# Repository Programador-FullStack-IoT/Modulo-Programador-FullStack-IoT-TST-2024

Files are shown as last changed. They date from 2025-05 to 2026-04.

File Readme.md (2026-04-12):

## PROGRAMADOR FULLSTACK - GRUPO PLATA

(https://postimg.cc/dhYZY6cm)

# OmniSens – Sistema de Monitoreo y Control Ambiental Industrial

**OmniSens** es un sistema orientado al monitoreo y control ambiental en entornos industriales. Utiliza sensores para medir variables críticas como temperatura, humedad, presión y luminosidad, y transmite estos datos mediante tecnología **LoRa** hacia un servidor en la nube, permitiendo monitoreo y gestión en tiempo real.

---

## 🧑‍💻 Integrantes

| Nombre | GitHub |
|---|---|
| Fernando Gimenez Coria | [@FerCbr](https://github.com/FerCbr) |
| Paola Pantoja | [@PaolaaPantoja](https://github.com/PaolaaPantoja) |
| Diego Ares | [@diegote7](https://github.com/diegote7) |
| Emma Vilma Gutierrez | [@emygut](https://github.com/emygut) |
| Macarena Aylèn Carballo | [@MacarenaAC](https://github.com/MacarenaAC) |
| Romina Vanesa Huk | [@RoHu17](https://github.com/RoHu17) |
| Juan Diego Gonzalez Antoniazzi | [@JDGA1997](https://github.com/JDGA1997) |
| Leandro Roldan | [@pleroldan](https://github.com/pleroldan) |
| Raul Jara | [@r-j28](https://github.com/r-j28) |
---

## 👨‍🏫 Profesores

| Nombre                       |
|------------------------------|
| Mario Gonzalez               | 
| Jorge Morales                | 
| Ana Farias                   |
| Dante Violi                  |

## Descripción General

El objetivo principal de OmniSens es implementar un sistema integral capaz de mantener condiciones óptimas de ambiente, garantizando la seguridad y calidad del aire. Para ello, el sistema incluye una serie de **controladores edge** que reciben los datos de los sensores y accionan dispositivos como extractores de aire, luces, alarmas sonoras y balizas luminosas.  
Las acciones de los controladores edge buscan regular parámetros ambientales: por ejemplo, ajustar la velocidad de extractores/ventiladores, la intensidad de luces, o activar alarmas cuando los valores de gases o variables ambientales sobrepasen los límites establecidos.

Los controladores edge se comunican mediante un enlace LoRa hacia otro controlador encargado de funcionar como **nodo concentrador**, formando una red de tipo estrella.  
Este **nodo concentrador** envia a su vez todos datos recolectados a un **broker MQTT** remoto para su posterior analisis y almacenamiento. Esta arquitectura otorga la posibilidad de implementar analisis de datos a nivel de edge, permitiendo reaccionar a variables criticas con baja latencia, sin dejar de lado el procesamiento en la nube, que se encarga de almacenar todos los sucesos y tambien enviar ordenes a los controladores Edge.   

Toda la información recolectada se analiza en un servidor remoto y es almacenada en una base de datos configurada para este fin, luego se procede a mostrar la informacion en un dashboard. Este diseño permite visualizar la informacion procesada a vez que puese enviar ordenes automaticas o comandos indicados por el usuario.

## Objetivo del Proyecto

Desarrollar un sistema capaz de:
- Monitorear variables ambientales (temperatura, humedad, presión, luminosidad, gases) en tiempo real.
- Controlar dispositivos para mantener condiciones ambientales dentro de los parámetros de seguridad y calidad.
- Automatizar acciones correctivas (ventilación, iluminación, alarmas) ante condiciones anómalas.
- Registrar, almacenar y visualizar los datos históricos y en tiempo real para facilitar la toma de decisiones.

---

## Arquitectura del Sistema  

(https://postimg.cc/Bjz5Hy85)

El sistema está compuesto por:
- **Sensores ambientales**: Medición de variables críticas.  
- **Actuadores**: Dispositivos tales como Extractores/ventiladores, relay o contactores para comando on/off, balizas y alarmas sonoras
- **Microcontroladores Edge con LoRa**: Son los encargados de tomar la informacion de los sensores y procesar variables criticas que requieran baja latencia, ademas envian la informacion adquirida por enlace LoRa hacia el concentrador.
- **Concentrador Lora**: Controlador encargado de recibir los datos provenientes de los controladores Edge. Recibe la información y la envia por MQTT al **broker remoto**, ademas se encarga de ditribuir los comandos provenientes del servidor remoto hacia los **Controladores Edge** para accionar los actuadores.  
- **Servidor remoto**: Este servidor cumple las funciones de plataforma en la nube, cuenta con varios contenedores docker conectados en una red virtual. La lista de contenedores es la siguiente:  
    - **Broker MQTT**: recepcion de los datos provenientes del Edge y envio de comandos hacia los controladores edge  
    - **API**: Recibe los datos del broker MQTT y los procesa para autenticar y autorizar a los dispositivos y usuarios.  
    - **Node-red**: recibe los datos de la API y los procesa para analizar y tomar decisiones. Ademas, envía las reacciones a los actuadores a través de MQTT y almacena los datos y resultados de analisis en una base de datos.  
    - **Base de datos**: Aqui se almacena la informacion de los sensores, asi como los analisis realizados por Node-RED para su posterior visualizacion.  
    - **Grafana**: Grafana se utiliza para crear el dashboard encargado de mostrar los datos historicos y en tiempo real del sistema.
- **Interfaz web o dashboard**: Monitoreo y control centralizado.  

### Flujo de Datos

1. Los sensores captan variables ambientales.
2. Los datos viajan por LoRa a un microcontrolador concentrador, que se encarga a la vez de enviarlos por MQTT a un servidor remoto
3. El servidor analiza y devuelve ordenes para que los **Controladores Edge** accionen los actuadores.
4. El servidor almacena y muestra los datos en tiempo real, permitiendo monitoreo remoto y acciones automáticas.

---

## Estructura del Repositorio

```
OmniSens/
├── README.md
├── LICENSE
├── docs/
│   ├── architecture.md
│   ├── device-specs.md
│   ├── integration.md
│   └── roadmap.md
├── hub/
│   ├── backend/
│   └── frontend/
├── devices/
│   ├── sensores/
│   └── actuadores/
├── edge/
│   ├── microcontrolador-sensado/
│   ├── microcontrolador-receptor/
│   └── microcontrolador-actuador/
├── configs/
├── deployments/
└── tests/
```

---

## Integración y Escalabilidad

El proyecto está pensado para aprovechar y escalar a partir de prototipos y códigos de años anteriores, integrando nuevas funcionalidades y adaptándose a distintas necesidades industriales. Se fomenta la colaboración y la mejora continua.

---

## Hoja de Ruta (Roadmap)

El desarrollo de OmniSens se organiza en las siguientes fases:

### Fase 1: Prototipo Funcional de Sensado y Control
- [ ] Diseño y armado de red básica de sensores (temperatura, humedad, presión, luminosidad, gases).
- [ ] Configuración de comunicación LoRa entre microcontroladores (sensado, receptor y actuador).
- [ ] Implementación de control básico de actuadores (extractores, luces, alarmas).
- [ ] Documentación de arquitectura y conexiones en `docs/architecture.md`.

### Fase 2: Backend y Base de Datos
- [ ] Desarrollo del backend (`hub/backend/`) para recibir y almacenar datos.
- [ ] Configuración y pruebas de la base de datos.
- [ ] Documentación de la API y endpoints en `docs/integration.md`.

### Fase 3: Dashboard e Interfaz Web
- [ ] Desarrollo del frontend (`hub/frontend/`) para visualización y control.
- [ ] Implementación de monitoreo en tiempo real y registro histórico.
- [ ] Integración de acciones de control remoto desde el dashboard.

### Fase 4: Integración y Pruebas
- [ ] Integración de módulos (`edge`, `devices`, `hub`).
- [ ] Pruebas de funcionamiento en entorno simulado o real.
- [ ] Ajustes y mejoras tras feedback de pruebas.

### Fase 5: Documentación y Escalado
- [ ] Completar la documentación técnica en `docs/`.
- [ ] Publicar guías de instalación y uso para todos los módulos.
- [ ] Planificar siguientes iteraciones (nuevos sensores, protocolos, expansiones).

---
# Omnisens
---
## 🧭 1. Introducción y Problemática

**OmniSens** es un sistema de monitoreo y control ambiental industrial desarrollado por estudiantes del módulo **Programador FullStack IoT** del ISPC. Este proyecto integra tecnologías de hardware, software y comunicaciones para adquirir, almacenar, visualizar y actuar sobre datos ambientales críticos en tiempo real.

En entornos industriales, controlar variables como la **temperatura**, **humedad**, **presión atmosférica** y **luminosidad** es fundamental para garantizar la seguridad operativa, la eficiencia energética y el cumplimiento de normativas. Sin embargo, muchas industrias carecen de sistemas inteligentes que permitan:

- 📉 Monitoreo en tiempo real de las condiciones ambientales.
- ⚠️ Detección temprana de riesgos operativos.
- 📄 Registro y trazabilidad de datos históricos.
- 📊 Análisis automatizado y toma de decisiones basada en datos.
- 🚫 Evitar decisiones basadas en intuición o registros incompletos.

Ante este contexto, **OmniSens** surge como una solución tecnológica que permite:

- Capturar datos desde sensores distribuidos mediante nodos IoT (ESP32).
- Transmitir los datos a través de redes como **LoRa** y **WiFi** usando protocolos como **MQTT**.
- Almacenarlos de forma estructurada en una base de datos relacional.
- Visualizarlos y analizarlos en dashboards en tiempo real mediante herramientas como **Grafana** y **NodeRed**
- Generar alertas automáticas y activar actuadores ante condiciones críticas.

El proyecto busca resolver necesidades concretas del sector industrial, promoviendo el desarrollo de competencias profesionales como la integración de sistemas embebidos, la conectividad IoT, la gestión de datos y la visualización inteligente.

> "OmniSens nace para transformar datos ambientales en decisiones inteligentes, aportando valor real a la industria a través de la tecnología."

---
## 🧱 2. Diseño de Arquitectura IoT

El sistema OmniSens está basado en una arquitectura IoT distribuida y escalable, compuesta por sensores físicos, nodos de adquisición (ESP32), un gateway central, servicios backend y plataformas de visualización. Su diseño busca asegurar confiabilidad, modularidad y bajo consumo energético.

### 🔧 Componentes principales de la arquitectura:

- **Sensores ambientales**: capturan variables como temperatura, humedad, presión y luminosidad.
- **Microcontroladores ESP32**: actúan como nodos sensores, adquiriendo y transmitiendo los datos.
- **Red de comunicación**: se utilizan tecnologías inalámbricas como **LoRa** (para distancias largas y bajo consumo) y **WiFi** (para conectividad local con el servidor).
- **Broker MQTT**: intermedia la comunicación entre nodos y backend.
- **Servidor Backend**: recibe, valida y almacena los datos en una base relacional (MySQL/MariaDB).
- **Base de datos**: registra las mediciones por timestamp, dispositivo y variable.
- **Dashboard de visualización**: mediante **Grafana** o/y **Node-Red**, permite observar en tiempo real el estado ambiental.

---
### 🧩 Diagrama lógico de la arquitectura:

plaintext
[Sensores] 
    -> 
[ESP32 (Nodo Sensor)] 
    -> LoRa / WiFi 
[Gateway MQTT / Servidor] 
    -> 
[Base de Datos MySQL] 
    -> 
[Dashboard (Grafana / Power BI)]

---
## 🔧 3. Adquisición de Datos (ESP32 + Sensores)

La etapa de adquisición de datos en el sistema OmniSens se basa en la utilización de microcontroladores **ESP32**, que permiten la conexión directa con sensores ambientales y la recolección de datos físicos en tiempo real.

### 🔍 Variables monitoreadas:
- 🌡️ **Temperatura**
- 💧 **Humedad relativa**
- 🌀 **Presión atmosférica**
- 💡 **Luminosidad**
- 🕯️ **Concentracion de gases/ calidad de aire**

### 🛠️ Componentes utilizados:
- **Sensores digitales y analógicos**:
  - AHT25 → temperatura y humedad
  - BMP280 → presión y temperatura
  - LDR → luminosidad
  - MQ135 → Calidad de aire
    
- **Microcontrolador**:
  - ESP32 (con conectividad WiFi y/o LoRa)

### ⚙️ Flujo de funcionamiento:
1. Los sensores capturan datos del entorno físico.
2. El ESP32 lee las señales de los sensores a través de sus entradas GPIO.
3. El firmware del ESP32 convierte los datos a formato digital y los estructura en mensajes JSON.
4. Los datos se transmiten vía WiFi o LoRa hacia el backend o gateway.

### 🧪 Validación y pruebas realizadas:
- Lectura y calibración de cada sensor.
- Verificación del formato y frecuencia de los datos.
- Simulación de condiciones ambientales para validar variabilidad.
- Comprobación del consumo energético por nodo.

### 📌 Ventajas de usar ESP32:
- Bajo consumo energético.
- Capacidad de procesamiento local.
- Conectividad múltiple: WiFi, Bluetooth, LoRa (mediante módulos).
- Compatibilidad con entornos industriales y educativos.

> Esta etapa permite digitalizar el entorno físico y convertir condiciones ambientales en datos útiles, siendo el punto de partida del sistema de monitoreo y control de OmniSens.

---
## 📡 4. Comunicación Inalámbrica

La transmisión de datos en OmniSens se realiza mediante redes inalámbricas optimizadas para entornos industriales. Se utilizan dos tecnologías principales: **LoRa** y **WiFi**, complementadas por el protocolo **MQTT** para la mensajería entre dispositivos y el servidor.

### 🛰️ Tecnologías de comunicación utilizadas:

- **LoRa (Long Range)**:
  - Permite comunicación de largo alcance con bajo consumo energético.
  - Ideal para entornos con múltiples nodos distribuidos o con baja infraestructura de red.
  - Se utiliza principalmente entre nodos sensores y el nodo receptor (gateway).

- **WiFi**:
  - Usado en el nodo central para conectarse a internet y enviar los datos al backend.
  - Permite alta velocidad de transmisión y bajo retardo.

- **MQTT (Message Queuing Telemetry Transport)**:
  - Protocolo ligero ideal para IoT.
  - Permite que los dispositivos **publiquen** datos en un “topic” y que el servidor **se suscriba** para recibirlos.
  - Asegura eficiencia en redes de bajo ancho de banda y con múltiples dispositivos.

### 🔄 Flujo de comunicación:

[ESP32 Nodo Sensor]
  -> LoRa
[ESP32 Nodo Receptor / Gateway]
  -> MQTT sobre WiFi
[Broker MQTT]
  ->
[Servidor Backend]

---
## 🖥️ 5. Backend y Base de Datos

El backend del sistema OmniSens cumple un rol central en la recepción, validación, almacenamiento y organización de los datos ambientales enviados por los nodos sensores.

### 🔙 Funciones principales del backend:

- Recibir datos desde los nodos mediante MQTT.
- Validar formato, integridad y valores de los datos.
- Registrar eventos o comandos generados por el sistema.
- Almacenar toda la información en una base de datos relacional.
- Exponer APIs para futuras integraciones con dashboards u otros servicios.

### 🗄️ Modelo de Base de Datos Relacional

Se diseñó una base de datos optimizada para registrar información ambiental por dispositivo y variable. Las tablas principales son:

| Tabla | Propósito |
|---|---|
| `devices` | Registra cada ESP32 con su ID, tipo y ubicación. |
| `sensor_data` | Almacena las mediciones de variables con timestamp. |
| `commands_log` | Guarda las acciones o respuestas generadas por el sistema (automatizaciones). |
| `alerts` *(opcional)* | Registra alertas generadas por condiciones críticas. |

#### 🔗 Relaciones entre tablas:
- `devices.device_id` → se relaciona con `sensor_data.device_id` y `commands_log.device_id`
- `sensor_data.id` → puede relacionarse con `alerts.sensor_data_id`

### 📈 Ventajas del diseño:

- Escalable a nuevos sensores y tipos de variables.
- Compatible con visualizadores como Grafana y Node-Red.
- Preparado para trazabilidad, alertas y análisis histórico.

> Este backend permite que los datos ambientales capturados por los sensores se conviertan en información estructurada, confiable y accesible para su posterior visualización y análisis.

---
## 📊 6. Visualización Web / Dashboard

La visualización de datos es el paso final del sistema OmniSens, donde la información almacenada en la base de datos es transformada en gráficos, paneles e indicadores comprensibles para facilitar la toma de decisiones.

### 📊 Integración con Node-RED y Grafana

### Node-RED
* Permite crear flujos lógicos para procesar, transformar y reenviar datos provenientes de sensores conectados vía MQTT.

🔧 Funcionalidades implementadas

* Recepción de datos desde ESP32 por MQTT.
* Filtrado y reenvío de datos a MariaDB.
* Reglas de control automático
* Flujo: MQTT → procesamiento → UI → actuador.
* Ruta: `/nodered_plata/ui/`: [Dashboard UI](http://telecomunicaciones.ddns.net:8080/nodered_plata/ui/#!/0)
* Incluye botones para control manual, recepción de datos, lógica de automatización.

### Grafana

* Plataforma de visualización en tiempo real, conectada directamente a la base de datos MariaDB.
* Dashboards visuales conectados a base de datos.
* Panel con temperatura, gas, humedad y estado de actuadores.
* Ruta directa:
  [Dashboard público](http://telecomunicaciones.ddns.net:8080/grafana/public-dashboards/edbcf99f6c3e44a68703f5246ecef087)

---

### 🧭 Objetivos de la visualización:

- Representar variables ambientales críticas de forma clara y dinámica.
- Permitir monitoreo en tiempo real de sensores distribuidos.
- Detectar tendencias, anomalías o condiciones fuera de rango.
- Mejorar el mantenimiento, la eficiencia energética y la seguridad operativa.
- Facilitar el análisis por parte de diferentes perfiles de usuarios (técnicos, operativos, directivos).

### 🧱 Estructura del panel:

El dashboard se organiza en múltiples secciones:

1. **Vista general de variables**:
   - Temperatura, humedad, presión y luminosidad por dispositivo.
   - Estado actual, valores máximos y mínimos recientes.
2. **Medicion por eventos de valores en crudo**:
3. **Conteo de cantidad de dispositivos**:
4. **Históricos y tendencias**:
5. **Estado de sensores y actuadores**:
6. **Promedios** 
7. **Actividad de los reles**
8. **Identificador de dispositivos**

> La visualización convierte datos técnicos en información útil y clara, permitiendo interpretar el comportamiento ambiental y tomar decisiones informadas en entornos industriales.

---
## 🤖 7. Automatización y Control (Actuadores)

Además de monitorear el ambiente, el sistema OmniSens es capaz de **actuar automáticamente** ante condiciones críticas, gracias a la integración de actuadores controlados desde el backend o en forma autónoma por los nodos.

### ⚙️ Objetivos del control automatizado:

- Generar respuestas inmediatas ante variables fuera de rango.
- Activar dispositivos que mejoren las condiciones ambientales.
- Reducir la necesidad de intervención humana.
- Aumentar la seguridad y eficiencia operativa.

### 🔌 Tipos de actuadores posibles:

- 🌀 Ventiladores / extractores de aire.
- 💡 Luces de advertencia o balizas.
- 🔔 Alarmas sonoras.
- 💧 Válvulas o bombas de agua.
- 🌡️ Aire acondicionado o calefactores.

### 🔁 Lógica de automatización:

El sistema puede actuar de dos formas:

#### 1. **Automatización local en ESP32** (Opcional. no se implemento): 
- El ESP32 analiza el dato leído y, si supera un umbral, activa directamente el actuador conectado.
- Ejemplo: si `temperatura > 30°C`, activar ventilador.

#### 2. **Automatización centralizada desde el backend**:
- El servidor recibe los datos y decide activar o no un actuador según reglas definidas.
- Se envía un comando vía MQTT al nodo actuador correspondiente.

### 🗂️ Registro de acciones:

- Cada acción ejecutada se guarda en la tabla `commands_log`, con información como:
  - `device_id`
  - `command` (ej. "ON", "OFF")
  - `timestamp`
  - `status`

### 🧪 Validación y pruebas:

- Ensayos de latencia entre detección y acción.
- Pruebas con sensores simulados y actuadores reales.
- Comprobación de fallos: qué ocurre si el actuador no responde.

> La automatización convierte al sistema en una herramienta activa, no solo de monitoreo, sino también de respuesta inteligente ante condiciones que afectan el ambiente de trabajo.

---
## 📅 8. Cronograma y Proceso de Desarrollo

El desarrollo del proyecto OmniSens se organizó en etapas, siguiendo una planificación basada en objetivos específicos y acciones técnicas. Esto permitió avanzar de forma progresiva, validando cada componente del sistema antes de integrarlo.

### 📌 Organización por semanas

| Etapa | Objetivo principal | Acciones realizadas |
|---|---|---|
| **Etapa 1** | Diseñar la arquitectura | - Análisis de necesidades del sistema<br>- Selección de topología IoT<br>- Definición de roles: sensores, nodos, gateway, servidor<br>- Primeros diagramas de arquitectura |
| **Etapa  2** | Adquisición de datos | - Conexión de sensores al ESP32<br>- Programación de firmware básico<br>- Pruebas de lectura y calibración<br>- Validación de datos físicos |
| **Etapa  3** | Comunicación inalámbrica | - Configuración de red LoRa y WiFi<br>- Implementación de MQTT/<br>- Pruebas de transmisión nodo → servidor<br>- Ajustes de cobertura y latencia |
| **Etapa  4** | Backend y base de datos | - Diseño de la base de datos relacional<br>- Creación de APIs de recepción<br>- Almacenamiento de datos desde nodos<br>- Gestión de errores y alertas |
| **Etapa  5** | Visualización y pruebas finales | - Diseño del dashboard (Grafana / Node-Red)<br>- Conexión al backend y base de datos<br>- Visualización de datos en tiempo real<br>- Revisión, ajustes y documentación final |

### 🛠️ Metodología aplicada:

- Trabajo colaborativo entre 9 integrantes, con roles distribuidos.
- Validación continua en cada etapa (sensado, transmisión, backend, visualización).
- Uso de control de versiones (GitHub) para gestionar avances y código.
- Documentación técnica elaborada de forma simultánea al desarrollo.

### 📈 Resultados destacados:

- Se logró un sistema funcional y escalable.
- Todas las etapas del ciclo de vida de los datos fueron cubiertas: captura, transmisión, almacenamiento, análisis y visualización.
- Se presentaron avances periódicos en cada instancia del módulo FullStack IoT.

> El trabajo organizado y en equipo fue clave para alcanzar un producto sólido, demostrando competencias técnicas y metodológicas aplicadas al desarrollo de sistemas IoT reales.

---
## ✅ 9. Conclusión, Aplicaciones y Cierre

OmniSens es el resultado de un trabajo colaborativo y multidisciplinario que integra tecnologías de IoT, comunicaciones, desarrollo de software y análisis de datos para resolver una problemática concreta del ámbito industrial: la necesidad de monitorear y controlar variables ambientales de forma precisa y en tiempo real, optimizando el sistema, brindando soluciones reales ejecutando acciones o actividades   lo mas desatendidas y seguras posibles. 

### 🎯 Logros alcanzados:

- Desarrollo de un sistema completo y funcional.
- Integración de sensores físicos y nodos ESP32 con conectividad LoRa/WiFi.
- Implementación de un backend capaz de recibir, validar y almacenar datos.
- Construcción de dashboards interactivos para visualización en tiempo real.
- Automatización de respuestas ante condiciones críticas.
- Trabajo en equipo con documentación técnica, planificación y uso de herramientas profesionales.

### 🏭 Posibles aplicaciones reales:

- **Industria manufacturera**: monitoreo ambiental en líneas de producción.
- **Centros educativos o de investigación**: como plataforma de aprendizaje IoT.
- **Agricultura inteligente**: control ambiental en invernaderos o hidroponía.
- **Municipios**: estaciones ambientales urbanas para políticas públicas.
- **Cooperativas o pymes**: bajo costo, alta utilidad para la toma de decisiones.

### 🌱 Impacto del proyecto:

- Promueve la **conciencia ambiental industrial**.
- Desarrolla habilidades reales del perfil técnico FullStack IoT.
- Facilita la **transferencia tecnológica** a contextos locales.
- Aporta una solución escalable, replicable y con impacto social.

### 🧠 Reflexión final:

> “OmniSens no solo mide condiciones ambientales. Permite que la industria tome decisiones más inteligentes, eficientes y sostenibles. Nos permitió aplicar conocimientos concretos de arquitectura IoT, plataformas web, sistemas de control y gestión de datos, demostrando cómo la tecnología puede mejorar entornos reales.”

---
## Licencia

Este proyecto se encuentra bajo la Licencia MIT. Consulta el archivo LICENSE para más detalles.

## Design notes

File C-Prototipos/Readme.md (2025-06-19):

## PROGRAMADOR FULLSTACK - GRUPO PLATA

(https://postimg.cc/dhYZY6cm)

# OmniSens – Sistema de Monitoreo y Control Ambiental Industrial

**OmniSens** es un sistema orientado al monitoreo y control ambiental en entornos industriales. Utiliza sensores para medir variables críticas como temperatura, humedad, presión y luminosidad, y transmite estos datos mediante tecnología **LoRa** hacia un servidor en la nube, permitiendo monitoreo y gestión en tiempo real.

---

## 🧑‍💻 Integrantes

| Nombre | GitHub |
|---|---|
| Fernando Gimenez Coria | [@FerCbr](https://github.com/FerCbr) |
| Paola Pantoja | [@PaolaaPantoja](https://github.com/PaolaaPantoja) |
| Diego Ares | [@diegote7](https://github.com/diegote7) |
| Emma Vilma Gutierrez | [@emygut](https://github.com/emygut) |
| Macarena Aylèn Carballo | [@MacarenaAC](https://github.com/MacarenaAC) |
| Romina Vanesa Huk | [@RoHu17](https://github.com/RoHu17) |
| Juan Diego Gonzalez Antoniazzi | [@JDGA1997](https://github.com/JDGA1997) |
| Leandro Roldan | [@pleroldan](https://github.com/pleroldan) |
| Raul Jara | [@r-j28](https://github.com/r-j28) |
---

## 👨‍🏫 Profesores

| Nombre | GitHub |
|---|---|
| Mario Gonzalez | [@mariogonzalezispc](https://github.com/mariogonzalezispc) |
| Jorge Morales | [@JorEl057](https://github.com/JorEl057) |
| Alejandro Mainero | []() |

## Descripción General

El objetivo principal de OmniSens es implementar un sistema integral capaz de mantener condiciones óptimas de ambiente, garantizando la seguridad y calidad del aire. Para ello, el sistema incluye una serie de **controladores edge** que reciben los datos de los sensores y accionan dispositivos como extractores de aire, luces, alarmas sonoras y balizas luminosas.  
Las acciones de los controladores edge buscan regular parámetros ambientales: por ejemplo, ajustar la velocidad de extractores/ventiladores, la intensidad de luces, o activar alarmas cuando los valores de gases o variables ambientales sobrepasen los límites establecidos.

Los controladores edge se comunican mediante un enlace LoRa hacia otro controlador encargado de funcionar como **nodo concentrador**, formando una red de tipo estrella.  
Este **nodo concentrador** envia a su vez todos datos recolectados a un **broker MQTT** remoto para su posterior analisis y almacenamiento. Esta arquitectura otorga la posibilidad de implementar analisis de datos a nivel de edge, permitiendo reaccionar a variables criticas con baja latencia, sin dejar de lado el procesamiento en la nube, que se encarga de almacenar todos los sucesos y tambien enviar ordenes a los controladores Edge.   

Toda la información recolectada se analiza en un servidor remoto y es almacenada en una base de datos configurada para este fin, luego se procede a mostrar la informacion en un dashboard. Este diseño permite visualizar la informacion procesada a su vez que puede enviar ordenes automaticas o comandos indicados por el usuario.

El proyecto busca aprovechar prototipos y desarrollos previos, adaptando y escalando el enfoque hacia la gestión ambiental industrial. Además, se promueve el trabajo colaborativo y la comunicación de avances con los profesores para su evaluación.

---
## 🧭 1. Introducción y Problemática

**OmniSens** es un sistema de monitoreo y control ambiental industrial desarrollado por estudiantes del módulo **Programador FullStack IoT** del ISPC. Este proyecto integra tecnologías de hardware, software y comunicaciones para adquirir, almacenar, visualizar y actuar sobre datos ambientales críticos en tiempo real.

En entornos industriales, controlar variables como la **temperatura**, **humedad**, **presión atmosférica** y **luminosidad** es fundamental para garantizar la seguridad operativa, la eficiencia energética y el cumplimiento de normativas. Sin embargo, muchas industrias carecen de sistemas inteligentes que permitan:

- 📉 Monitoreo en tiempo real de las condiciones ambientales.
- ⚠️ Detección temprana de riesgos operativos.
- 📄 Registro y trazabilidad de datos históricos.
- 📊 Análisis automatizado y toma de decisiones basada en datos.
- 🚫 Evitar decisiones basadas en intuición o registros incompletos.

Ante este contexto, **OmniSens** surge como una solución tecnológica que permite:

- Capturar datos desde sensores distribuidos mediante nodos IoT (ESP32).
- Transmitir los datos a través de redes como **LoRa** y **WiFi** usando protocolos como **MQTT**.
- Almacenarlos de forma estructurada en una base de datos relacional.
- Visualizarlos y analizarlos en dashboards en tiempo real mediante herramientas como **Grafana** y **NodeRed**
- Generar alertas automáticas y activar actuadores ante condiciones críticas.

El proyecto busca resolver necesidades concretas del sector industrial, promoviendo el desarrollo de competencias profesionales como la integración de sistemas embebidos, la conectividad IoT, la gestión de datos y la visualización inteligente.

> "OmniSens nace para transformar datos ambientales en decisiones inteligentes, aportando valor real a la industria a través de la tecnología."

---
## 🧱 2. Diseño de Arquitectura IoT

El sistema OmniSens está basado en una arquitectura IoT distribuida y escalable, compuesta por sensores físicos, nodos de adquisición (ESP32), un gateway central, servicios backend y plataformas de visualización. Su diseño busca asegurar confiabilidad, modularidad y bajo consumo energético.

### 🔧 Componentes principales de la arquitectura:

- **Sensores ambientales**: capturan variables como temperatura, humedad, presión y luminosidad.
- **Microcontroladores ESP32**: actúan como nodos sensores, adquiriendo y transmitiendo los datos.
- **Red de comunicación**: se utilizan tecnologías inalámbricas como **LoRa** (para distancias largas y bajo consumo) y **WiFi** (para conectividad local con el servidor).
- **Broker MQTT**: intermedia la comunicación entre nodos y backend.
- **Servidor Backend**: recibe, valida y almacena los datos en una base relacional (MySQL/MariaDB).
- **Base de datos**: registra las mediciones por timestamp, dispositivo y variable.
- **Dashboard de visualización**: mediante **Grafana** o/y **Node-Red**, permite observar en tiempo real el estado ambiental.

---
### 🧩 Diagrama lógico de la arquitectura:

plaintext
[Sensores] 
    ↓ 
[ESP32 (Nodo Sensor)] 
    ↓ LoRa / WiFi 
[Gateway MQTT / Servidor] 
    ↓ 
[Base de Datos MySQL] 
    ↓ 
[Dashboard (Grafana / Power BI)]

---
## 🔧 3. Adquisición de Datos (ESP32 + Sensores)

La etapa de adquisición de datos en el sistema OmniSens se basa en la utilización de microcontroladores **ESP32**, que permiten la conexión directa con sensores ambientales y la recolección de datos físicos en tiempo real.

### 🔍 Variables monitoreadas:
- 🌡️ **Temperatura**
- 💧 **Humedad relativa**
- 🌀 **Presión atmosférica**
- 💡 **Luminosidad**

### 🛠️ Componentes utilizados:
- **Sensores digitales y analógicos**:
  - DHT11 → temperatura y humedad
  - BMP280 → presión
  - BH1750 → luminosidad
- **Microcontrolador**:
  - ESP32 (con conectividad WiFi y/o LoRa)

### ⚙️ Flujo de funcionamiento:
1. Los sensores capturan datos del entorno físico.
2. El ESP32 lee las señales de los sensores a través de sus entradas GPIO.
3. El firmware del ESP32 convierte los datos a formato digital y los estructura en mensajes JSON.
4. Los datos se transmiten vía WiFi o LoRa hacia el backend o gateway.

### 🧪 Validación y pruebas realizadas:
- Lectura y calibración de cada sensor.
- Verificación del formato y frecuencia de los datos.
- Simulación de condiciones ambientales para validar variabilidad.
- Comprobación del consumo energético por nodo.

### 📌 Ventajas de usar ESP32:
- Bajo consumo energético.
- Capacidad de procesamiento local.
- Conectividad múltiple: WiFi, Bluetooth, LoRa (mediante módulos).
- Compatibilidad con entornos industriales y educativos.

> Esta etapa permite digitalizar el entorno físico y convertir condiciones ambientales en datos útiles, siendo el punto de partida del sistema de monitoreo y control de OmniSens.

---
## 📡 4. Comunicación Inalámbrica

La transmisión de datos en OmniSens se realiza mediante redes inalámbricas optimizadas para entornos industriales. Se utilizan dos tecnologías principales: **LoRa** y **WiFi**, complementadas por el protocolo **MQTT** para la mensajería entre dispositivos y el servidor.

### 🛰️ Tecnologías de comunicación utilizadas:

- **LoRa (Long Range)**:
  - Permite comunicación de largo alcance con bajo consumo energético.
  - Ideal para entornos con múltiples nodos distribuidos o con baja infraestructura de red.
  - Se utiliza principalmente entre nodos sensores y el nodo receptor (gateway).

- **WiFi**:
  - Usado en el nodo central para conectarse a internet y enviar los datos al backend.
  - Permite alta velocidad de transmisión y bajo retardo.

- **MQTT (Message Queuing Telemetry Transport)**:
  - Protocolo ligero ideal para IoT.
  - Permite que los dispositivos **publiquen** datos en un “topic” y que el servidor **se suscriba** para recibirlos.
  - Asegura eficiencia en redes de bajo ancho de banda y con múltiples dispositivos.

### 🔄 Flujo de comunicación:

plaintext
[ESP32 Nodo Sensor]
  ↓ LoRa
[ESP32 Nodo Receptor / Gateway]
  ↓ MQTT sobre WiFi
[Broker MQTT]
  ↓
[Servidor Backend]

---
## 🖥️ 5. Backend y Base de Datos

El backend del sistema OmniSens cumple un rol central en la recepción, validación, almacenamiento y organización de los datos ambientales enviados por los nodos sensores.

### 🔙 Funciones principales del backend:

- Recibir datos desde los nodos mediante HTTP o MQTT.
- Validar formato, integridad y valores de los datos.
- Registrar eventos o comandos generados por el sistema.
- Almacenar toda la información en una base de datos relacional.
- Exponer APIs para futuras integraciones con dashboards u otros servicios.

### 🧩 Arquitectura del backend:

- **Lenguaje/entorno**: Node.js
- **Servidor web/API**: Express
- **Base de datos**: MariaDB / MySQL
- **Gestión de datos**: Sequelize u ORM nativo
- **Contenedores**: Docker (opcional, según implementación)

### 🗄️ Modelo de Base de Datos Relacional

Se diseñó una base de datos optimizada para registrar información ambiental por dispositivo y variable. Las tablas principales son:

| Tabla | Propósito |
|---|---|
| `devices` | Registra cada ESP32 con su ID, tipo y ubicación. |
| `sensor_data` | Almacena las mediciones de variables con timestamp. |
| `commands_log` | Guarda las acciones o respuestas generadas por el sistema (automatizaciones). |
| `alerts` *(opcional)* | Registra alertas generadas por condiciones críticas. |

#### 🔗 Relaciones entre tablas:
- `devices.device_id` → se relaciona con `sensor_data.device_id` y `commands_log.device_id`
- `sensor_data.id` → puede relacionarse con `alerts.sensor_data_id`

### 🧪 Validaciones implementadas:

- Comprobación de rangos válidos (ej.: temperatura entre -40 °C y 85 °C).
- Eliminación de registros duplicados.
- Control de campos nulos o mal formateados.
- Registro de errores y eventos especiales.

### 📈 Ventajas del diseño:

- Escalable a nuevos sensores y tipos de variables.
- Compatible con visualizadores como Grafana y Power BI.
- Preparado para trazabilidad, alertas y análisis histórico.

> Este backend permite que los datos ambientales capturados por los sensores se conviertan en información estructurada, confiable y accesible para su posterior visualización y análisis.

---
## 📊 6. Visualización Web / Dashboard

La visualización de datos es el paso final del sistema OmniSens, donde la información almacenada en la base de datos es transformada en gráficos, paneles e indicadores comprensibles para facilitar la toma de decisiones.

## 📊 Integración con Node-RED y Grafana

### Node-RED

* Flujo: MQTT → procesamiento → UI → actuador.
* Ruta: `/nodered_plata/ui/`: [Dashboard UI](http://telecomunicaciones.ddns.net:8080/nodered_plata/ui/#!/0)
* Incluye botones para control manual, recepción de datos, lógica de automatización.

### Grafana

* Plataforma de visualización en tiempo real, conectada directamente a la base de datos MySQL.
* Dashboards visuales conectados a base de datos.
* Panel con temperatura, gas, humedad y estado de actuadores.
* Ruta directa:
  [Dashboard público](http://telecomunicaciones.ddns.net:8080/grafana/public-dashboards/edbcf99f6c3e44a68703f5246ecef087)

---

### 🧭 Objetivos de la visualización:

- Representar variables ambientales críticas de forma clara y dinámica.
- Permitir monitoreo en tiempo real de sensores distribuidos.
- Detectar tendencias, anomalías o condiciones fuera de rango.
- Mejorar el mantenimiento, la eficiencia energética y la seguridad operativa.
- Facilitar el análisis por parte de diferentes perfiles de usuarios (técnicos, operativos, directivos).

### 🧱 Estructura del panel:

El dashboard se organiza en múltiples secciones:

1. **Vista general de variables**:
   - Temperatura, humedad, presión y luminosidad por dispositivo.
   - Estado actual, valores máximos y mínimos recientes.

2. **Panel comparativo por sectores o nodos**:
   - Comparación de valores entre ubicaciones o dispositivos.

3. **Alertas y condiciones críticas**:
   - Visualización de alertas activas por umbrales excedidos.

4. **Históricos y tendencias**:
   - Gráficos de evolución temporal de cada variable.
   - Filtros por fecha, nodo o variable.

5. **Indicadores clave (KPIs)**:
   - Promedios, máximos/mínimos diarios.
   - Cantidad de alertas, condiciones óptimas mantenidas, etc.

### 🔗 Conexión de datos:

- **Grafana**: se conecta directamente a la base MySQL mediante consultas SQL configuradas por variable y tabla.
- **Power BI**: importa los datos desde MySQL o desde archivos exportados, permitiendo modelado, limpieza y relaciones personalizadas.

> La visualización convierte datos técnicos en información útil y clara, permitiendo interpretar el comportamiento ambiental y tomar decisiones informadas en entornos industriales.

---
## 🤖 7. Automatización y Control (Actuadores)

Además de monitorear el ambiente, el sistema OmniSens es capaz de **actuar automáticamente** ante condiciones críticas, gracias a la integración de actuadores controlados desde el backend o en forma autónoma por los nodos.

### ⚙️ Objetivos del control automatizado:

- Generar respuestas inmediatas ante variables fuera de rango.
- Activar dispositivos que mejoren las condiciones ambientales.
- Reducir la necesidad de intervención humana.
- Aumentar la seguridad y eficiencia operativa.

### 🔌 Tipos de actuadores posibles:

- 🌀 Ventiladores / extractores de aire.
- 💡 Luces de advertencia o balizas.
- 🔔 Alarmas sonoras.
- 💧 Válvulas o bombas de agua.
- 🌡️ Aire acondicionado o calefactores.

### 🔁 Lógica de automatización:

El sistema puede actuar de dos formas:

#### 1. **Automatización local en ESP32**:
- El ESP32 analiza el dato leído y, si supera un umbral, activa directamente el actuador conectado.
- Ejemplo: si `temperatura > 30°C`, activar ventilador.

#### 2. **Automatización centralizada desde el backend**:
- El servidor recibe los datos y decide activar o no un actuador según reglas definidas.
- Se envía un comando vía MQTT/HTTP al nodo actuador correspondiente.

### 🗂️ Registro de acciones:

- Cada acción ejecutada se guarda en la tabla `commands_log`, con información como:
  - `device_id`
  - `command` (ej. "ON", "OFF")
  - `timestamp`
  - `status`

### 🧪 Validación y pruebas:

- Ensayos de latencia entre detección y acción.
- Pruebas con sensores simulados y actuadores reales.
- Comprobación de fallos: qué ocurre si el actuador no responde.

### 🔒 Seguridad:

- Se pueden establecer reglas para evitar activaciones innecesarias.
- Control de prioridad y bloqueo si hay condiciones simultáneas.

> La automatización convierte al sistema en una herramienta activa, no solo de monitoreo, sino también de respuesta inteligente ante condiciones que afectan el ambiente de trabajo.

---
## 📅 8. Cronograma y Proceso de Desarrollo

El desarrollo del proyecto OmniSens se organizó en etapas semanales, siguiendo una planificación basada en objetivos específicos y acciones técnicas. Esto permitió avanzar de forma progresiva, validando cada componente del sistema antes de integrarlo.

### 📌 Organización por semanas

| Semana | Objetivo principal | Acciones realizadas |
|---|---|---|
| **Semana 1** | Diseñar la arquitectura | - Análisis de necesidades del sistema<br>- Selección de topología IoT<br>- Definición de roles: sensores, nodos, gateway, servidor<br>- Primeros diagramas de arquitectura |
| **Semana 2** | Adquisición de datos | - Conexión de sensores al ESP32<br>- Programación de firmware básico<br>- Pruebas de lectura y calibración<br>- Validación de datos físicos |
| **Semana 3** | Comunicación inalámbrica | - Configuración de red LoRa y WiFi<br>- Implementación de MQTT/HTTP<br>- Pruebas de transmisión nodo → servidor<br>- Ajustes de cobertura y latencia |
| **Semana 4** | Backend y base de datos | - Diseño de la base de datos relacional<br>- Creación de APIs de recepción<br>- Almacenamiento de datos desde nodos<br>- Gestión de errores y alertas |
| **Semana 5** | Visualización y pruebas finales | - Diseño del dashboard (Grafana / Power BI)<br>- Conexión al backend y base de datos<br>- Visualización de datos en tiempo real<br>- Revisión, ajustes y documentación final |

### 🛠️ Metodología aplicada:

- Trabajo colaborativo entre 9 integrantes, con roles distribuidos.
- Validación continua en cada etapa (sensado, transmisión, backend, visualización).
- Uso de control de versiones (GitHub) para gestionar avances y código.
- Documentación técnica elaborada de forma simultánea al desarrollo.

### 📈 Resultados destacados:

- Se logró un sistema funcional y escalable.
- Todas las etapas del ciclo de vida de los datos fueron cubiertas: captura, transmisión, almacenamiento, análisis y visualización.
- Se presentaron avances periódicos en cada instancia del módulo FullStack IoT.

> El trabajo organizado y en equipo fue clave para alcanzar un producto sólido, demostrando competencias técnicas y metodológicas aplicadas al desarrollo de sistemas IoT reales.

---
## ✅ 9. Conclusión, Aplicaciones y Cierre

OmniSens es el resultado de un trabajo colaborativo y multidisciplinario que integra tecnologías de IoT, comunicaciones, desarrollo de software y análisis de datos para resolver una problemática concreta del ámbito industrial: la necesidad de monitorear y controlar variables ambientales de forma precisa y en tiempo real.

### 🎯 Logros alcanzados:

- Desarrollo de un sistema completo y funcional.
- Integración de sensores físicos y nodos ESP32 con conectividad LoRa/WiFi.
- Implementación de un backend capaz de recibir, validar y almacenar datos.
- Construcción de dashboards interactivos para visualización en tiempo real.
- Automatización de respuestas ante condiciones críticas.
- Trabajo en equipo con documentación técnica, planificación y uso de herramientas profesionales.

### 🏭 Posibles aplicaciones reales:

- **Industria manufacturera**: monitoreo ambiental en líneas de producción.
- **Centros educativos o de investigación**: como plataforma de aprendizaje IoT.
- **Agricultura inteligente**: control ambiental en invernaderos o hidroponía.
- **Municipios**: estaciones ambientales urbanas para políticas públicas.
- **Cooperativas o pymes**: bajo costo, alta utilidad para la toma de decisiones.

### 🌱 Impacto del proyecto:

- Promueve la **conciencia ambiental industrial**.
- Desarrolla habilidades reales del perfil técnico FullStack IoT.
- Facilita la **transferencia tecnológica** a contextos locales.
- Aporta una solución escalable, replicable y con impacto social.

### 🧠 Reflexión final:

> “OmniSens no solo mide condiciones ambientales. Permite que la industria tome decisiones más inteligentes, eficientes y sostenibles. Nos permitió aplicar conocimientos concretos de arquitectura IoT, plataformas web, sistemas de control y gestión de datos, demostrando cómo la tecnología puede mejorar entornos reales.”

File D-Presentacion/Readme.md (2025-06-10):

# OmniSens: Plataforma de Monitoreo Ambiental IoT



OmniSens es una plataforma integral de monitoreo ambiental basada en IoT, diseñada para recolectar, almacenar y visualizar datos de diversos sensores. La plataforma está compuesta por dispositivos de borde (nodos sensores), un concentrador LoRa, una API de backend, una base de datos y un panel de visualización en Grafana.

Este proyecto ha sido desarrollado como parte del Módulo Full Stack IoT de la Tecnicatura Superior en Telecomunicaciones del ISPC.

---

## 📜 Tabla de Contenidos

1.  [📝 Resumen del Proyecto](#-resumen-del-proyecto)
2.  [🚀 Estado del Proyecto](#-estado-del-proyecto)
3.  [🛠️ Tecnologias Utilizadas](#-tecnologias-utilizadas)
4.  [📋 Requisitos Previos](#-requisitos-previos)
5.  [⚙️ Instalación](#-instalación)
6.  [🔧 Configuración](#-configuración)
7.  [▶️ Uso](#-uso)
8.  [🔌 Referencia de la API](#-referencia-de-la-api)
9. [🤝 Cómo Contribuir](#-cómo-contribuir)

---

## 📝 Resumen del Proyecto

El proyecto OmniSens tiene como objetivo principal monitorear la calidad del aire y otras variables ambientales utilizando una red de sensores IoT. Los datos son transmitidos a través de LoRa a un concentrador que los envía a un backend mediante MQTT. Finalmente, la información se almacena en una base de datos MySQL y se visualiza en tiempo real en un dashboard de Grafana.

### Características Principales

* **Comunicación Inalámbrica de Largo Alcance:** Utiliza LoRa para la comunicación entre los nodos sensores y el concentrador.
* **Protocolo Ligero:** Emplea MQTT para una comunicación eficiente entre el hardware y el backend.
* **API Robusta:** Un backend desarrollado en Node.js con Express para gestionar los datos y la lógica de negocio.
* **Almacenamiento Persistente:** Base de datos MySQL para el almacenamiento de los datos de los sensores.
* **Visualización en Tiempo Real:** Dashboard en Grafana para el monitoreo interactivo de las variables.
* **Arquitectura Escalable:** Diseño modular que permite añadir nuevos sensores y funcionalidades fácilmente.

---

## 🚀 Estado del Proyecto

**Activo**. El proyecto está en desarrollo activo y se están añadiendo nuevas funcionalidades. No hay una hoja de ruta pública definida, pero se planea continuar mejorando la plataforma.

---

## 🛠️ Tecnologías Utilizadas

### Backend

* **Node.js:** Entorno de ejecución para JavaScript del lado del servidor.
* **Express.js:** Framework web para construir la API REST.
* **mysql2:** Cliente de MySQL para Node.js, utilizado para la interacción con la base de datos.
* **mqtt.js:** Cliente MQTT para la comunicación con el concentrador.
* **dotenv:** Para la gestión de variables de entorno.
* **Helmet:** Para asegurar la aplicación Express estableciendo varias cabeceras HTTP.

### Frontend y Visualización

* **Grafana:** Plataforma de código abierto para la visualización y análisis de datos.

### Dispositivos Embebidos (Edge)

* **C++:** Lenguaje principal para la programación de los microcontroladores.
* **PlatformIO:** Ecosistema de desarrollo para software embebido.
* **ESP32 y ESP8266:** Microcontroladores utilizados para los nodos sensores y el concentrador.
* **LoRa (RadioLib):** Librería para la comunicación LoRa.
* **Sensores:**
    * **AHT25/AHT10:** Temperatura y humedad.
    * **BMP280:** Presión atmosférica.
    * **MQ135:** Calidad del aire (CO2, etc.).
    * **BH1750/GY-302:** Intensidad lumínica.

### Base de Datos

* **MySQL:** Sistema de gestión de bases de datos relacional.

---

## 📋 Requisitos Previos

Asegúrate de tener instalado el siguiente software antes de empezar:

* **Node.js:** v18 o superior.
* **NPM:** Gestor de paquetes de Node.js (normalmente se instala con Node.js).
* **PlatformIO Core:** Para compilar y subir el firmware a los dispositivos.
* **Docker (Recomendado):** Para levantar fácilmente el stack de backend (MySQL, Grafana, etc.).
* **Un cliente de MySQL:** Como MySQL Workbench o DBeaver (opcional).

---

## ⚙️ Instalación

1.  **Clonar el repositorio:**
    ```bash
    git clone [https://github.com/Programador-FullStack-IoT/Modulo-Programador-FullStack-IoT-TST-2024.git](https://github.com/Programador-FullStack-IoT/Modulo-Programador-FullStack-IoT-TST-2024.git)
    cd Modulo-Programador-FullStack-IoT-TST-2024
    ```

2.  **Instalar dependencias del Backend:**
    ```bash
    cd C-Prototipos/OmniSens/API\ (nueva)/
    npm install
    ```

3.  **Instalar librerías de PlatformIO:**
    PlatformIO instalará automáticamente las dependencias de las librerías al compilar los proyectos embebidos.

---

## 🔧 Configuración

### Backend

1.  Navega al directorio de la API: `C-Prototipos/OmniSens/API (nueva)/`.
2.  Crea un archivo `.env` a partir del archivo `.env.example` (si existiera). Basado en el código fuente (`src/config/index.js`), las variables de entorno necesarias son:
    ```env
    # Credenciales de la Base de Datos
    DB_HOST=localhost
    DB_USER=root
    DB_PASSWORD=tu_contraseña_secreta
    DB_DATABASE=OmniSens
    DB_PORT=3306

    # Configuración del Broker MQTT
    MQTT_BROKER=mqtt://localhost:1883
    MQTT_USERNAME=usuario_mqtt
    MQTT_PASSWORD=contraseña_mqtt

    # Puerto de la API
    PORT=3000
    ```

3.  **Base de Datos:**
    * Asegúrate de tener un servidor MySQL en ejecución.
    * Crea una base de datos llamada `OmniSens`.
    * Importa el esquema de la base de datos desde el archivo `C-Prototipos/OmniSens/Base de datos/OmniSens.sql`.

### Dispositivos Embebidos

Cada prototipo en `C-Prototipos/` tiene su propio archivo `platformio.ini` que define la configuración específica del hardware (pines, librerías, etc.). Asegúrate de revisar estos archivos antes de compilar y subir el firmware.

---

## ▶️ Uso

### Backend

Para iniciar el servidor de la API, ejecuta el siguiente comando desde el directorio `C-Prototipos/OmniSens/API (nueva)/`:

npm start

### Dispositivos Embebidos

1.  Abre el proyecto deseado (por ejemplo, `C-Prototipos/OmniSens/docs/Edge/controlador_edge/Omnisens_AQC/`) en VSCode con la extensión de PlatformIO.
2.  Conecta el dispositivo (ESP32) a tu computadora.
3.  Utiliza los comandos de PlatformIO para compilar y subir el firmware.

---

## 🔌 Referencia de la API

La API REST gestiona los dispositivos y los datos de los sensores.

### Endpoints de Dispositivos (`/api/devices`)

* **`GET /`**: Obtiene una lista de todos los dispositivos.
* **`POST /`**: Crea un nuevo dispositivo.
    * **Body:** `{ "location": "string" }`
* **`GET /:id`**: Obtiene un dispositivo por su ID.
* **`PUT /:id`**: Actualiza un dispositivo por su ID.
    * **Body:** `{ "location": "string" }`
* **`DELETE /:id`**: Elimina un dispositivo por su ID.

### Endpoints de Datos de Sensores (`/api/sensor-data`)

* **`POST /`**: Guarda nuevos datos de sensores. Este endpoint es utilizado por el broker MQTT para registrar la telemetría.
    * **Body:** `{ "device_id": "int", "sensor_type": "string", "value": "float" }`

---

## 🤝 Cómo Contribuir

Las contribuciones son bienvenidas. Si deseas contribuir, por favor sigue estos pasos:

1.  Haz un "fork" del repositorio.
2.  Crea una nueva rama para tu funcionalidad (`git checkout -b feature/nueva-funcionalidad`).
3.  Realiza tus cambios y haz "commit" de ellos (`git commit -am 'Añade nueva funcionalidad'`).
4.  Empuja tus cambios a tu rama (`git push origin feature/nueva-funcionalidad`).
5.  Crea un nuevo "Pull Request".

Asegúrate de que tu código siga las guías de estilo del proyecto y de que todas las pruebas pasen.

---

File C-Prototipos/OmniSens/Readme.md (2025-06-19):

# 📂 Prototipo Principal: **OmniSens**

La carpeta `OmniSens` contiene el código fuente y la documentación del prototipo funcional principal del proyecto. Integra todos los componentes clave:

- **Dispositivos de borde** (sensores y concentrador)
- **Backend** (API)
- **Base de datos**
- **Capa de visualización**

---

## 🏗️ Arquitectura del Prototipo

El flujo de trabajo de este prototipo es el siguiente:

1. **Nodo Sensor (Edge Controller)**
    - Microcontrolador **ESP32** con múltiples sensores.
    - Captura datos ambientales.

2. **Comunicación LoRa**
    - El Nodo Sensor envía los datos al Concentrador usando LoRa.

3. **Concentrador LoRa (Hub)**
    - Otro **ESP32** que recibe la información de los nodos.
    - Procesa y publica los datos en un tópico específico de un **broker MQTT**.

4. **Backend (API)**
    - Servicio **Node.js** suscrito al tópico MQTT.
    - Procesa y almacena los datos en **MySQL**.

5. **Base de Datos**
    - Almacena información de dispositivos y lecturas de sensores.

6. **Visualización**
    - Un dashboard (Grafana) conectado a la base de datos muestra los datos en tiempo real.

---

## 📦 Componentes

A continuación, se detalla el contenido de cada subcarpeta principal dentro de `C-Prototipos/OmniSens`:

---

### **API (nueva)/**
Contiene el código fuente del servidor backend.

- **Tecnología:** Node.js
- **Framework:** Express.js
- **Funcionalidad Principal:**
  - API REST para gestión de dispositivos (`/api/devices`)
  - Conexión a broker MQTT para recibir telemetría
  - Uso de `mysql2` para interactuar con MySQL
- **Punto de Entrada:** `server.js`
- **Estructura del Código:**
  - `src/controllers`: Lógica de solicitudes HTTP
  - `src/routes`: Definición de rutas de la API
  - `src/service`: Lógica de negocio (servicios de base de datos y MQTT)

---

### **Base de datos/**
Define la estructura de la base de datos del proyecto.

- **Archivo Principal:** `OmniSens.sql`
- **Descripción:** Script SQL que crea la base de datos y define las tablas principales:

  | Tabla        | Descripción                                 | Campos Principales                                      |
  |--------------|---------------------------------------------|---------------------------------------------------------|
  | `devices`    | Registro de dispositivos IoT                | `id`, `location`, `createdAt`, `updatedAt`              |
  | `sensordata` | Lecturas de sensores                        | `id`, `device_id`, `sensor_type`, `value`, `timestamp`  |

---

### **docs/Edge/**
Contiene el firmware para los dispositivos embebidos (PlatformIO).

- **concentrador_LoRa/**
  - **Hardware:** Heltec WiFi LoRa 32
  - **Responsabilidades:**
     - Inicializa LoRa para recibir datos
     - Conexión WiFi y MQTT (PubSubClient)
     - Deserializa paquetes LoRa (JSON) y publica en MQTT

- **controlador_edge/**
  - **Hardware:** ESP32 (NodeMCU-32S)
  - **Sensores Integrados:**
     - **AHT25:** Humedad y Temperatura
     - **BMP280:** Presión atmosférica
     - **MQ135:** Calidad del Aire (CO₂)
  - **Responsabilidades:**
     - Lectura de sensores
     - Empaquetado de datos en JSON
     - Envío de datos por LoRa al concentrador

- **controlador_edge_2/**
  - **Hardware:** ESP8266 (NodeMCU-12E)
  - **Sensores Integrados:**
     - **BH1750:** Luminosidad
     - **DHT11:** Humedad y Temperatura
  - **Responsabilidades:**
     - Lectura de sensores
     - Empaquetado de datos en JSON
     - Envío de datos por LoRa al concentrador

- **concentrador_LoRa_2/**
  - **Hardware:** Heltec WiFi LoRa 32
  - **Responsabilidades:**
     - Inicializa LoRa para recibir datos
     - Conexión WiFi y MQTT (PubSubClient)
     - Deserializa paquetes LoRa (JSON) y publica en MQTT

## 📂 Estructura del directorio

```
Omnisens/docs/Edge/
├── sensor-edge/         # Código para nodo sensor (ESP32)
├── gateway-edge/        # Código para gateway LoRa-MQTT
├── actuator-edge/       # Código para actuadores (salidas GPIO)
└── README.md            # Documentación actual
```

### 🧰 Software

* [PlatformIO](https://platformio.org/)
* Repositorio clonado:

  ```bash
  git clone https://github.com/Programador-FullStack-IoT/Modulo-Programador-FullStack-IoT-TST-2024.git
  ```
* Docker con servicios activos (ver Portainer):
  🕻 [http://telecomunicaciones.ddns.net:8080/portainer/#!/3/docker/containers](http://telecomunicaciones.ddns.net:8080/portainer/#!/3/docker/containers)

---

### 🔧 Hardware

* Módulos ESP32, LoRa SX1278
* Sensores (temperatura, gas, humedad)
* Actuadores (relés, LED, motores)
* Cableado y protoboard

  ### 🌐 Servicios desplegados

* **Portainer**: [Contenedores activos](http://telecomunicaciones.ddns.net:8080/portainer/#!/3/docker/containers)
* **Node-RED (grupo Plata)**: [Dashboard UI](http://telecomunicaciones.ddns.net:8080/nodered_plata/ui/#!/0)
* **Grafana (Grupo Plata)**: [Panel Público](http://telecomunicaciones.ddns.net:8080/grafana/public-dashboards/51aba874b6f44eff8c361c8ffdba9956)

  ### 🔀 Flujo de datos

1. El sensor transmite vía LoRa al gateway.
2. El gateway reenvía datos al broker MQTT.
3. Node-RED suscribe datos y los visualiza.
4. Grafana extrae métricas de la base de datos.
5. Node-RED también emite comandos a los actuadores.

---

## 📊 Integración con Node-RED y Grafana

### Node-RED

* Flujo: MQTT → procesamiento → UI → actuador.
* Ruta: `/nodered_plata/ui/`: [Dashboard UI](http://telecomunicaciones.ddns.net:8080/nodered_plata/ui/#!/0)
* Incluye botones para control manual, recepción de datos, lógica de automatización.

### Grafana

* Dashboards visuales conectados a base de datos.
* Panel con temperatura, gas, humedad y estado de actuadores.
* Ruta directa:
  [Dashboard público](http://telecomunicaciones.ddns.net:8080/grafana/public-dashboards/edbcf99f6c3e44a68703f5246ecef087)

---

## ✅ Checklist de puesta en marcha

1. Clonar repositorio.
2. Instalar PlatformIO y dependencias.
3. Flashear nodos sensor y actuador.
4. Levantar contenedores Docker (ya disponibles en Portainer).
5. Confirmar flujo MQTT → Node‑RED → Grafana.
6. Validar comandos de actuación vía UI.

   ## 📢 Contacto

**Grupo Plata - Tecnicatura en Telecomunicaciones**
Repositorio: [OmniSens - FullStack IoT](https://github.com/Programador-FullStack-IoT/Modulo-Programador-FullStack-IoT-TST-2024)
Soporte: vía canal de clase o issues del repositorio.

> ℹ️ **Explora cada carpeta para más detalles sobre la implementación y configuración de cada componente.**

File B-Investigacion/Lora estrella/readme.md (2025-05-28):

# Comunicación LoRa con ESP32: Nodo Central y Dos Nodos Emisores

Este documento describe cómo configurar una red básica LoRa entre tres módulos ESP32 con chips LoRa SX1278, donde dos dispositivos actúan como emisores (nodos A y B) y uno como receptor central. El sistema permite ingresar mensajes desde el terminal y recibir un acuse de recibido ("ACK") desde el nodo central.

---

## Esquema de Conexión del SX1278 al ESP32

| SX1278 | ESP32 GPIO |
|---|---|
| MISO | 19 |
| MOSI | 23 |
| SCK | 18 |
| NSS/CS | 5 |
| RST | 14 |
| DIO0 | 2 |

---

## Flujo de Comunicación

1. El usuario escribe un mensaje en el monitor serial de un nodo emisor.
2. El mensaje se envía por LoRa al nodo central, incluyendo un identificador.
3. El nodo central recibe, imprime el mensaje y responde con un acuse ("ACK").
4. El nodo emisor muestra el acuse en el monitor serial.

---

## Código del Nodo Emisor A

```cpp
// Nodo A
// Identificador: "A"

#include <SPI.h>
#include <LoRa.h>

// Pines de conexión
#define SS 5
#define RST 14
#define DIO0 2
#define NODE_ID "A"

// Mensaje ingresado por terminal
String inputMessage = "";

void setup() {
  Serial.begin(9600);
  while (!Serial);

  // Configura pines y frecuencia
  LoRa.setPins(SS, RST, DIO0);
  if (!LoRa.begin(433E6)) {
    Serial.println("Fallo al iniciar LoRa");
    while (1);
  }
  Serial.println("Nodo A listo. Escribe un mensaje y presiona ENTER:");
}

void loop() {
  // Leer entrada del usuario desde el terminal
  if (Serial.available()) {
    inputMessage = Serial.readStringUntil('\n');
    String message = String(NODE_ID) + ":" + inputMessage;

    // Enviar el mensaje
    LoRa.beginPacket();
    LoRa.print(message);
    LoRa.endPacket();
    Serial.println("Mensaje enviado: " + message);
  }

  // Esperar un acuse de recibido del nodo central
  int packetSize = LoRa.parsePacket();
  if (packetSize) {
    String ack = "";
    while (LoRa.available()) {
      ack += (char)LoRa.read();
    }
    Serial.println("Acuse recibido: " + ack);
  }
}
```

---

## Código del Nodo Emisor B

```cpp
// Nodo B
// Identificador: "B"

#include <SPI.h>
#include <LoRa.h>

// Pines de conexión
#define SS 5
#define RST 14
#define DIO0 2
#define NODE_ID "B"

// Mensaje ingresado por terminal
String inputMessage = "";

void setup() {
  Serial.begin(9600);
  while (!Serial);

  // Configura pines y frecuencia
  LoRa.setPins(SS, RST, DIO0);
  if (!LoRa.begin(433E6)) {
    Serial.println("Fallo al iniciar LoRa");
    while (1);
  }
  Serial.println("Nodo B listo. Escribe un mensaje y presiona ENTER:");
}

void loop() {
  // Leer entrada del usuario desde el terminal
  if (Serial.available()) {
    inputMessage = Serial.readStringUntil('\n');
    String message = String(NODE_ID) + ":" + inputMessage;

    // Enviar el mensaje
    LoRa.beginPacket();
    LoRa.print(message);
    LoRa.endPacket();
    Serial.println("Mensaje enviado: " + message);
  }

  // Esperar un acuse de recibido del nodo central
  int packetSize = LoRa.parsePacket();
  if (packetSize) {
    String ack = "";
    while (LoRa.available()) {
      ack += (char)LoRa.read();
    }
    Serial.println("Acuse recibido: " + ack);
  }
}
```

---

## Código del Nodo Central (Receptor)

```cpp
// Nodo central receptor (Gateway)

#include <SPI.h>
#include <LoRa.h>

// Pines de conexión
#define SS 5
#define RST 14
#define DIO0 2

void setup() {
  Serial.begin(9600);
  while (!Serial);

  // Inicializa LoRa
  LoRa.setPins(SS, RST, DIO0);
  if (!LoRa.begin(433E6)) {
    Serial.println("Fallo al iniciar LoRa");
    while (1);
  }
  Serial.println("Receptor central iniciado");
}

void loop() {
  // Esperar mensaje
  int packetSize = LoRa.parsePacket();
  if (packetSize) {
    String incoming = "";
    while (LoRa.available()) {
      incoming += (char)LoRa.read();
    }

    Serial.println("Mensaje recibido: " + incoming);

    // Extraer ID del nodo (carácter inicial antes del ':')
    String nodeId = incoming.substring(0, 1);
    String ack = "ACK:" + nodeId;

    // Esperar un momento y enviar acuse
    delay(100);
    LoRa.beginPacket();
    LoRa.print(ack);
    LoRa.endPacket();
    Serial.println("Acuse enviado a Nodo " + nodeId);
  }
}
```

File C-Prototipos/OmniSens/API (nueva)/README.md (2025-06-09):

# API OmniSens

Esta API RESTful permite la consulta de datos y el envío de comandos a dispositivos IoT integrados en la plataforma OmniSens.

**URL Base:** `https://<host>:<puerto>/api` (Ej: `https://localhost:3000/api`)

---

## Tabla de Contenidos
- [Arquitectura General](#arquitectura-general)
- [Guía Rápida de Despliegue](#guía-rápida-de-despliegue)
- [Endpoints de Dispositivos](#endpoints-de-dispositivos-devices)
- [Endpoints de Usuarios y Métricas para Grafana](#endpoints-de-usuarios-y-métricas-para-grafana)
- [Ejemplos de Payloads Avanzados](#ejemplos-de-payloads-avanzados)
- [Ejemplos de Scripts de Prueba](#ejemplos-de-scripts-de-prueba)
- [Autenticación](#autenticación)
- [Preguntas Frecuentes (FAQ)](#preguntas-frecuentes-faq)
- [Recursos y Enlaces Útiles](#recursos-y-enlaces-útiles)

---

## Arquitectura General

```mermaid
flowchart TD
    subgraph Usuario
      A1[Navegador/Cliente]
    end
    subgraph API[API OmniSens (Express + HTTPS)]
      B1[Endpoints REST]
      B2[Middleware Seguridad]
      B3[MQTT Service]
      B4[DB Service]
    end
    subgraph IoT[Dispositivos IoT]
      C1[ESP32/NodeMCU]
    end
    subgraph Broker[Broker MQTT (MQTTS)]
      D1[Broker MQTT]
    end
    subgraph DB[Base de Datos MariaDB]
      E1[Tabla Measurements]
    end
    A1-->|HTTPS|B1
    B1-->|Comandos/Consultas|B3
    B1-->|Consultas|B4
    B3-->|MQTTS|D1
    D1-->|MQTTS|C1
    C1-->|MQTTS|D1
    D1-->|MQTTS|B3
    B4-->|SQL|E1
    E1-->|Datos|B4
```

---

## Guía Rápida de Despliegue

1. **Clona el repositorio y entra a la carpeta de la API:**
   ```sh
   git clone <url-del-repo>
   cd C-Prototipos/OmniSens/API\ (nueva)
   ```
2. **Instala las dependencias:**
   ```sh
   npm install
   ```
3. **Configura el archivo `.env`:**
   - Copia el ejemplo y ajusta las variables según tu entorno (broker, DB, etc).
4. **Agrega los certificados SSL en la carpeta `certs/`:**
   - `key.pem` y `cert.pem` para el servidor HTTPS.
   - `broker-ca.pem` para la conexión MQTTS.
5. **Inicia el servidor:**
   ```sh
   npm start
   ```
6. **Prueba la API:**
   - Accede a `https://localhost:3000/api/devices` para verificar funcionamiento.

---

## Endpoints de Dispositivos (`/devices`)

### 1. Listar todos los dispositivos
- **GET** `/devices`
- Devuelve un array de objetos con los `device_id` únicos.

### 2. Obtener datos de un dispositivo específico
- **GET** `/devices/:deviceId/data?limit=N`
- Devuelve los últimos N registros de medición para el dispositivo.

### 3. Enviar un comando a un dispositivo
- **POST** `/devices/:deviceId/command`
- Cuerpo JSON:
  ```json
  {
    "actuator": "led_azul",
    "value": 1
  }
  ```

---

## Endpoints de Usuarios y Métricas para Grafana

- **GET /api/users/count**
  - Devuelve la cantidad total de usuarios registrados.
  - Respuesta: `{ "count": 42 }`

- **GET /api/users**
  - Devuelve el listado de usuarios.
  - Respuesta: `{ "users": [ { "id": 1, "username": "juan", "created_at": "2025-06-09T10:00:00Z" }, ... ] }`

- **GET /api/users/new?from=YYYY-MM-DD&to=YYYY-MM-DD**
  - Devuelve la cantidad de usuarios creados en el rango de fechas especificado.
  - Respuesta: `{ "count": 3 }`

Estos endpoints pueden ser consultados desde Grafana para mostrar:
- api_users(Cantidad usuarios)
- api_users(usuarios)
- api_users(Nuevos usuarios)

---

## Ejemplos de Payloads Avanzados

### Ejemplo de datos recibidos de un dispositivo
```json
{
  "temperature": 23.7,
  "humidity": 58.2,
  "co2": 420,
  "pm25": 12.5,
  "voc": 0.03,
  "battery": 87
}
```

### Ejemplo de comando avanzado
```json
{
  "actuator": "ventilador",
  "value": "auto",
  "params": {
    "minTemp": 22,
    "maxTemp": 28,
    "duration": 300
  }
}
```

---

## Ejemplos de Scripts de Prueba

### Usando `curl`

- **Listar dispositivos:**
  ```sh
  curl -k -H "x-api-key: <tu_clave_secreta_aqui>" https://localhost:3000/api/devices
  ```
- **Obtener datos de un dispositivo:**
  ```sh
  curl -k -H "x-api-key: <tu_clave_secreta_aqui>" "https://localhost:3000/api/devices/esp32-01/data?limit=5"
  ```
- **Enviar comando:**
  ```sh
  curl -k -X POST https://localhost:3000/api/devices/esp32-01/command \
    -H "x-api-key: <tu_clave_secreta_aqui>" \
    -H "Content-Type: application/json" \
    -d '{"actuator":"led_azul","value":1}'
  ```

### Usando Node.js (axios)

```js
const axios = require('axios');
process.env.NODE_TLS_REJECT_UNAUTHORIZED = '0'; // Solo para pruebas locales

axios.post('https://localhost:3000/api/devices/esp32-01/command', {
  actuator: 'ventilador',
  value: 'auto',
  params: { minTemp: 22, maxTemp: 28, duration: 300 }
}, {
  headers: { 'x-api-key': '<tu_clave_secreta_aqui>' }
})
.then(res => console.log(res.data))
.catch(err => console.error(err.response?.data || err));
```

---

## Autenticación

Todas las rutas requieren una API Key enviada en la cabecera HTTP `x-api-key`.

- **Cabecera requerida:**
  ```
  x-api-key: <tu_clave_secreta_aqui>
  ```
- Si la clave es incorrecta o falta, la API responde con `401 Unauthorized`.
- Configura tu clave en el archivo `.env` con la variable `API_KEY`.

---

## Preguntas Frecuentes (FAQ)

**¿Qué pasa si un dispositivo no responde a un comando?**
- La API solo garantiza que el comando fue publicado en el broker MQTT. No puede asegurar la ejecución en el dispositivo.

**¿Cómo agrego nuevos sensores o campos?**
- Asegúrate de que la tabla `Measurements` en la base de datos tenga las columnas necesarias y que el firmware del dispositivo envíe los datos en el JSON.

**¿Puedo usar HTTP en vez de HTTPS?**
- No, por seguridad la API solo expone el puerto HTTPS.

**¿Cómo puedo ver los logs de la API?**
- Los logs se muestran en la consola donde se ejecuta el servidor. Para producción, se recomienda integrar un sistema de logging.

**¿Qué hago si la API no conecta con el broker o la base de datos?**
- Verifica las variables de entorno, la red y los certificados. Consulta los mensajes de error en la consola.

---

## Recursos y Enlaces Útiles
- [Documentación MQTT](https://mqtt.org/documentation)
- [Express.js](https://expressjs.com/)
- [MariaDB](https://mariadb.org/)
- [Mermaid Live Editor](https://mermaid.live/) (para visualizar diagramas)

---

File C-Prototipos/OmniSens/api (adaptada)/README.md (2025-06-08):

# OmniSens API

API RESTful para la gestión de dispositivos IoT, almacenamiento de datos de sensores y envío de comandos vía MQTT.

---

## Tabla de Contenidos
- [Introducción](#introducción)
- [Instalación y Configuración](#instalación-y-configuración)
- [Autenticación](#autenticación)
- [Rutas de la API](#rutas-de-la-api)
- [Ejemplos de Uso](#ejemplos-de-uso)
- [Modelo de Base de Datos](#modelo-de-base-de-datos)
- [Integración MQTT](#integración-mqtt)
- [Diagramas](#diagramas)
- [Preguntas Frecuentes (FAQ)](#preguntas-frecuentes-faq)
- [Glosario](#glosario)
- [Guía Rápida de Despliegue](#guía-rápida-de-despliegue)

---

## Introducción
OmniSens API permite interactuar con dispositivos IoT, consultar datos históricos de sensores y enviar comandos a través de MQTT. Es ideal para proyectos de monitoreo ambiental, automatización y prototipos educativos.

**URL Base:** `http://localhost:3000/api`

---

## Instalación y Configuración

1. Clona el repositorio y entra en la carpeta `api`:
   ```sh
   git clone <repo_url>
   cd C-Prototipos/OmniSens/api
   ```
2. Instala las dependencias:
   ```sh
   npm install
   ```
3. Copia el archivo `.env` de ejemplo y configura tus variables:
   ```sh
   cp .env.example .env
   # Edita .env con tus credenciales y configuración
   ```
4. Inicia el servidor:
   ```sh
   npm start
   # o en modo desarrollo
   npm run dev
   ```

---

## Autenticación

Todas las rutas requieren una API Key enviada en la cabecera HTTP `x-api-key`.

- **Cabecera requerida:**
  ```
  x-api-key: <tu_clave_secreta_aqui>
  ```
- Si la clave es incorrecta o falta, la API responde con `401 Unauthorized`.

---

## Rutas de la API

| Método | Endpoint | Descripción |
|---|---|---|
| GET | `/devices` | Lista todos los dispositivos registrados |
| GET | `/devices/:deviceId/data` | Últimas mediciones de un dispositivo |
| POST | `/devices/:deviceId/command` | Envía un comando a un dispositivo |

---

## Ejemplos de Uso

### 1. Listar todos los dispositivos
```http
GET /api/devices
x-api-key: <tu_clave>
```
**Respuesta:**
```json
{
  "devices": [
    {
      "device_eui": "dispositivo_lora_001",
      "name": "Dispositivo dispositivo_lora_001",
      "location": null,
      "created_at": "2025-06-07T10:30:00.000Z"
    },
    {
      "device_eui": "esp32_sensor_A",
      "name": "Dispositivo esp32_sensor_A",
      "location": "Laboratorio 1",
      "created_at": "2025-06-07T11:15:00.000Z"
    }
  ]
}
```

### 2. Obtener datos de un dispositivo
```http
GET /api/devices/esp32_sensor_A/data?limit=5
x-api-key: <tu_clave>
```
**Respuesta:**
```json
{
  "data": [
    {
      "value": 25.5,
      "timestamp": "2025-06-07T12:05:10.000Z",
      "sensor_type": "temperature",
      "unit": "°C"
    },
    {
      "value": 45.2,
      "timestamp": "2025-06-07T12:05:10.000Z",
      "sensor_type": "humidity",
      "unit": "%"
    },
    {
      "value": 25.1,
      "timestamp": "2025-06-07T12:04:55.000Z",
      "sensor_type": "temperature",
      "unit": "°C"
    }
  ]
}
```

### 3. Enviar un comando a un dispositivo
```http
POST /api/devices/esp32_sensor_A/command
x-api-key: <tu_clave>
Content-Type: application/json

{
  "actuator": "led_rojo",
  "value": 1
}
```
**Respuesta:**
```json
{
  "success": true,
  "message": "Comando enviado al dispositivo esp32_sensor_A."
}
```

---

## Modelo de Base de Datos

La base de datos utiliza MariaDB/MySQL. Las tablas principales son:

- **devices**: Información de cada dispositivo (EUI, nombre, ubicación, fecha de alta).
- **sensor_types**: Tipos de sensores (ej: temperatura, humedad).
- **measurements**: Registra cada medición recibida, asociada a un dispositivo y tipo de sensor.

**Relaciones:**
- Un dispositivo puede tener múltiples mediciones.
- Cada medición está asociada a un tipo de sensor.

**Ejemplo de estructura simplificada:**
```sql
CREATE TABLE devices (
  id INT AUTO_INCREMENT PRIMARY KEY,
  device_eui VARCHAR(64) UNIQUE NOT NULL,
  name VARCHAR(128),
  location VARCHAR(128),
  created_at DATETIME DEFAULT CURRENT_TIMESTAMP
);

CREATE TABLE sensor_types (
  id INT AUTO_INCREMENT PRIMARY KEY,
  name VARCHAR(64) UNIQUE NOT NULL,
  unit VARCHAR(16)
);

CREATE TABLE measurements (
  id INT AUTO_INCREMENT PRIMARY KEY,
  device_id INT,
  sensor_type_id INT,
  value FLOAT,
  timestamp DATETIME,
  FOREIGN KEY (device_id) REFERENCES devices(id),
  FOREIGN KEY (sensor_type_id) REFERENCES sensor_types(id)
);
```

### Diagrama de relaciones (simplificado)

```
[devices] 1---* [measurements] *---1 [sensor_types]
```

- Un dispositivo puede tener muchas mediciones.
- Cada medición corresponde a un tipo de sensor.

### Ejemplo de registro en la tabla `measurements`

| id | device_id | sensor_type_id | value | timestamp |
|----|---|---|---|---|
| 1  | 2 | 1 | 25.5  | 2025-06-07 12:05:10 |
| 2  | 2 | 2 | 45.2  | 2025-06-07 12:05:10 |

---

## Integración MQTT

La API se conecta a un broker MQTT para recibir datos y enviar comandos.

### Flujo de datos

1. **Dispositivo** publica datos en el tópico MQTT: `devices/<deviceId>/data`.
2. **API** recibe el mensaje, lo valida y almacena cada campo como una medición en la base de datos.
3. **Comandos**: La API publica en `devices/<deviceId>/command` para que el dispositivo ejecute una acción.

### Ejemplo de mensaje recibido (payload MQTT):
```json
{
  "temperature": 25.5,
  "humidity": 45.2,
  "co2": 800
}
```

- El tópico típico es: `devices/<deviceId>/data`
- El backend extrae el `deviceId` del tópico y almacena cada campo como una medición.

### Ejemplo de comando publicado (payload MQTT):
```json
{
  "actuator": "led_rojo",
  "value": 1
}
```
- El tópico de comando es: `devices/<deviceId>/command`

### Ejemplo de suscripción y publicación con mosquitto

Suscribirse a los datos de un dispositivo:
```sh
mosquitto_sub -h <broker_host> -t "devices/esp32_sensor_A/data" -u <usuario> -P <password>
```

Publicar un comando manualmente:
```sh
mosquitto_pub -h <broker_host> -t "devices/esp32_sensor_A/command" -u <usuario> -P <password> -m '{"actuator":"led_rojo","value":1}'
```

---

## Diagramas

### Arquitectura General

Arquitectura General

### Flujo de Datos (Secuencia Simplificada)

```mermaid
sequenceDiagram
    participant Device as Dispositivo IoT
    participant MQTT as Broker MQTT
    participant API as API OmniSens
    participant DB as Base de Datos

    Device->>MQTT: Publica datos (devices/<deviceId>/data)
    MQTT->>API: Entrega mensaje
    API->>DB: Guarda mediciones
    API-->>Device: (opcional) Publica comando (devices/<deviceId>/command)
```

### Modelo Entidad-Relación (ER)

Modelo ER

#### Diagrama de despliegue (simplificado)

```mermaid
graph TD
  subgraph Edge
    D1[Dispositivo IoT 1]
    D2[Dispositivo IoT 2]
  end
  D1 -- MQTT --> B[Broker MQTT]
  D2 -- MQTT --> B
  B -- TCP/IP --> API[API OmniSens]
  API -- SQL --> DB[(Base de Datos)]
  API -- HTTP REST --> User[Usuario/Cliente]
```

---

## Estructura de Respuestas
- **200 OK:** Respuesta exitosa con datos solicitados.
- **400 Bad Request:** Faltan parámetros o cuerpo inválido.
- **401 Unauthorized:** API Key incorrecta o ausente.
- **404 Not Found:** No se encontraron datos para el recurso solicitado.

---

## Recomendaciones de Seguridad
- Cambia la clave `API_KEY` por una fuerte y única en tu archivo `.env`.
- No compartas tu archivo `.env` ni lo subas a repositorios públicos.
- Usa HTTPS en producción.

---

## Pruebas y Troubleshooting
- Usa herramientas como [Postman](https://www.postman.com/) o `curl` para probar los endpoints.
- Verifica que el broker MQTT esté accesible y que las credenciales sean correctas.
- Revisa los logs del servidor para mensajes de error detallados.
- Si tienes problemas de conexión a la base de datos, revisa el archivo `.env` y la configuración de red.

### Ejemplo de prueba con curl

Listar dispositivos:
```sh
curl -H "x-api-key: <tu_clave>" http://localhost:3000/api/devices
```

Obtener datos de un dispositivo:
```sh
curl -H "x-api-key: <tu_clave>" http://localhost:3000/api/devices/esp32_sensor_A/data?limit=3
```

Enviar comando:
```sh
curl -X POST -H "x-api-key: <tu_clave>" -H "Content-Type: application/json" \
  -d '{"actuator":"led_rojo","value":1}' \
  http://localhost:3000/api/devices/esp32_sensor_A/command
```

---

## Preguntas Frecuentes (FAQ)

### ¿Qué hago si recibo un error 401?
Verifica que estés enviando la cabecera `x-api-key` con la clave correcta. Consulta el archivo `.env` para la clave configurada.

### ¿Cómo agrego un nuevo tipo de sensor?
Envía datos con una nueva clave (por ejemplo, `"luminosity": 123`) y la API lo registrará automáticamente en la tabla `sensor_types`.

### ¿Puedo usar la API desde Postman o Insomnia?
Sí, solo asegúrate de incluir la cabecera `x-api-key` en cada solicitud.

### ¿Cómo pruebo la conexión MQTT?
Utiliza herramientas como `mosquitto_pub` y `mosquitto_sub` para publicar y suscribirte a tópicos manualmente. Ejemplos incluidos arriba.

### ¿Dónde encuentro ejemplos de payloads?
En la sección [Integración MQTT](#integración-mqtt) y en los ejemplos de uso.

### ¿Qué hago si la API no conecta con la base de datos?
Verifica los datos de conexión en `.env`, que el servicio de base de datos esté activo y que el usuario tenga permisos.

### ¿Cómo puedo extender la API?
Consulta la documentación interna en `docs/` y sigue la estructura de controladores y servicios.

---

## Glosario

- **MQTT**: Protocolo ligero de mensajería para IoT.
- **EUI**: Identificador único extendido de dispositivo.
- **Payload**: Carga útil de datos enviada en un mensaje.
- **Broker**: Servidor que enruta mensajes MQTT entre clientes.
- **API Key**: Clave secreta para autenticar solicitudes a la API.
- **Edge**: Dispositivos en el borde de la red (sensores, actuadores).

---

## Guía Rápida de Despliegue

1. Clona el repositorio y configura el archivo `.env` con tus credenciales.
2. Asegúrate de tener una base de datos MariaDB/MySQL accesible y el broker MQTT funcionando.
3. Instala dependencias con `npm install`.
4. Ejecuta migraciones SQL si es necesario (`omnisens_schema.sql`).
5. Inicia la API con `npm start` o `npm run dev`.
6. Prueba la API con Postman, curl o desde tu frontend.

---

## Recursos y Créditos
- [Documentación MQTT](https://mqtt.org/documentation)
- [Documentación Express.js](https://expressjs.com/)
- [Documentación MySQL/MariaDB](https://mariadb.com/kb/en/documentation/)

### Documentación adicional
- [docs/arquitectura.md](../docs/arquitectura.md): Arquitectura general del sistema
- [docs/integracion.md](../docs/integracion.md): Integración de dispositivos y ejemplos avanzados
- [docs/Edge-Devices.md](../docs/Edge-Devices.md): Especificaciones de hardware y firmware

Desarrollado por el equipo de Programador FullStack IoT - ISPC 2024.

Para más detalles, consulta la documentación interna y los comentarios en el código fuente.

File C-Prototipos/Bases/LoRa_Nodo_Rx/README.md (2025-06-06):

# Proyecto IoT - Comunicación por Radiofrecuencia LoRa con ESP32  

Este proyecto implementa una comunicación inalámbrica entre dos nodos ESP32 utilizando módulos LoRa SX1278. Un nodo transmisor mide temperatura y humedad con un sensor DHT11 y envía los datos al nodo receptor. Este último activa un relay (o LED) si la temperatura supera un umbral predefinido.

### 🔧 Componentes Utilizados  

- 2× ESP32 Dev Module

- 2× Módulo LoRa SX1278 (modelo Lora1278-SMT)

- 1× Sensor DHT11

- 1× Relay o LED (como actuador)

- Protoboard, cables dupont, fuente 5V

## ⚙️ Funcionalidad  

1. El nodo transmisor:

- Lee los datos del sensor DHT11 (temperatura y humedad).

- Envía los datos por LoRa en formato de texto plano, por ejemplo:  

Temp:31 Hum:60

2. El nodo receptor:

- Recibe el mensaje a través del módulo LoRa.

- Extrae el valor de temperatura desde el mensaje recibido.

- Enciende un relay o LED si la temperatura es mayor a 30 °C, de lo contrario, permanece apagado.

### 🔌 Conexiones Nodo Transmisor  

|Componente	|Pin ESP32|  
|---|---|
|DHT11 Data	|GPIO 14|
|LoRa VCC	|3.3V|
|LoRa GND	|GND|
|LoRa SCK	|GPIO 18|
|LoRa MISO	|GPIO 19|
|LoRa MOSI	|GPIO 23|
|LoRa CS	|GPIO 5|
|LoRa RST	|GPIO 14|
|LoRa DIO0	|GPIO 26|

### 🔌 Conexiones Nodo Receptor  

|Componente	|Pin ESP32|  
|---|---|
|Relay/LED	|GPIO 27|
|LoRa →	|Igual que en el transmisor|  

### 💾 Librerías necesarias (en platformio.ini)  

```ini
lib_deps =
  sandeepmistry/LoRa@^0.8.0
  adafruit/DHT sensor library@^1.4.3  
```  

### 📟 Código del Nodo Receptor (LoRa_NodoRx)
```cpp

#include <SPI.h>
#include <LoRa.h>

// Pines LoRa
#define LORA_SCK 18
#define LORA_MISO 19
#define LORA_MOSI 23
#define LORA_SS 5
#define LORA_RST 14
#define LORA_DIO0 26

#define RELAY_PIN 27  // Simula el relay con un LED

void setup() {
  Serial.begin(115200);
  while (!Serial);

  pinMode(RELAY_PIN, OUTPUT);
  digitalWrite(RELAY_PIN, LOW); // Apagado al inicio

  // Configurar LoRa
  LoRa.setPins(LORA_SS, LORA_RST, LORA_DIO0);

  if (!LoRa.begin(433E6)) {
    Serial.println("Fallo al iniciar LoRa");
    while (1);
  }

  Serial.println("Nodo Receptor iniciado...");
}

void loop() {
  int packetSize = LoRa.parsePacket();
  if (packetSize) {
    String incoming = "";
    while (LoRa.available()) {
      incoming += (char)LoRa.read();
    }

    Serial.print("Mensaje recibido: ");
    Serial.println(incoming);

    // Analizar datos. Supongamos que recibimos: "Temp:31 Hum:60"
    if (incoming.indexOf("Temp:") != -1) {
      int tempIndex = incoming.indexOf("Temp:") + 5;
      int spaceIndex = incoming.indexOf(' ', tempIndex);
      String tempStr = incoming.substring(tempIndex, spaceIndex);
      float temp = tempStr.toFloat();

      if (temp > 30) {
        digitalWrite(RELAY_PIN, HIGH); // Activa relay
        Serial.println(">>> Relay ON (Temp alta)");
      } else {
        digitalWrite(RELAY_PIN, LOW);
        Serial.println(">>> Relay OFF (Temp normal)");
      }
    }
  }
}
```

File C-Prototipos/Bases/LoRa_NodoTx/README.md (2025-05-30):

# Proyecto IoT - Comunicación por Radiofrecuencia LoRa con ESP32

Este proyecto implementa una comunicación inalámbrica entre dos nodos ESP32 utilizando módulos LoRa SX1278. Un nodo transmisor mide temperatura y humedad con un sensor DHT11 y envía los datos al nodo receptor, que acciona un relay (o LED) dependiendo del valor de temperatura.

## 🔧 Componentes Utilizados

- 2× ESP32 Dev Module  
- 2× Módulo LoRa SX1278 (modelo Lora1278-SMT)  
- 1× Sensor DHT11  
- 1× Relay o LED (como actuador)  
- Protoboard, cables dupont, fuente 5V

## ⚙️ Funcionalidad

- El **nodo transmisor**:
  - Lee los datos del sensor DHT11 (temperatura y humedad).
  - Envía los datos por LoRa en formato `Temp:xx.x,Hum:yy.y`.

- El **nodo receptor**:
  - Recibe los datos LoRa.
  - Analiza la temperatura recibida.
  - Enciende un relay o LED si la temperatura supera los 30 °C.

## 🔌 Conexiones Nodo Transmisor

| Componente | Pin ESP32 |
|---|---|
| DHT11 Data | GPIO 14 |
| LoRa VCC | 3.3V |
| LoRa GND | GND |
| LoRa SCK | GPIO 18 |
| LoRa MISO  | GPIO 19 |
| LoRa MOSI  | GPIO 23 |
| LoRa CS | GPIO 5 |
| LoRa RST | GPIO 14 |
| LoRa DIO0  | GPIO 26 |

## 🔌 Conexiones Nodo Receptor

| Componente | Pin ESP32 |
|---|---|
| Relay/LED  | GPIO 27 |
| LoRa → | Igual que en el transmisor |

## 💾 Librerías necesarias (en `platformio.ini`)

```ini
lib_deps =
  sandeepmistry/LoRa@^0.8.0
  adafruit/DHT sensor library@^1.4.3

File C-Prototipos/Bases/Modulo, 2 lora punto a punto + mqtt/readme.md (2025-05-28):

# Puente LoRa-MQTT para Control Remoto de LED

Este proyecto IoT integra dos dispositivos para controlar remotamente un LED usando LoRa y MQTT:

- **ESP32 (Emisor):**  
  Ubicado en una zona remota, el ESP32 mide la luminosidad con un sensor BH1750 y controla un LED secundario. Se comunica vía LoRa, recibiendo comandos ("LED_ON" o "LED_OFF") y enviando lecturas de luz. *(No se conecta a WiFi)*

- **ESP8266 (Puente MQTT):**  
  Instalado en el interior, este dispositivo (configurado con VSCode + PlatformIO) se conecta a WiFi y a un broker MQTT. Recibe comandos MQTT ("ON", "OFF", "AUTO") y los reenvía al ESP32 por LoRa. En modo forzado, reenvía el último comando cada 10 segundos para mejorar la confiabilidad, y vuelve a modo automático tras 1 minuto de inactividad.

---

## Características

- **Control Remoto:** Permite forzar el estado del LED del ESP32 mediante comandos MQTT.
- **Modos de Operación:**  
  - *Modo Forzado:* Se activa con "ON" o "OFF" y se reenvía el comando periódicamente vía LoRa.  
  - *Modo Automático:* Se activa con "AUTO" o tras 1 minuto sin comandos, permitiendo que el ESP32 controle el LED según la luz.
- **Reenvío Periódico:** Asegura la recepción del comando en entornos con posibles pérdidas de paquetes.

---

## Requisitos de Hardware

- ESP32 (emisor)
- ESP8266 (por ejemplo, NodeMCU, receptor y puente MQTT)
- Módulos LoRa (433 MHz)
- Sensor BH1750 (para medir luminosidad)
- Cables y conexiones necesarios

---

## Dependencias y Entorno

El proyecto utiliza las siguientes librerías:
- [LoRa](https://github.com/sandeepmistry/arduino-LoRa)
- [PubSubClient](https://pubsubclient.knolleary.net/)
- [ESP8266WiFi](https://github.com/esp8266/Arduino)
- [ArduinoJson](https://arduinojson.org/)
- [BH1750](https://github.com/claws/BH1750)
- [SPI](https://www.arduino.cc/en/Reference/SPI)
- [Wire](https://www.arduino.cc/en/Reference/Wire)

Se recomienda utilizar VSCode con PlatformIO. Un ejemplo de `platformio.ini` para el ESP8266 podría ser:

```ini
[env:esp8266]
platform = espressif8266
board = nodemcuv2
framework = arduino
monitor_speed = 9600
build_flags = -DLORA_SS=15 -DLORA_RST=0 -DLORA_DIO0=5 -DLED_REMOTO_PIN=2
lib_deps =
  pubsubclient
  ArduinoJson
  ESP8266WiFi
  sandeepmistry/arduino-LoRa
```  
---   

## Configuración e Instalación

Clonar el repositorio: Descarga o clona este proyecto y ábrelo con VSCode.  

- Configuración del ESP8266:

    - Actualiza las variables ssid y password con los datos de tu red WiFi.

    - Ajusta los parámetros MQTT (mqtt_server, mqtt_port, mqtt_user, mqtt_password).

    - Verifica que los pines definidos (LoRa y LED) coincidan con tu hardware.

- Compilación y Subida: Utiliza el comando de PlatformIO para compilar y subir el firmware al ESP8266, y observa el "Serial Monitor" a 9600 baudios.

   - Broker MQTT y Control: Configura tu broker MQTT y suscríbete a los siguientes topics:

   - Control: sistema/luz/control

   - Datos: sistema/luz/ambiente

   - Estado: sistema/luz/estado

- Envía los comandos:

   - "ON": Fuerza el encendido del LED (reenvía "LED_ON" vía LoRa).

   - "OFF": Fuerza el apagado del LED (reenvía "LED_OFF").

   - "AUTO": Vuelve al modo automático para que el ESP32 controle el LED según la luminosidad.

## imagenes:
<p align="center">
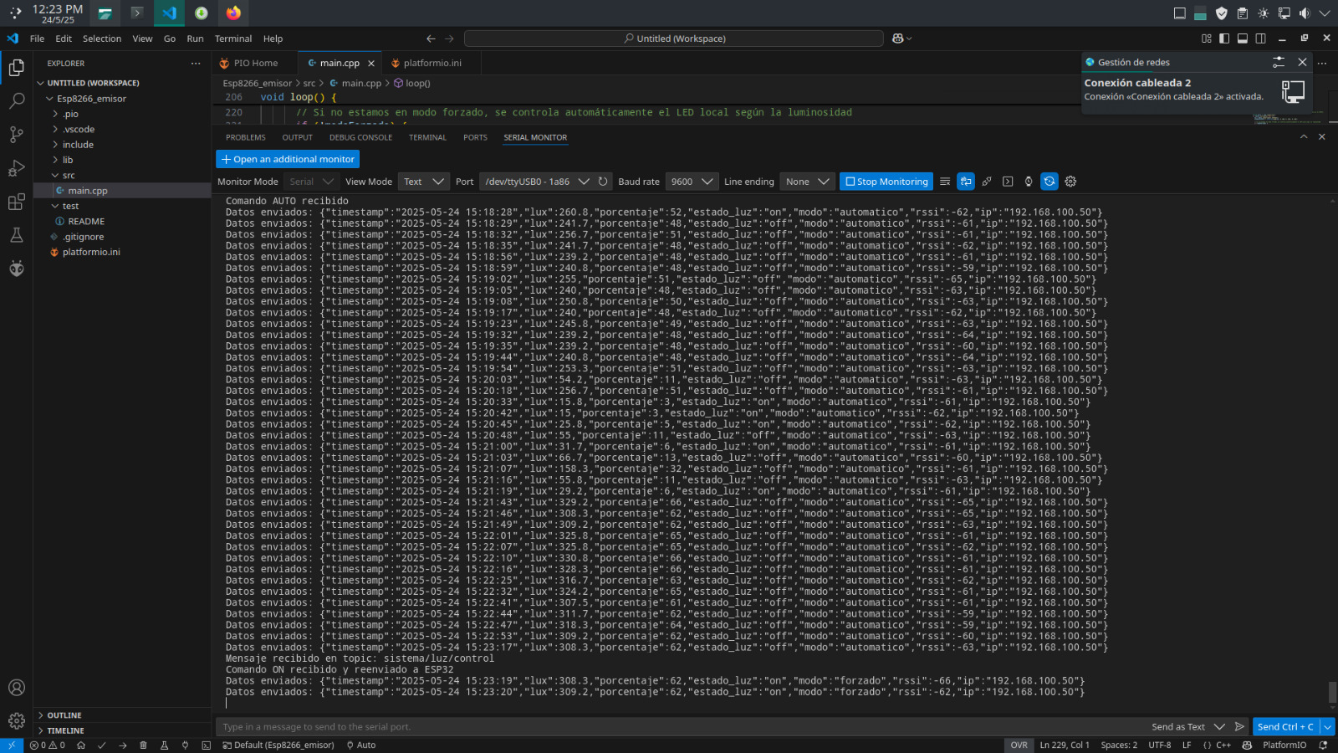
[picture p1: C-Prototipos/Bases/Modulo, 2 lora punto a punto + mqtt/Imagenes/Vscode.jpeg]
VSCODE
  
</p>  
   
<p align="center">
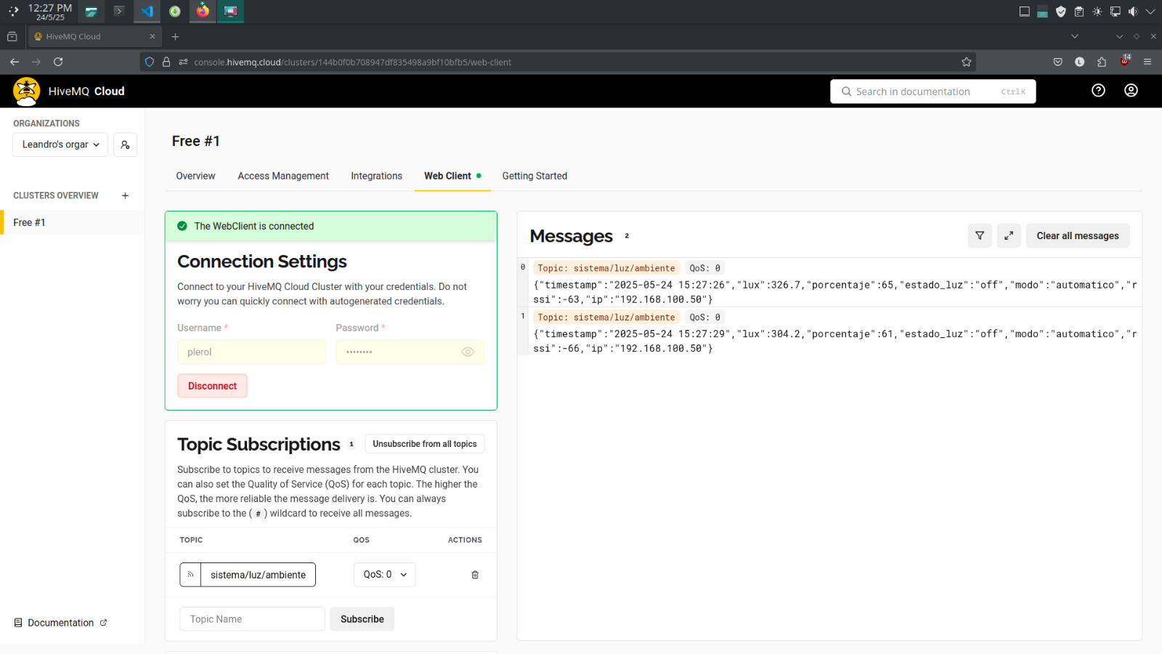
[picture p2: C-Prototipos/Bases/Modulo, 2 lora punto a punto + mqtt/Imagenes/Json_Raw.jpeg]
Broker con Json
  
</p>    

<p align="center">
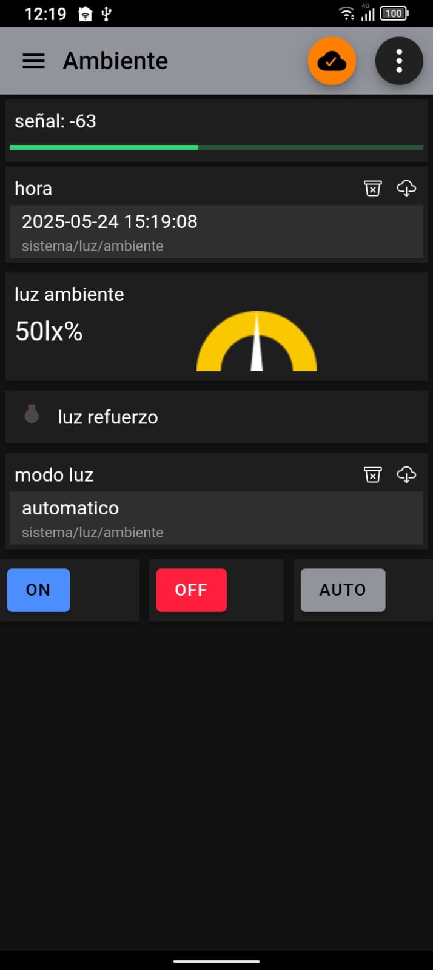
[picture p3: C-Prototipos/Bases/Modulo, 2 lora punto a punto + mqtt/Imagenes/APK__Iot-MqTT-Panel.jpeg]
APK con datos json visuales
  
</p>

---  

## Video de Funcionamiento

<p align="center">
  <a href="https://youtube.com/shorts/NL2lv98-YO0?feature=share">
    Ver video en YouTube
  </a>
</p>

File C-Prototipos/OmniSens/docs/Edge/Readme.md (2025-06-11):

# 🚀 OmniSens - Módulo Edge (Grupo Plata)

Este módulo forma parte del proyecto **OmniSens** y contiene el desarrollo de los nodos *edge*: sensores, gateway y actuadores conectados a una red IoT. La implementación corresponde al grupo **Plata** de la Tecnicatura en Telecomunicaciones.

---

## 📂 Estructura del directorio

```
Omnisens/docs/Edge/
├── sensor-edge/         # Código para nodo sensor (ESP32)
├── gateway-edge/        # Código para gateway LoRa-MQTT
├── actuator-edge/       # Código para actuadores (salidas GPIO)
└── README.md            # Documentación actual
```

---

## ⚙️ Requisitos previos

### 🔧 Hardware

* Módulos ESP32, LoRa SX1278
* Sensores (temperatura, gas, humedad)
* Actuadores (relés, LED, motores)
* Cableado y protoboard

### 🧰 Software

* [PlatformIO](https://platformio.org/)
* Repositorio clonado:

  ```bash
  git clone https://github.com/Programador-FullStack-IoT/Modulo-Programador-FullStack-IoT-TST-2024.git
  ```
* Docker con servicios activos (ver Portainer):
  🕻 [http://telecomunicaciones.ddns.net:8080/portainer/#!/3/docker/containers](http://telecomunicaciones.ddns.net:8080/portainer/#!/3/docker/containers)

---

## 🚀 Instalación y configuración

### 1. Sensor Edge

Ubicado en `sensor-edge/`:

* Ajustar `platformio.ini` según placa.
* Configurar parámetros en `config.h`:

  ```cpp
  #define NODE_ID "sensor_01"
  #define LORA_FREQUENCY 915E6
  #define MQTT_TOPIC "plata/sensores"
  ```
* Compilar y flashear:

  ```bash
  pio run -t upload
  ```

### 2. Gateway Edge

Ubicado en `gateway-edge/`:

* Recibe datos LoRa y los reenvía vía MQTT.
* Configurar `mqtt_config.json`:

  ```json
  {
    "host": "broker",
    "port": 1883,
    "topic_out": "plata/sensores",
    "topic_in": "plata/actuadores"
  }
  ```

### 3. Actuator Edge

Ubicado en `actuator-edge/`:

* Suscripción al tópico `plata/actuadores`.
* Acciona salidas GPIO (ej: encender ventilador):

  ```cpp
  if (command == "ON") digitalWrite(RELAY_PIN, HIGH);
  ```

---

## 🧪 Pruebas y verificación

### 🌐 Servicios desplegados

* **Portainer**: [Contenedores activos](http://telecomunicaciones.ddns.net:8080/portainer/#!/3/docker/containers)
* **Node-RED (grupo Plata)**: [Dashboard UI](http://telecomunicaciones.ddns.net:8080/nodered_plata/ui/#!/0)
* **Grafana (Grupo Plata)**: [Panel Público](http://telecomunicaciones.ddns.net:8080/grafana/public-dashboards/51aba874b6f44eff8c361c8ffdba9956)

### 🔀 Flujo de datos

1. El sensor transmite vía LoRa al gateway.
2. El gateway reenvía datos al broker MQTT.
3. Node-RED suscribe datos y los visualiza.
4. Grafana extrae métricas de la base de datos.
5. Node-RED también emite comandos a los actuadores.

---

## 📊 Integración con Node-RED y Grafana

### Node-RED

* Flujo: MQTT → procesamiento → UI → actuador.
* Ruta: `/nodered_plata/ui/`: [Dashboard UI](http://telecomunicaciones.ddns.net:8080/nodered_plata/ui/#!/0)
* Incluye botones para control manual, recepción de datos, lógica de automatización.

### Grafana

* Dashboards visuales conectados a base de datos.
* Panel con temperatura, gas, humedad y estado de actuadores.
* Ruta directa:
  [Dashboard público](http://telecomunicaciones.ddns.net:8080/grafana/public-dashboards/51aba874b6f44eff8c361c8ffdba9956)

---

## 🚯 Errores comunes

| Problema | Solución |
| --- | --- |
| No compila | Verificar placa, puerto COM, librerías |
| No recibe datos en Node-RED | Revisar frecuencia LoRa, conexión Gateway-MQTT |
| Actuador no responde | Verificar pines, lógica en Node-RED, MQTT activo |

---

## ✅ Checklist de puesta en marcha

1. Clonar repositorio.
2. Instalar PlatformIO y dependencias.
3. Flashear nodos sensor y actuador.
4. Levantar contenedores Docker (ya disponibles en Portainer).
5. Confirmar flujo MQTT → Node‑RED → Grafana.
6. Validar comandos de actuación vía UI.

---

## 🚣️ Roadmap y mejoras futuras

* Añadir autenticación MQTT y cifrado.
* Incluir alertas en Node-RED (vía correo o Telegram).
* Implementar dashboards privados por grupo.
* Documentación de integración global en `docs/integration.md`.

---

## 📢 Contacto

**Grupo Plata - Tecnicatura en Telecomunicaciones**
Repositorio: [OmniSens - FullStack IoT](https://github.com/Programador-FullStack-IoT/Modulo-Programador-FullStack-IoT-TST-2024)
Soporte: vía canal de clase o issues del repositorio.

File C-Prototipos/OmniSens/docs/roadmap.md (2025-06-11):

# 📚 Índice de Documentación - Proyecto OmniSens

| Documento | Descripción |
|---|---|
| [`arquitectura.md`](./arquitectura.md) | Visión general del sistema, componentes y flujo de datos. |
| [`integracion.md`](./integracion.md) | Explica cómo se conectan todos los nodos y servicios. |
| [`nodo-sensado.md`](./nodo-sensado.md) | Detalles técnicos del nodo de captura de datos (ESP32 + sensores). |
| [`nodo-receptor.md`](./nodo-receptor.md) | Función de Concentrador utilizando LoRa–MQTT, publica datos al broker. |
| [`nodo-actuador.md`](./nodo-actuador.md) | Recibe comandos y activa relés, PWM o LED baliza. |
| [`backend.md`](./backend.md) | Procesamiento de datos, publicación/lectura MQTT, conexión con base. |
| [`frontend.md`](./frontend.md) | Interfaz gráfica de monitoreo y control, uso de Node-RED UI / Grafana.  |

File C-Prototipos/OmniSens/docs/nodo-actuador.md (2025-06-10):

# Nodo Actuador - OmniSens

Este microcontrolador (ESP32) se encarga de ejecutar comandos remotos enviados desde el sistema de control (dashboard) o directamente desde otro microcontrolador, mediante los siguientes canales:

- MQTT (tópicos específicos)
- LoRa (enlace directo punto a punto)

---

## ⚙️ Funciones del nodo

- Escucha comandos MQTT o LoRa con un formato JSON.
- Procesa el mensaje y extrae:
  - Nivel de PWM (motor, ventilador)
  - Estados de relé 1 y relé 2
  - Código de alarma (para luces o alertas)
- Aplica los valores recibidos a los actuadores conectados.
- Puede incluir retroalimentación (en desarrollo).

---

## 🧱 Actuadores controlados

| Actuador | Descripción |
|---|---|
| Relé 1 | Control de dispositivo eléctrico |
| Relé 2 | Control de segundo dispositivo |
| PWM (Pin D4) | Control de velocidad (ej. motor) |
| WS2812 | Baliza LED de estado o alarma |

---

## 🔌 Pines típicos utilizados

| Componente | Pin |
|---|-----|
| PWM (motor) | D4  |
| Relé 1 | D0  |
| Relé 2 | D2  |
| WS2812 | D39 |

---

## 📦 Comandos esperados (formato JSON) 

```json
{
  "id": "AQC_001",
  "token": "clave123",
  "pwm": 150,
  "rele1": true,
  "rele2": false,
  "cod": 2
}
| Campo | Descripción                         |
| ----- | ----------------------------------- |
| id    | Identificador del nodo destinatario |
| token | Token de autenticación              |
| pwm   | Valor PWM (0 a 255)                 |
| rele1 | Estado del relé 1 (true/false)      |
| rele2 | Estado del relé 2 (true/false)      |
| cod   | Código de alarma o estado           |

## 🔁 Flujo funcional del nodo

[ MQTT o LoRa RX ]
         ↓
[ JSON recibido ]
         ↓
[ Decodificación ]
         ↓
[ Actuadores: PWM, Relés, WS2812 ]

## 💬 Comunicación bidireccional

- Este nodo puede:

- Escuchar y ejecutar órdenes remotas (actualmente implementado).

- En el futuro: enviar estado o alertas al sistema (a través de MQTT o LoRa).

## 📁 Ubicación del código

/edge/microcontrolador-actuador/
├── include/
│   ├── SalidaPWM.h
│   ├── SalidasRele.h
│   ├── Baliza_con.h
│   ├── EnlaceLora.h
│   └── DatoJson.h
├── src/
│   └── main.cpp
├── platformio.ini

## 🧠 Observaciones

- Es un nodo de ejecución de órdenes, no tiene sensores.

- Soporta ambos protocolos: LoRa y MQTT.

- La lógica de seguridad debe validar el id y token antes de aplicar los comandos.

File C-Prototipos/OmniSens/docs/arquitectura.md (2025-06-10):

# Arquitectura General del Proyecto OmniSens

Este documento describe la arquitectura lógica y física del sistema IoT desarrollado por el grupo AQI – PLATA, en el marco del Módulo FullStack IoT (Tecnicatura Superior en Telecomunicaciones).

---

## 🧱 Componentes del Sistema

| Componente | Descripción |
|---|---|
| Nodo de Sensado | Dispositivo con sensores ambientales, genera y envía datos por LoRa |
| Nodo Receptor | Recibe por LoRa y publica por MQTT |
| Nodo Actuador | Recibe comandos por MQTT o LoRa y activa relés, baliza, PWM |
| Broker MQTT | Alojado en la nube para publicar/suscribirse a tópicos |
| Node-RED | Motor de flujos para procesamiento, control y envío a base de datos |
| Base de Datos (MariaDB) | Almacena datos históricos de sensores |
| Dashboard (UI/Grafana) | Interfaz de visualización y control manual |

---

## 🔄 Flujo de Datos General

[ Nodo Sensado ]
↓ LoRa
[ Nodo Receptor ]
↓ MQTT
[ Broker Mosquitto ]
↓
[ Node-RED ]
↓ ↘
[ MariaDB ] [ MQTT → Nodo Actuador ]
↓
[ Actuadores ]

---

## 📚 Documentación Técnica por módulo

Para más detalle sobre cada nodo, consultar:

- 📗 [`nodo-sensado.md`](./nodo-sensado.md)
- 📘 [`nodo-receptor.md`](./nodo-receptor.md)
- 🔧 [`nodo-actuador.md`](./nodo-actuador.md) *(por crear)*
- 🌐 [`backend.md`](./backend.md) *(por crear)*
- 🖥️ [`frontend.md`](./frontend.md) *(por crear)*

---

## 🔌 Tecnologías utilizadas

- **Hardware:** ESP32, sensores MQ135, AHT25, BMP280, LDR, baliza WS2812, relés
- **Comunicaciones:**
  - LoRa punto a punto (433 MHz)
  - MQTT (broker en nube: `telecomunicaciones.ddns.net`)
- **Software:**
  - PlatformIO / Arduino
  - Node-RED
  - MariaDB
  - Grafana (para dashboards)
  - Frontend web con HTML/CSS/JS (detalles en carpeta `hub/frontend/`)

---

## 🛠️ Próximos pasos

- Integrar documentación de backend y frontend
- Documentar flujo de seguridad/autenticación (token en JSON)
- Incorporar esquemas gráficos de arquitectura física y lógica

---

## 📅 Estado del sistema (junio 2025)

✔ Nodos sensado y receptor funcionando  
✔ Comunicación LoRa operativa  
✔ JSON de datos y comandos implementado  
⏳ En proceso: integración con MQTT, dashboards, actuadores remotos  
📈 En desarrollo: visualización e historial de datos

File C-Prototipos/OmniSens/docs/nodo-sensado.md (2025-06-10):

# Nodo de Sensado - OmniSens

Este microcontrolador (ESP32) se encarga de:

- Leer variables ambientales: gases (MQ135), temperatura y humedad (AHT25), presión (BMP280), y luminosidad (LDR).
- Generar un JSON con todos los datos sensados.
- Enviar los datos vía LoRa a otro microcontrolador (nodo receptor).
- Recibir comandos (PWM, relés, alarmas) desde el nodo receptor también vía LoRa.

---

## 🔌 Pines utilizados

| Componente | Pin |
|---|-----|
| LoRa_CS | 18  |
| LoRa_RST | 14  |
| LoRa_INT | 26  |
| MQ135 (gases) | 34  |
| PWM (motor) | 4 |
| Relé 1 | 0 |
| Relé 2 | 2 |
| WS2812 (baliza) | 39  |
| LDR (luz) | 36  |

---

## ⚙️ Funcionalidad del código (`main.cpp`)

- **Lectura de sensores:** se realiza con objetos de clases personalizadas:
  - `MQ135Sensor`
  - `AHT25Sensor`
  - `BMP280Sensor`
  - `LDRSensor`

- **Control de actuadores:**
  - PWM: salida analógica modulada.
  - Relé 1 y Relé 2: salidas digitales.
  - WS2812: LED inteligente para indicar estado ambiental (por ej. nivel de gas).

- **Timers no bloqueantes (`Ticker`):**
  - `actualizarSensores()` cada 100 ms.
  - `actualizarSalidas()` cada 100 ms.
  - `enviarPorLora()` cada 5 segundos.

- **Envío y recepción LoRa:**
  - Envío periódico del JSON con datos.
  - Recepción de comandos codificados en JSON (PWM, relés, alarma).

---

## 🧱 JSON generado

Se envía un JSON con esta información:
- Identificación del nodo (`NODE_ID`)
- Timestamp actual
- Valores de sensores (temperatura, humedad, presión, gases, luz, UV*)
- Estado de los actuadores
- Flags como `alarmaGas` y `codigoAlarma`

Ejemplo (formato):

```json
{
  "id": "AQC_001",
  "ts": 1710000000,
  "token": "clave123",
  "mq135": 305.7,
  "temp": 23.4,
  "hum": 45.1,
  "pres": 1012.3,
  "lux": 358,
  "uv": 0,
  "pwm": 120,
  "rele1": false,
  "rele2": true,
  "alarma": false,
  "cod": 0
}

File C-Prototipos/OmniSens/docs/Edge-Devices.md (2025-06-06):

# Dispositivos Edge en el Prototipo OmniSens

## Introducción

En el prototipo OmniSens, los dispositivos Edge son nodos inteligentes que recolectan y procesan datos de sensores localmente, en el "borde" de la red. Esta arquitectura permite un procesamiento eficiente y una comunicación optimizada con los servidores centrales o la nube.

## ¿Qué es un dispositivo Edge?

Un dispositivo Edge es un hardware que realiza procesamiento de datos cercano a la fuente de información, en lugar de enviar toda la información sin procesar a un servidor remoto. Esto reduce la latencia, mejora la respuesta en tiempo real y disminuye el consumo de ancho de banda.

## Funcionalidad de los dispositivos Edge en OmniSens

- Lectura de datos desde sensores conectados.
- Procesamiento local de señales, incluyendo filtrado y detección de eventos relevantes.
- Envío de datos procesados o alertas al servidor central utilizando protocolos MQTT o HTTP.
- Operación autónoma con bajo consumo energético.
- Gestión de comunicaciones confiables con el servidor central o la nube.

## Arquitectura técnica

- **Hardware:** Microcontroladores como ESP32 o STM32, con conectividad WiFi o Ethernet.
- **Software:** Firmware especializado para la lectura de sensores y procesamiento local, que implementa protocolos MQTT para la comunicación.
- **Comunicación:** Uso de MQTT para transmitir datos procesados y eventos al servidor central.
- **Seguridad:** Implementación de cifrado TLS/SSL para la transmisión segura de datos (si aplica).

## Beneficios de usar dispositivos Edge

- Reducción del tráfico de red al enviar solo datos relevantes.
- Mejor respuesta en tiempo real para aplicaciones críticas.
- Mayor robustez y autonomía de los nodos.
- Escalabilidad del sistema al distribuir la carga de procesamiento.

## Diagrama básico de flujo

```
[Sensores] --> [Dispositivo Edge (Procesamiento local)] --> [Servidor Central / Nube]
```

---

## Referencias

Para más detalles técnicos, consultar el código fuente y diagramas en la carpeta `src` y otros documentos relacionados en este repositorio.

---

*Este documento forma parte de la documentación técnica del prototipo OmniSens, desarrollado dentro del módulo Programador FullStack IoT TST 2024.*

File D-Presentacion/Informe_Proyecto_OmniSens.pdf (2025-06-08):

## Informe Tecnico Proyecto OmniSens

OmniSens Sistema de Monitoreo y Control Ambiental

Equipo de Desarrollo

Fernando Gimenez Coria, Paola Pantoja, Diego Ares, Emma Gutierrez, Macarena Carballo, Romina

Huk, Juan Gonzalez Antoniazzi, Leandro Roldan, Raul Jara

Descripcion General

OmniSens es una solucion IoT que mide variables ambientales como temperatura, humedad,

presion, luminosidad y gases. Usa sensores distribuidos conectados via LoRa a un nodo

concentrador, que envia datos al servidor mediante MQTT. El sistema permite monitoreo y control

en tiempo real.

Objetivos

Medir condiciones ambientales criticas en tiempo real.

Activar dispositivos automaticamente segun condiciones.

Guardar datos historicos para analisis y toma de decisiones.

Arquitectura del Sistema

Sensores Edge recogen y reaccionan a eventos ambientales.

Red LoRa tipo estrella para transmision eficiente.

Nodo Gateway y servidor MQTT + Node-RED + Grafana para visualizacion y control.

Componentes Principales

Sensores: temperatura, humedad, gases, luz, presion.

Actuadores: alarmas, luces, extractores.

Microcontroladores con LoRa.

Backend con Node.js, API REST, base de datos y dashboard.

Estructura del Repositorio

docs/: documentacion tecnica.

hub/: backend y frontend.

devices/, edge/: codigo para nodos y sensores.

deployments/: configuraciones de despliegue.

tests/: pruebas unitarias e integracion.

Roadmap del Proyecto

Fase 0: diseno y arquitectura.

Fase 1: sensado y control inicial.

Fase 2: backend y base de datos.

Fase 3: interfaz y dashboard.

Fase 4: integracion y pruebas.

Fase 5: documentacion y mejoras futuras.

Estado Actual

El proyecto esta en desarrollo activo con prototipos funcionales en curso. Hay issues resueltos y

otros en seguimiento para implementar nuevas funciones y documentacion.

Proximos Pasos

Terminar la integracion completa.

Incluir nuevos sensores y protocolos.

Pruebas en entornos reales o simulados.

Completar guias de despliegue y uso.

Licencia

Distribuido bajo Licencia MIT.

Repositorio

https://github.com/Programador-FullStack-IoT/Modulo-Programador-FullStack-IoT-TST-2024

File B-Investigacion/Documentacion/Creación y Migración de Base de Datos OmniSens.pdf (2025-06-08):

## Creación y Migración de Base de Datos OmniSens a MariaDB Remoto

Descripción General

Este documento detalla el proceso de creación del esquema OmniSens, su estructura de tablas, claves foráneas y el traslado exitoso a un servidor remoto utilizando MariaDB a través del cliente gráfico HeidiSQL.

### 1. Creación del Esquema y Tablas

El esquema OmniSens fue diseñado en MySQL Workbench y exportado mediante ingeniería directa (Forward Engineering). A continuación, se resumen las principales características:

Esquema

CREATE SCHEMA IF NOT EXISTS `OnmiSens` DEFAULT CHARACTER SET utf8;

- Establece la codificación UTF-8 para compatibilidad internacional.
- El nombre del esquema se normalizó como OmniSens.

Tablas creadas

### 1. devices

a. Almacena información de cada dispositivo IoT.
b. Clave primaria: device_id.
c. Timestamp de creación automático: created_at.

### 2. api_users

a. Almacena usuarios con acceso mediante clave API.
b. Incluye restricción UNIQUE en el campo api_key.

### 3. sensor_data

a. Guarda datos recopilados por sensores como temperatura, humedad, luz, etc.
b. Clave foránea: device_id → devices(device_id).

### 4. actuator_status

a. Registra el estado de los actuadores (relés, PWM).

b. Incluye campos binarios y textuales para control flexible.
c. Clave foránea: device_id.

### 5. commands_log

a. Almacena todos los comandos enviados a actuadores.
b. Contiene información crítica como el tipo de acción (ON, OFF, VALOR), el actuador y el valor.
c. Clave foránea: device_id.

### 2. Exportación y Traslado a Servidor MariaDB

Proceso de Migración

1. Exportación SQL desde MySQL Workbench:
a. Se generó un archivo .sql con todas las sentencias CREATE y restricciones.
b. El script incluyó control de llaves foráneas y restricciones de unicidad.
2. Transferencia a MariaDB Remoto:
a. Se utilizó HeidiSQL para conectarse al servidor remoto MariaDB.
b. Configuración:
i. Host/IP del servidor remoto.
ii. Puerto estándar: 6034
iii. Usuario y contraseña con permisos de escritura.
3. Importación del Script:
a. Se ejecutó el script SQL directamente en HeidiSQL.
b. Se verificó la creación correcta del esquema y todas las tablas.
c. Se respetaron todas las claves primarias, índices y relaciones foráneas.

Validaciones Realizadas

- Se confirmaron las relaciones entre tablas mediante pruebas de integridad referencial.
- Se verificó la creación automática de timestamps.
- Se probó la inserción de datos simulados desde scripts para comprobar funcionalidad.
- Se realizaron consultas JOIN para asegurar la integridad entre tablas como
commands_log y devices.

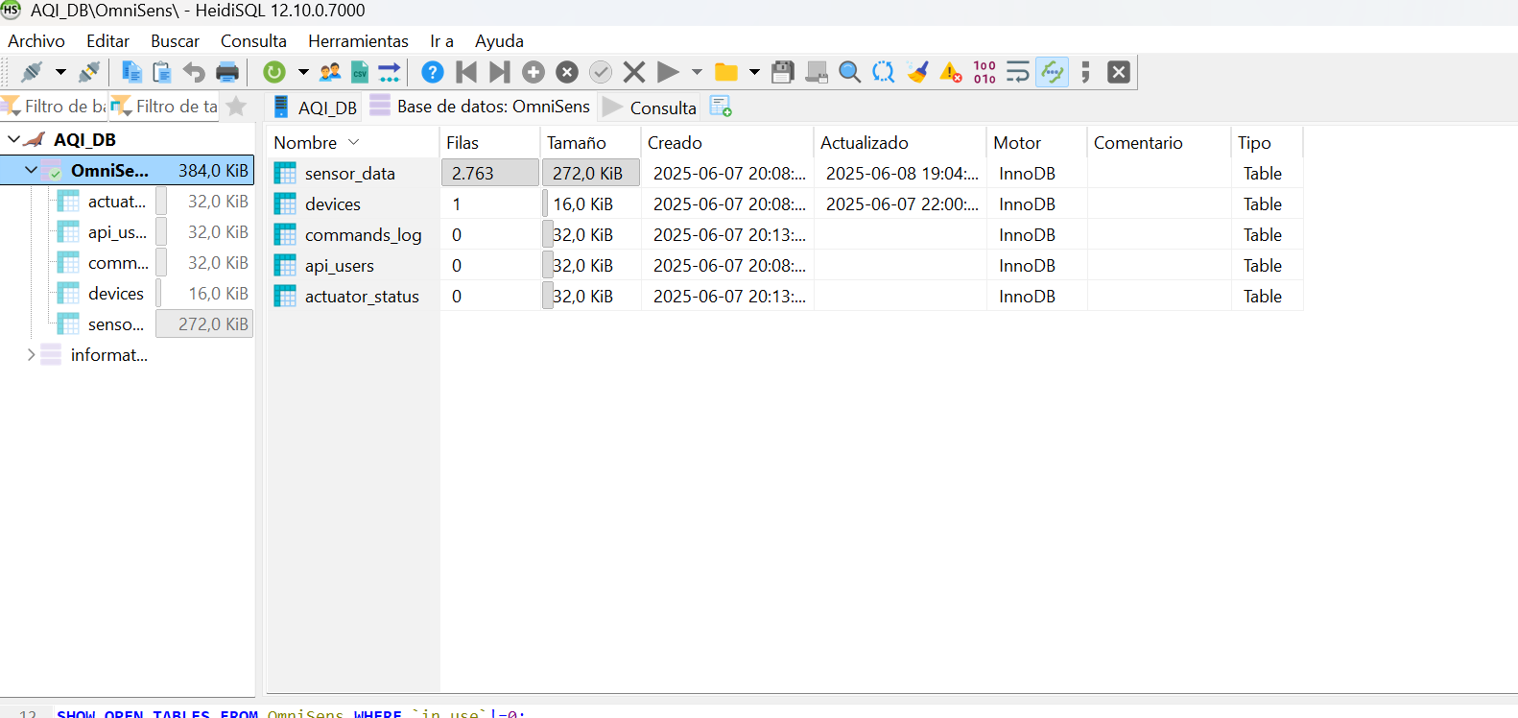
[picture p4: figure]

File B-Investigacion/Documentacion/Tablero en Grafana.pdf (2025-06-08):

# Tablero en Grafana: Monitoreo de Comandos a Actuadores

## Introducción

Este documento describe la creación y propósito de un tablero en Grafana para visualizar y analizar los comandos enviados a los actuadores desde una plataforma IoT. El objetivo principal es auditar la actividad del sistema, detectar patrones de uso, y evaluar el comportamiento de los dispositivos conectados.

## Fuente de Datos

- Origen: Base de datos SQL conectada a Grafana.
- Tabla base: comandos
- Campos clave utilizados: timestamp, device_id, actuator, action, value

## Paneles del Tablero

### 1. Historial de comandos por dispositivo

- Tipo de panel: Tabla
- Qué muestra: Los últimos comandos enviados, incluyendo:
- Fecha y hora (timestamp)
- ID del dispositivo
- Actuador involucrado
- Acción ejecutada (ON, OFF, etc.)
- Valor (si corresponde)
- Utilidad: Permite monitorear en tiempo real y auditar la actividad reciente de cada nodo IoT.
- Consulta:

SELECT timestamp, device_id, actuator, action, value FROM comandos
ORDER BY timestamp DESC

LIMIT 50

### 2. Comandos enviados por tipo de actuador

- Tipo de panel: Barras / Pie
- Qué muestra: Total de comandos enviados a cada tipo de actuador (relés, LEDs, ventiladores, etc.).
- Utilidad: Visualizar qué actuadores son más demandados por el sistema.
- Consulta:

SELECT actuator, COUNT(*) AS total
FROM comandos
GROUP BY actuator

### 3. Frecuencia de comandos por día

- Tipo de panel: Gráfico de líneas o barras
- Qué muestra: Cantidad de comandos enviados por día.
- Utilidad: Detectar tendencias de uso diario, picos de actividad o posibles comportamientos anómalos.
- Consulta:

SELECT DATE(timestamp) AS fecha, COUNT(*) AS total FROM comandos
GROUP BY DATE(timestamp)
ORDER BY fecha

### 4. Comandos ON vs OFF

- Tipo de panel: Gráfico de torta o barras apiladas
- Qué muestra: Total de comandos con acción "ON" frente a los de tipo "OFF".
- Utilidad: Analizar si los actuadores están más tiempo encendidos o apagados.
- Consulta:

SELECT action, COUNT(*) AS total
FROM comandos

WHERE action IN ('ON', 'OFF') GROUP BY action

### 5. Último comando por dispositivo

- Tipo de panel: Tabla
- Qué muestra: La última vez que cada dispositivo recibió un comando.
- Utilidad: Verificar si los dispositivos están activos o si alguno dejó de recibir órdenes.
- Consulta:

SELECT device_id, MAX(timestamp) AS ultimo_comando FROM comandos
GROUP BY device_id

### 6. Comandos enviados por valor

- Tipo de panel: Barras
- Qué muestra: Cuántas veces se envió cada valor a los actuadores.
- Utilidad: Útil para actuadores con valores variables (PWM, intensidad, posición, etc.), ayudando a detectar patrones o valores atípicos.
- Consulta:

SELECT value, COUNT(*) AS total
FROM comandos
GROUP BY value
ORDER BY total DESC

## Configuraciones adicionales

- Período de visualización: Última hora (now-1h to now)
- Zona horaria: America/Argentina/Cordoba
- Filtros disponibles: Variables opcionales por device_id, actuator, o action para interactuar con los paneles dinámicamente.

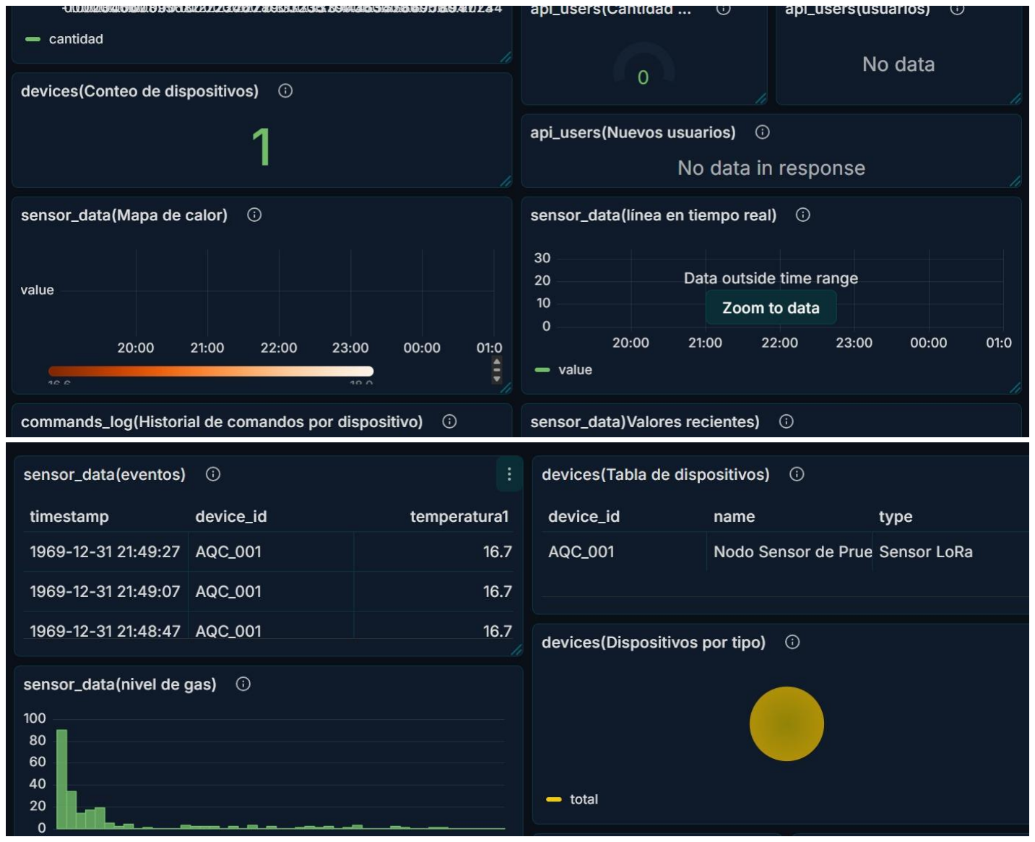
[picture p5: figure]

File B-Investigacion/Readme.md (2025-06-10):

# 📂 Investigación y Pruebas (`B-Investigacion`)

Bienvenido a la carpeta de **Investigación y Pruebas** del proyecto **OmniSens**. Aquí encontrarás toda la documentación de respaldo, investigación y pruebas de concepto que sentaron las bases para el desarrollo de los prototipos.

---

## 📄 Documentación Técnica Principal

- **`Proyecto_OMNISENS_ISPC_Programador Fullstack_2025Documentación Técnica.pdf`**  
    Documento central de la fase de investigación.  
    - **Incluye:**  
        - Arquitectura del sistema  
        - Objetivos y alcance del proyecto  
        - Tecnologías seleccionadas  
    - **Propósito:**  
        Sirve como guía completa de la visión técnica y funcional de la plataforma.

---

## 📡 Pruebas de Comunicación Inalámbrica (`Lora estrella`)

Validación de la tecnología de comunicación de largo alcance **LoRa**, fundamental para la interacción entre nodos sensores y el concentrador.

- **Resumen de la Prueba:**  
    Pruebas punto a punto (emisor y receptor) con dos placas **ESP32 LoRa V1**.
- **Librerías Utilizadas:**  
    - [`RadioLib`](https://github.com/jgromes/RadioLib) de JGromes para control de módulos de radio.
- **Documentación de Soporte:**  
    - `Comunicacion_LoRa_ESP32.docx`: Procedimientos y resultados de las pruebas.
    - `readme.md`: Resumen técnico de la implementación.

---

## 🗄️ Base de Datos y Visualización (`Documentacion`)

Documentación sobre la gestión y presentación de los datos recolectados.

- **`Creación y Migración de Base de Datos OmniSens.pdf`**  
    - Proceso de diseño, creación e importación del esquema de base de datos **MySQL**.
    - Guía esencial para entender la estructura de datos y levantar el entorno de persistencia.
- **`Tablero en Grafana.pdf`**  
    - Guía visual y técnica para configurar el dashboard en **Grafana**.
    - Explicación de la conexión a MySQL y creación de paneles para visualizar métricas en tiempo real.

---

> ℹ️ **Explora cada documento para obtener información detallada sobre la arquitectura, pruebas y visualización de datos del proyecto OmniSens.**

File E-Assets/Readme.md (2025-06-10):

# 🖼️ Recursos Gráficos (`E-Assets`)

Esta carpeta contiene todos los recursos gráficos y visuales del proyecto **OmniSens**. Aquí encontrarás logotipos, diagramas de arquitectura y otras imágenes relevantes que facilitan la comprensión de la estructura y la identidad de la plataforma.

---

## 📁 Contenido de la Carpeta

### 🏷️ Logotipo del Proyecto

- **`logo.png`**  
    El logo oficial que representa la identidad de **OmniSens**.

---

### 🗺️ Diagramas de Arquitectura

- **`arquitectura_proyecto_ACTUALIZADA.png`**  
    Diagrama actualizado del sistema. Muestra el flujo de datos desde los nodos sensores, pasando por el concentrador LoRa y el broker MQTT, hasta la API y la base de datos, finalizando en la capa de visualización.

- **`arquitectura_proyecto.png`**  
    Versión inicial del diagrama de arquitectura.

---

### 🖼️ Imágenes Adicionales

Imágenes de apoyo que pueden incluir fotos de prototipos de hardware, componentes específicos o capturas de pantalla de la plataforma.

| Imagen | Descripción |
|---|---|
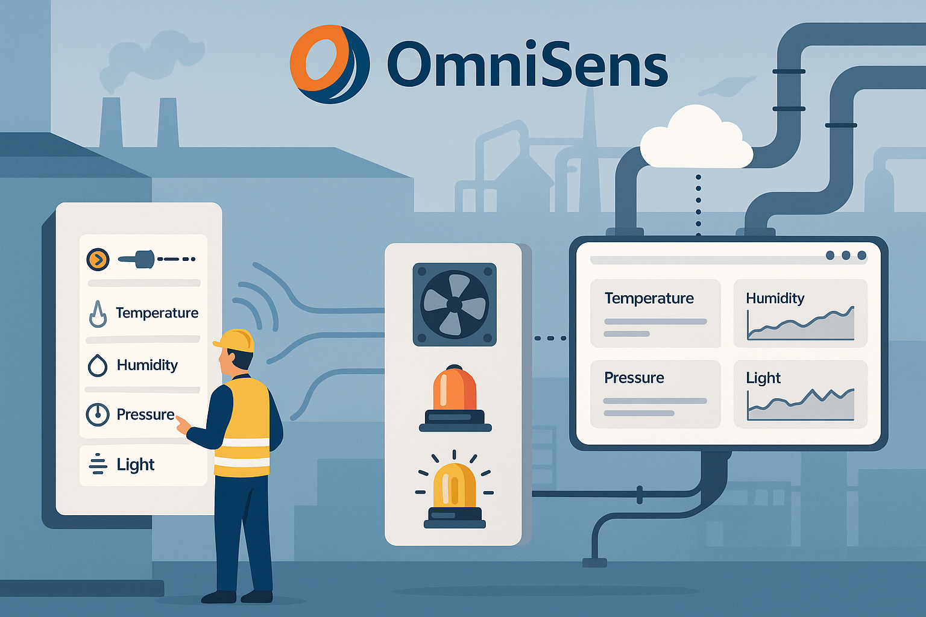
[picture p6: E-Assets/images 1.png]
Imagen de apoyo 1
|  | Prototipo de hardware o componente relevante |
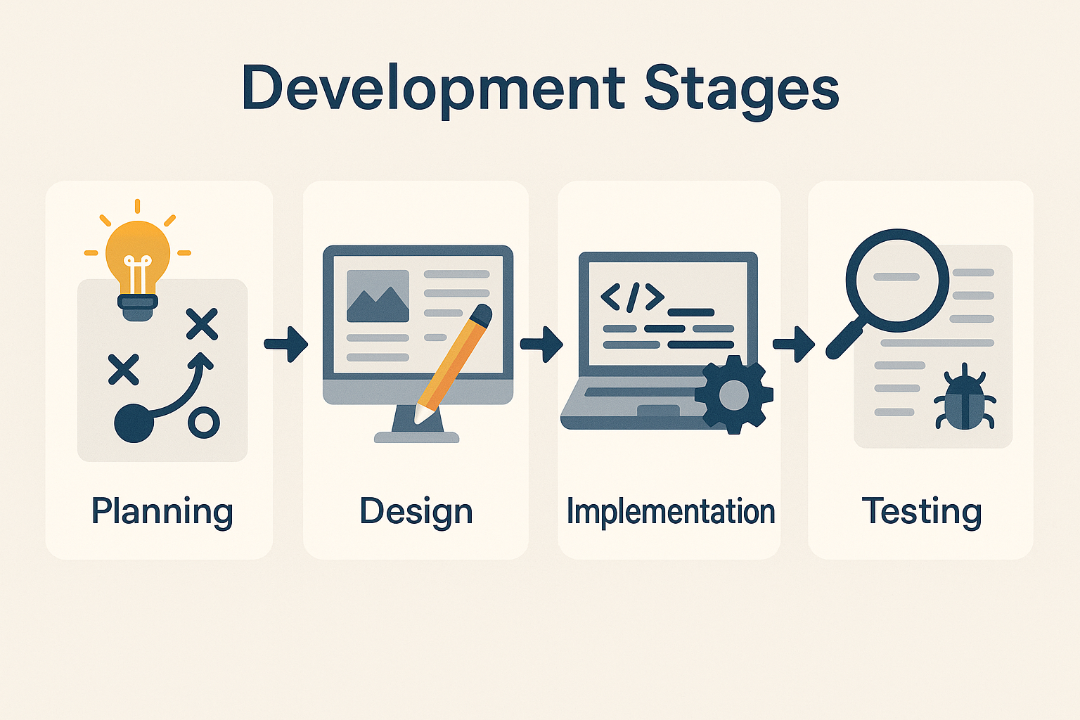
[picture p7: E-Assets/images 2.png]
Imagen de apoyo 2
|  | Componente específico o detalle técnico |
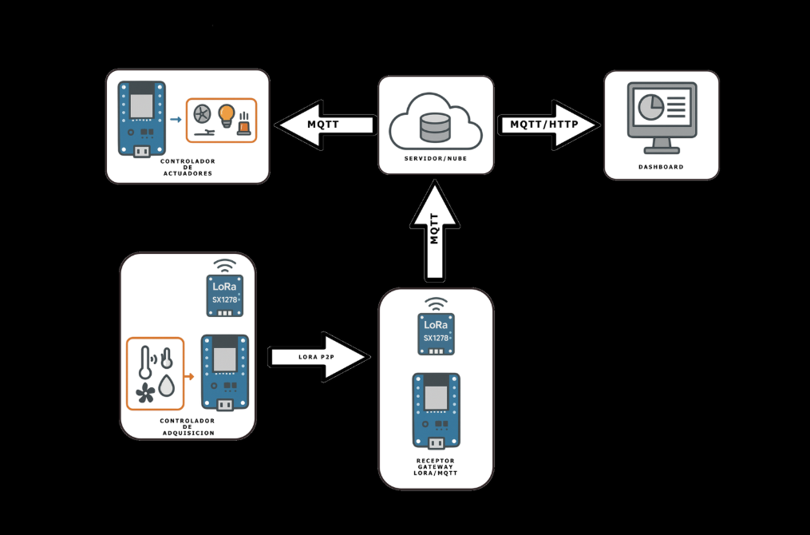
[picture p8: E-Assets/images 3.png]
Imagen de apoyo 3
|  | Captura de pantalla de la plataforma o imagen ilustrativa |

---

> **Nota:** Todos los archivos gráficos deben mantenerse organizados y actualizados para asegurar una documentación visual clara y útil.

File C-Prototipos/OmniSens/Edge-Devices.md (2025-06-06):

# Dispositivos Edge en el Proyecto OmniSens

## Introducción

En el proyecto **OmniSens**, los dispositivos Edge son componentes fundamentales que permiten el procesamiento local de datos provenientes de sensores, antes de ser enviados a la nube o a servidores centrales. Esta arquitectura de computación en el borde (edge computing) mejora la eficiencia, reduce la latencia y optimiza el uso del ancho de banda.

## Rol de los Dispositivos Edge

Los dispositivos Edge en OmniSens cumplen las siguientes funciones:

- **Adquisición de datos**: Recopilan información de diversos sensores (por ejemplo, temperatura, humedad, presión).
- **Procesamiento local**: Realizan análisis preliminares, como filtrado de ruido y detección de eventos relevantes.
- **Comunicación eficiente**: Transmiten únicamente los datos procesados o eventos significativos al servidor central, utilizando protocolos como MQTT o HTTP.
- **Autonomía operativa**: Pueden funcionar de manera independiente en caso de pérdida de conexión con la nube, almacenando datos localmente hasta restablecer la comunicación.

## Hardware Utilizado

Los dispositivos Edge en OmniSens están basados en microcontroladores y microprocesadores de bajo consumo y alta eficiencia. Algunos ejemplos incluyen:

- **ESP32**: Microcontrolador con conectividad Wi-Fi y Bluetooth, ideal para aplicaciones IoT.
- **Raspberry Pi**: Microcomputadora de bajo costo y tamaño reducido, adecuada para tareas de procesamiento más complejas.

Estos dispositivos pueden estar equipados con módulos de comunicación adicionales, como LoRa o Zigbee, dependiendo de los requisitos específicos del entorno de implementación.

## Software y Firmware

El software que opera en los dispositivos Edge está diseñado para ser ligero y eficiente. Sus características principales incluyen:

- **Lectura de sensores**: Interfaces para adquirir datos de diversos tipos de sensores.
- **Procesamiento de datos**: Algoritmos para análisis en tiempo real, detección de anomalías y toma de decisiones locales.
- **Gestión de comunicaciones**: Implementación de protocolos como MQTT para la transmisión de datos al servidor central.
- **Actualizaciones remotas**: Capacidad para recibir actualizaciones de firmware de forma remota, facilitando el mantenimiento y la mejora continua.

El desarrollo del firmware se realiza utilizando lenguajes como C/C++ o Python, y puede incluir bibliotecas específicas para la gestión de sensores y comunicaciones.

## Seguridad y Mantenimiento

La seguridad es un aspecto crucial en la arquitectura Edge de OmniSens. Se implementan medidas como:

- **Autenticación y autorización**: Verificación de identidad de los dispositivos antes de permitir el intercambio de datos.
- **Cifrado de datos**: Uso de protocolos seguros (TLS/SSL) para proteger la información transmitida.
- **Monitoreo y alertas**: Sistemas para detectar comportamientos anómalos y generar alertas en tiempo real.

Además, se establece un plan de mantenimiento preventivo que incluye la supervisión del estado de los dispositivos, actualizaciones periódicas y reemplazo de componentes en caso necesario.

## Beneficios de la Arquitectura Edge en OmniSens

- **Reducción de latencia**: Al procesar datos localmente, se obtienen respuestas más rápidas ante eventos críticos.
- **Eficiencia en el uso del ancho de banda**: Se transmiten únicamente los datos relevantes, disminuyendo la carga en la red.
- **Escalabilidad**: La arquitectura permite agregar nuevos dispositivos Edge sin afectar significativamente el rendimiento del sistema.
- **Resiliencia**: Los dispositivos pueden operar de manera autónoma en caso de fallos en la conexión con la nube.

## Diagrama de Flujo Simplificado

```
[Sensores] --> [Dispositivo Edge (Procesamiento local)] --> [Servidor Central / Nube]
```

## Conclusión

Los dispositivos Edge son componentes esenciales en la arquitectura del proyecto OmniSens, permitiendo una gestión eficiente y segura de los datos provenientes de sensores en entornos IoT. Su implementación adecuada contribuye significativamente al rendimiento y la fiabilidad del sistema en su conjunto.

---

*Este documento forma parte de la documentación técnica del prototipo OmniSens, desarrollado dentro del módulo Programador FullStack IoT TST 2024.*

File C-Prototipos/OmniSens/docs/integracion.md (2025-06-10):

# Integración del Sistema OmniSens

Este documento describe la integración completa del sistema IoT de monitoreo ambiental desarrollado por el grupo AQI – PLATA, desde los sensores hasta el dashboard final.

---

## 🧱 Componentes Integrados

| Componente | Función principal |
|---|---|
| Nodo de Sensado | Captura variables ambientales y genera JSON |
| Nodo Receptor | Recibe LoRa y publica por MQTT |
| Nodo Actuador | Recibe comandos por LoRa/MQTT y activa salidas |
| Broker MQTT (Mosquitto) | Comunicación entre microcontroladores y backend |
| Node-RED | Procesa, enruta y almacena datos |
| MariaDB | Almacenamiento persistente de datos |
| Dashboard (Grafana/UI) | Visualización en tiempo real y control manual |

---

## 🔄 Flujo completo de datos y control

1. **Sensado:**
   - El nodo sensado mide: temperatura, humedad, gases, presión, luz.
   - Genera un mensaje JSON y lo envía por LoRa al nodo receptor.

2. **Recepción y publicación MQTT:**
   - El nodo receptor procesa el JSON y publica cada variable en un topic MQTT.
   - MQTT Broker está en la nube: `telecomunicaciones.ddns.net:2480`.

3. **Procesamiento:**
   - Node-RED está suscripto a los topics del broker.
   - Muestra en tiempo real los datos y los guarda en MariaDB.
   - Permite generar reglas de control automático (por ejemplo, si gas > 400 → activar ventilador).

4. **Control:**
   - Desde Node-RED UI o Grafana, se pueden enviar comandos al nodo actuador.
   - Node-RED publica un JSON en un topic específico (`grupoAQI/ordenes`).
   - El nodo actuador ejecuta los comandos (reles, PWM, baliza).

---

## 🌐 Detalles de comunicación

### MQTT

| Parámetro | Valor |
|---|---|
| Broker | `telecomunicaciones.ddns.net` |
| Puerto MQTT | `2480` |
| Usuario | `telecomunicaciones` |
| Contraseña  | `cohorte*2024` |

### LoRa

- Banda: 433 MHz
- Comunicación punto a punto entre nodos ESP32

---

## 🧪 Ejemplo de flujo (escenario real)

1. MQ135 detecta gas → genera JSON con valor alto
2. JSON llega al nodo receptor → publica `grupoAQI/gas`
3. Node-RED detecta que `gas > 400` → publica comando en `grupoAQI/ordenes`
4. Nodo actuador recibe el JSON → activa ventilador por PWM + baliza LED

---

## 🛠️ Requisitos de integración local

Para reproducir todo el entorno en local (fuera de la nube), se necesita:

- Mosquitto Broker en puerto 1883
- Node-RED con acceso a la red
- MariaDB en localhost:3306 con tabla de datos definida
- Copia de los `.ino` o proyectos PlatformIO en nodos

---

## 🧩 Integración en contenedores (Docker)

Los siguientes servicios están disponibles en la nube:

| Servicio | URL |
|---|---|
| Portainer | http://telecomunicaciones.ddns.net:8080/portainer |
| Node-RED | http://telecomunicaciones.ddns.net:8080/nodered |
| Node-RED UI | http://telecomunicaciones.ddns.net:8080/nodered/ui |
| Grafana | http://telecomunicaciones.ddns.net:8080/grafana  |
| MariaDB | telecomunicaciones.ddns.net:6034 (acceso por gestor externo) |

---

## 📎 Archivos relacionados

- [`nodo-sensado.md`](./nodo-sensado.md)
- [`nodo-receptor.md`](./nodo-receptor.md)
- [`nodo-actuador.md`](./nodo-actuador.md)
- [`arquitectura.md`](./arquitectura.md)

---

## ✅ Estado actual (junio 2025)

✔ Comunicación entre nodos implementada  
✔ MQTT operativo y testeado  
✔ Node-RED suscripto a topics 
✔ Dashboard con control parcial

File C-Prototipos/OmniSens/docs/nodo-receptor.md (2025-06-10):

# Nodo Receptor - OmniSens

Este microcontrolador (ESP32) cumple el rol de **Concentrador** entre la red LoRa y la red IP/MQTT. Se encarga de:

- Recibir los datos sensados enviados por LoRa.
- Publicarlos en la nube mediante el broker MQTT.
- Recibir comandos desde el dashboard (por MQTT) y reenviarlos vía LoRa al nodo actuador.

---

## 🔌 Funcionalidad principal

| Acción | Descripción |
|---|---|
| **LoRa RX** | Recibe JSON con datos sensados desde `microcontrolador-sensado`. |
| **MQTT TX** | Publica esos datos en diferentes `topics` del broker. |
| **MQTT RX** | Escucha temas para recibir comandos del dashboard. |
| **LoRa TX** | Reenvía comandos JSON por LoRa al nodo actuador. |

---

## 🌐 MQTT

| Parámetro | Valor |
|---|---|
| Broker | `telecomunicaciones.ddns.net` |
| Puerto MQTT | `2480` |
| Usuario | `telecomunicaciones` |
| Contraseña | `cohorte*2024` |
| Topic RX | `grupoAQI/ordenes` |
| Topic TX | `grupoAQI/datos/temperatura`, etc. |

---

## 🔁 Flujo general del nodo receptor

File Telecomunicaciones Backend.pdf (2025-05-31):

### Datos del BackEnd para Proyecto Integrador II y Modulo Full Stack

## Listado de URL

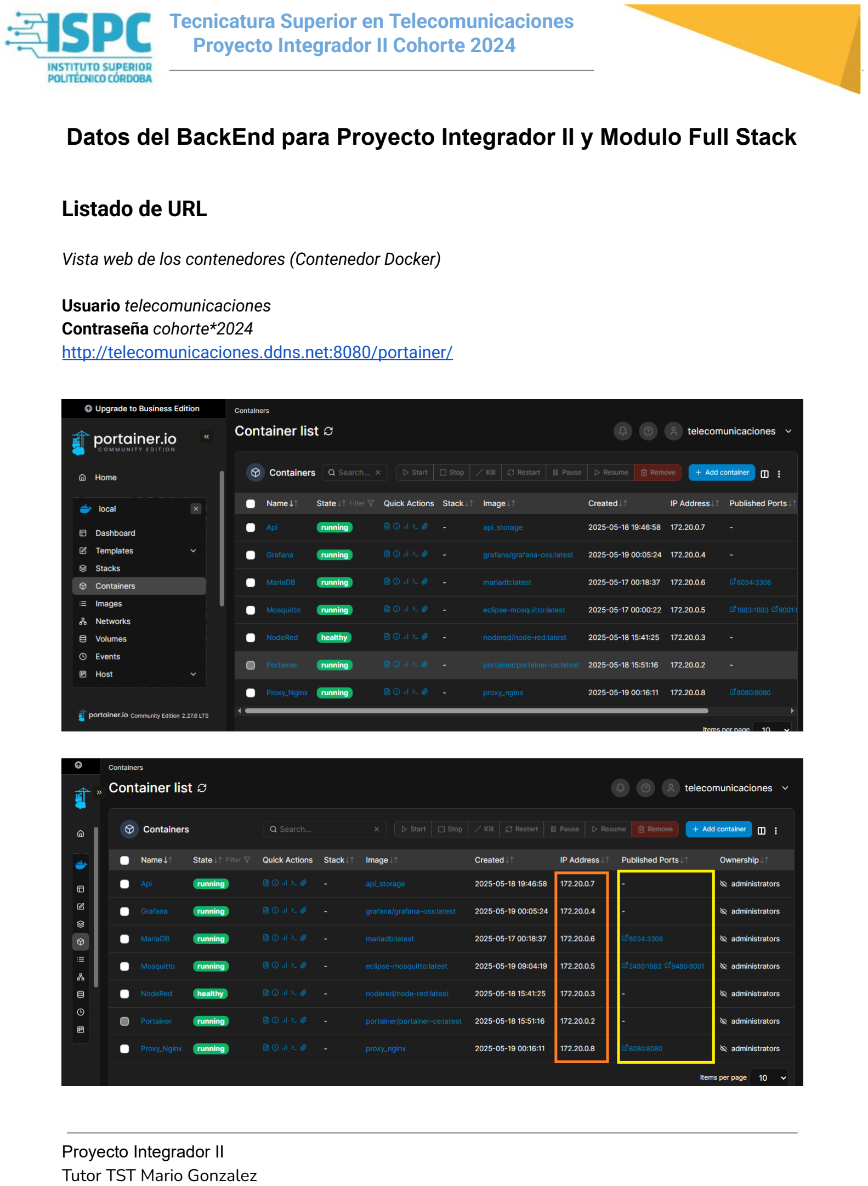
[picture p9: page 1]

atronica | Tecnicatura Superior en Telecomunicaciones Proyecto Integrador II Cohorte 2024

Vista web de los contenedores (Contenedor Docker)

Usuario telecomunicaciones
Contraseña cohorte*2024
http://telecomunicaciones.ddns.net:8080/portainer/

Proyecto Integrador II
Tutor TST Mario Gonzalez

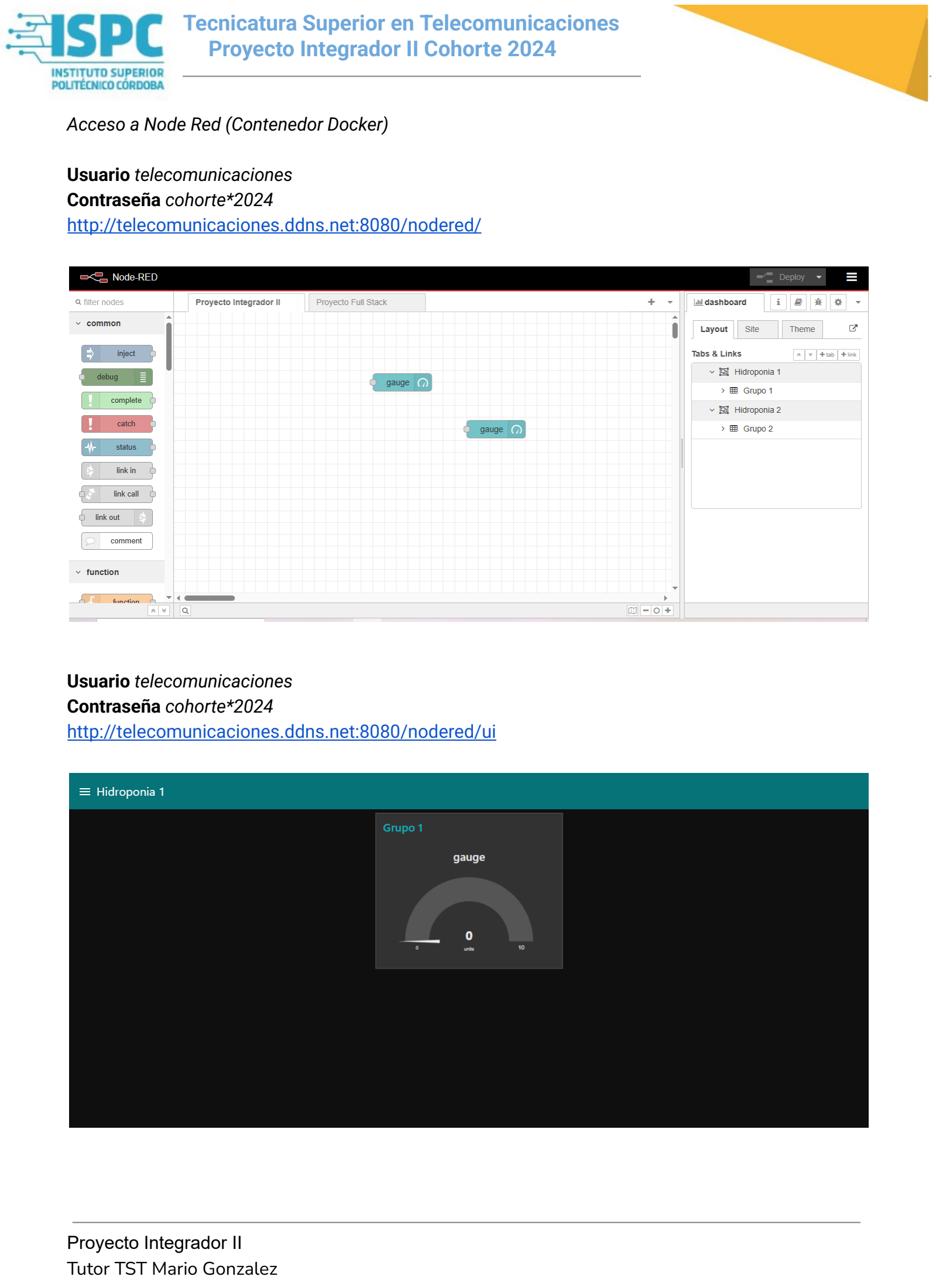
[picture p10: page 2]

Acceso a Node Red (Contenedor Docker)

Usuario telecomunicaciones
Contraseña cohorte*2024
http://telecomunicaciones.ddns.net:8080/nodered/

Usuario telecomunicaciones
Contraseña cohorte*2024
http://telecomunicaciones.ddns.net:8080/nodered/ui

Proyecto Integrador II

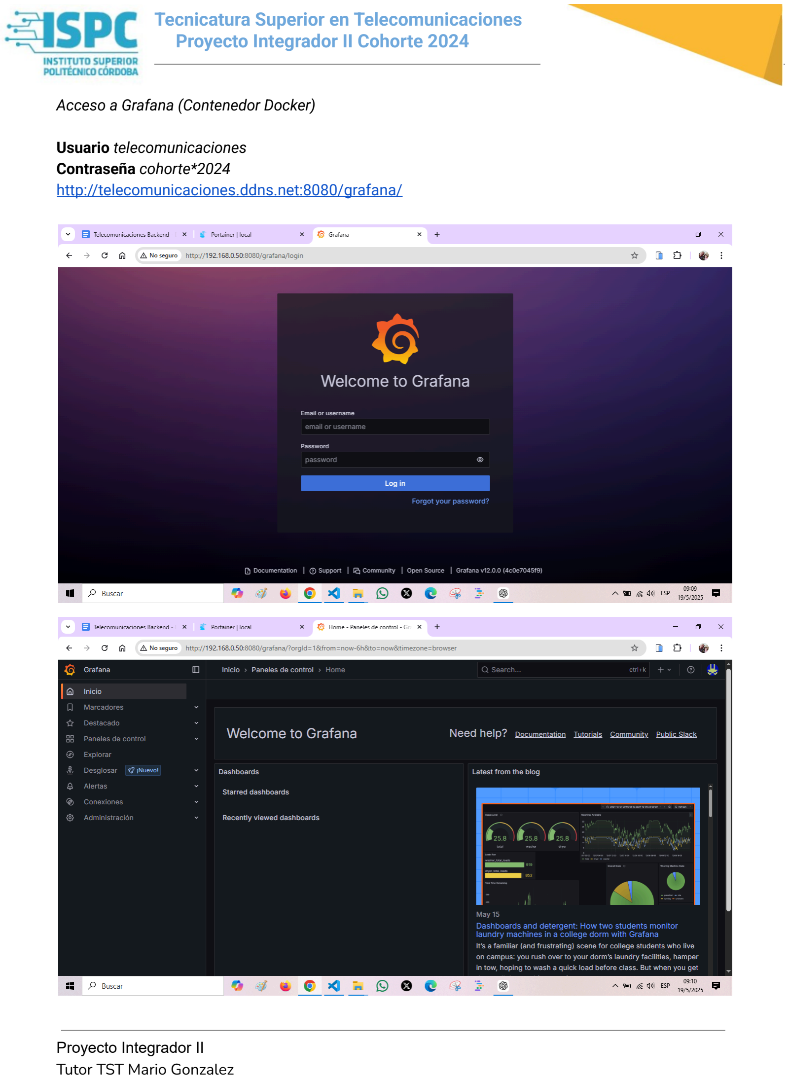
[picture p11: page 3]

Acceso a Grafana (Contenedor Docker)

Usuario telecomunicaciones
Contraseña cohorte*2024
http://telecomunicaciones.ddns.net:8080/grafana/

Proyecto Integrador II

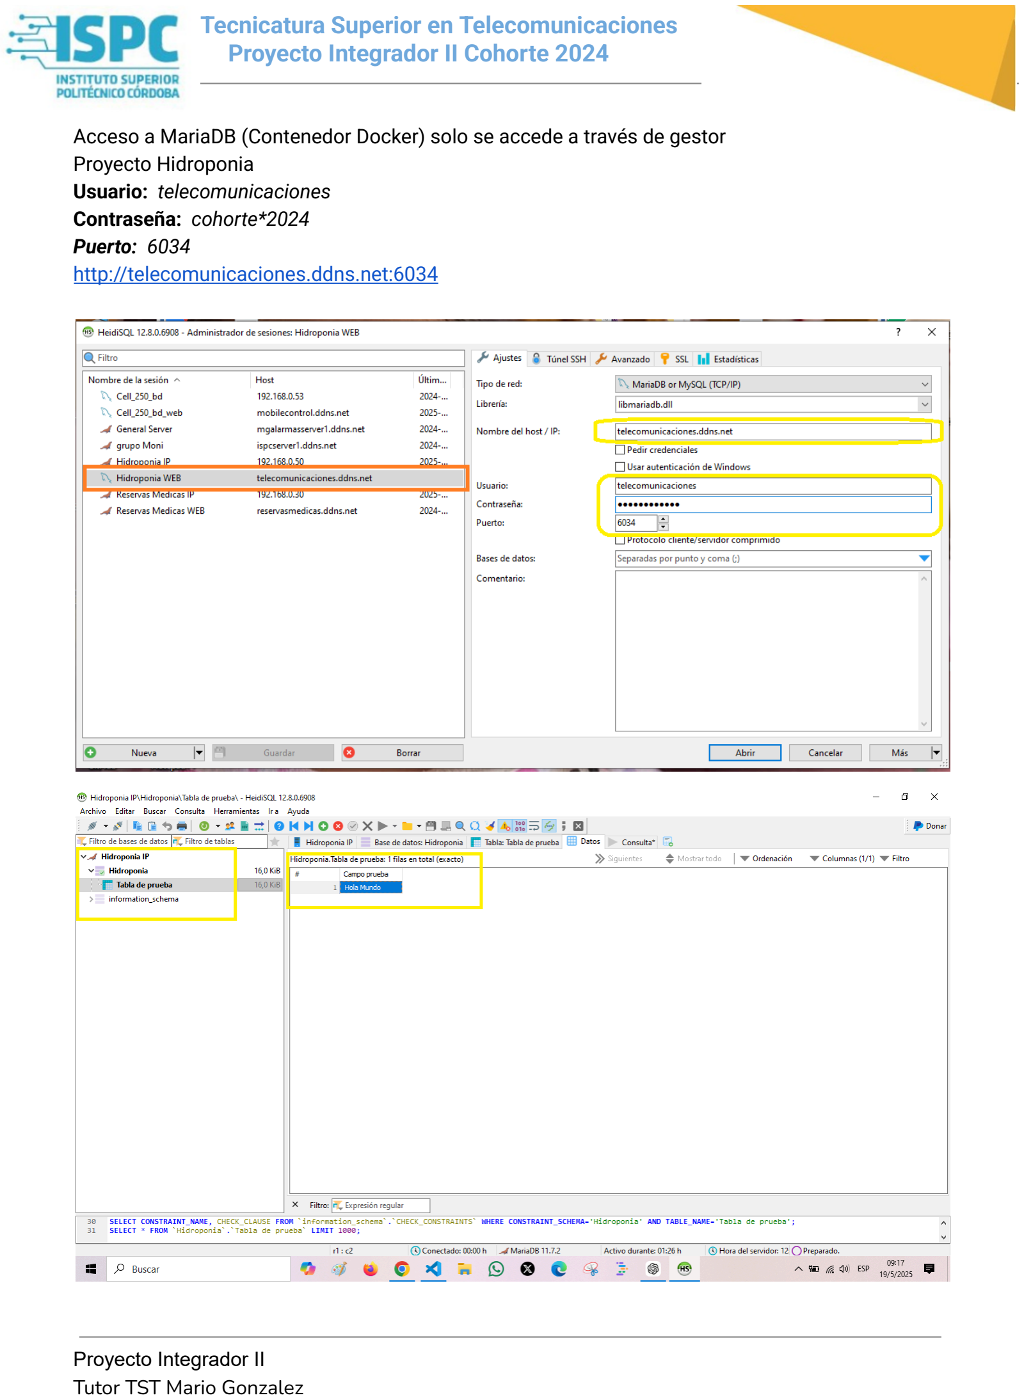
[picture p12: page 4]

Acceso a MariaDB (Contenedor Docker) solo se accede a través de gestor Proyecto Hidroponia
Usuario: telecomunicaciones
Contraseña: cohorte*2024
Puerto: 6034
http://telecomunicaciones.ddns.net:6034

Proyecto Integrador II

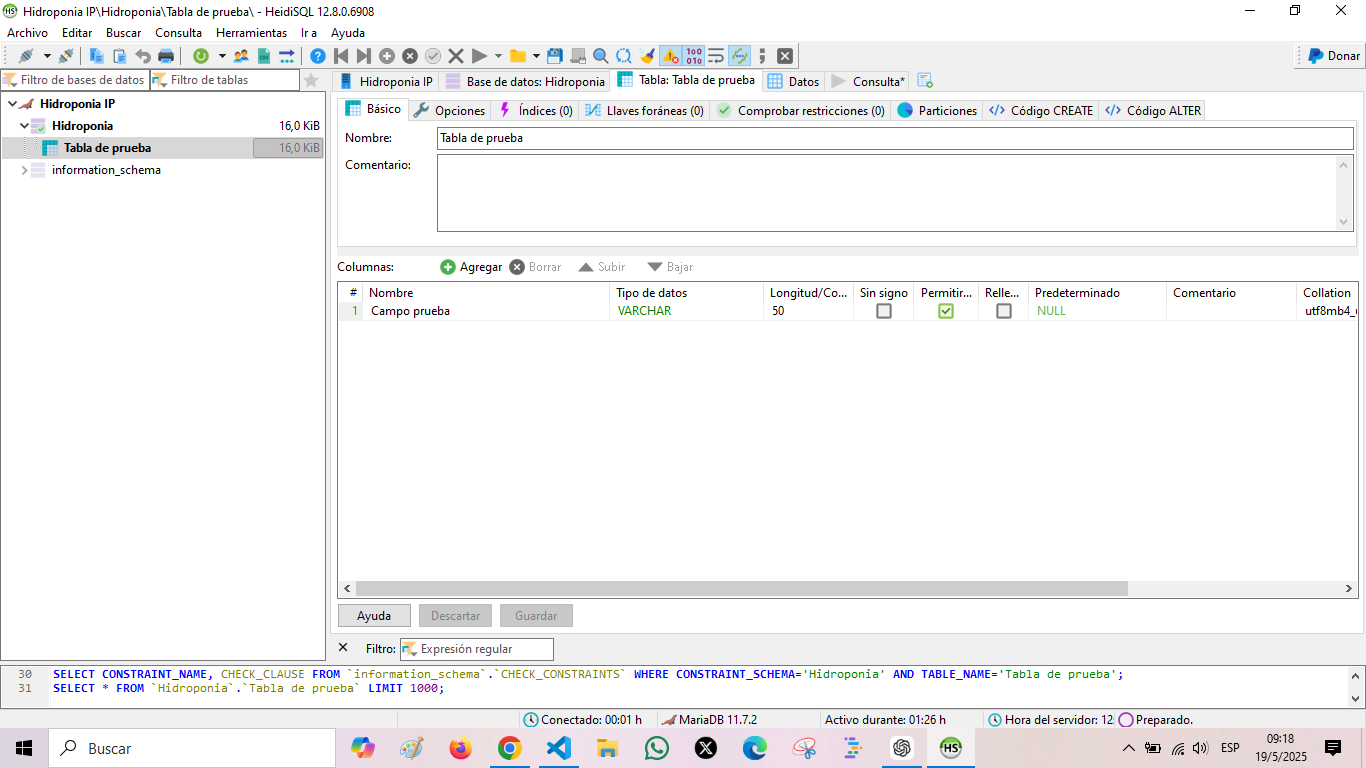
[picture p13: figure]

Acceso a MariaDB (Contenedor Docker) solo se accede a través de gestor Proyecto Full Stack Grupo Opalo
Nombre base de datos: OpaloDB
Usuario: OpaloDB
Contraseña: cohorte*2024
Puerto: 6034
http://telecomunicaciones.ddns.net:6034

Acceso a MariaDB (Contenedor Docker) solo se accede a través de gestor Proyecto Full Stack Grupo AQI
Nombre base de datos: AQI_DB
Usuario: AQI_DB
Contraseña: cohorte*2024
Puerto: 6034
http://telecomunicaciones.ddns.net:6034

Proyecto Integrador II

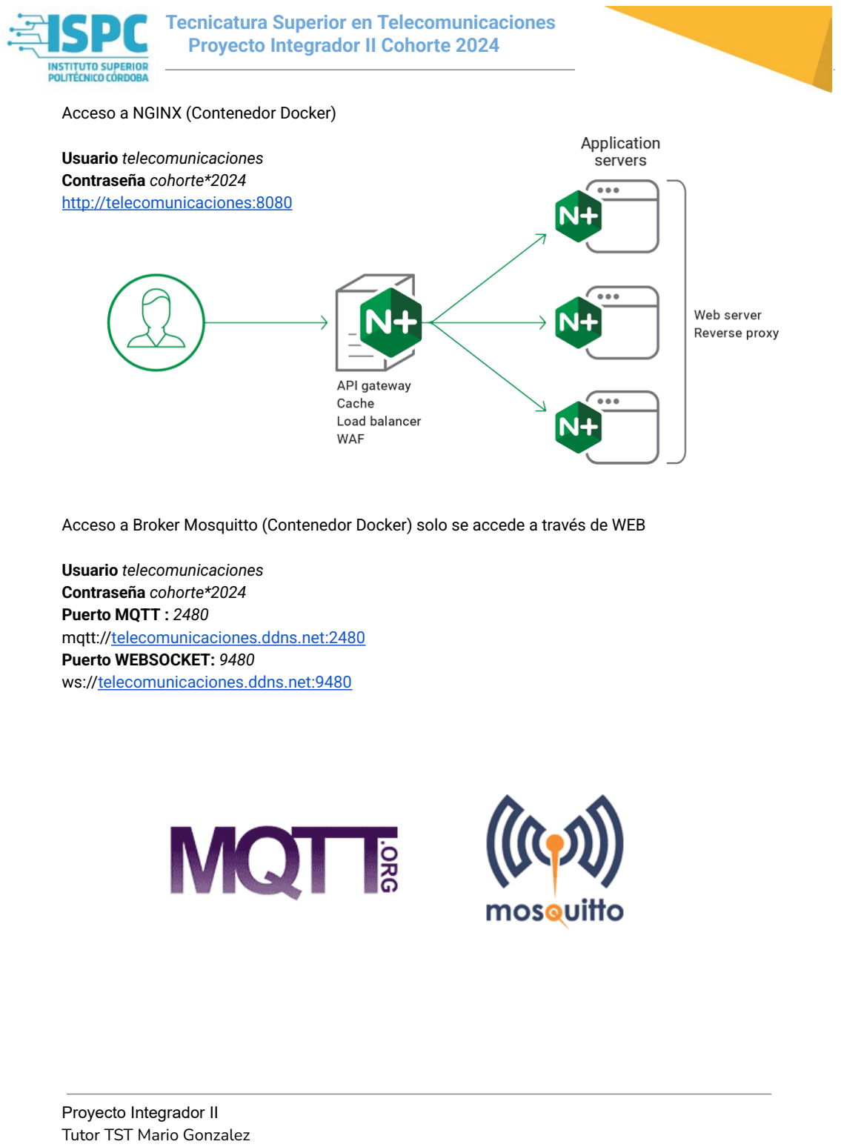
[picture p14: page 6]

Acceso a NGINX (Contenedor Docker)

Usuario telecomunicaciones Contraseña cohorte*2024
http://telecomunicaciones:8080

Acceso a Broker Mosquitto (Contenedor Docker) solo se accede a través de WEB

Usuario telecomunicaciones
Contraseña cohorte*2024
Puerto MQTT : 2480
mqtt://telecomunicaciones.ddns.net:2480 Puerto WEBSOCKET: 9480
ws://telecomunicaciones.ddns.net:9480

Proyecto Integrador II

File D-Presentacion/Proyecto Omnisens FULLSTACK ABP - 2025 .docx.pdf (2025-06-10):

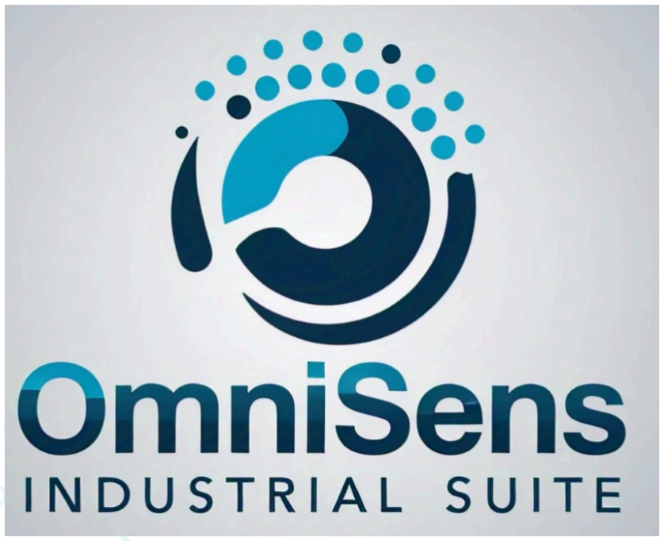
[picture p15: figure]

## “Sistema de monitoreo y control ambiental”

Integrantes:

- Fernando Gimenez Coria | - Paola Pantoja
- Diego Ares | -Emma Vilma Gutierrez
- Macarena Carballo | - Romina Huk
- Leandro Roldan | - Raul Jara
- Juan Diego Gonzalez Antoniazzi

Profesores:

- Mario Gonzalez
- Jorge Morales
- Alejandro Mainero

### 1. NOMBRE DEL PROYECTO: OmniSens – Sistema de Monitoreo y Control

Ambiental Industrial

Este proyecto se centra en el desarrollo de un sistema integral para la supervisión y gestión de parámetros ambientales en entornos industriales. El sistema permite la adquisición de datos en tiempo real, su procesamiento y la toma de decisiones automatizadas para optimizar el ambiente de trabajo y garantizar la seguridad y eficiencia operativa.

### 2. TIPO DE PROYECTO: Tecnológico

OmniSens es un proyecto tecnológico que integra hardware y software para ofrecer soluciones IoT aplicadas al monitoreo y control ambiental en la industria

### 3. ESPACIO CURRICULAR O ESPACIOS PARTICIPANTES EN EL MÓDULO:

- Arquitectura y Conectividad
- Sistemas de Control y Servicios
- Plataformas
Estos espacios curriculares pertenecen al módulo Programador FullStack IoT de la Tecnicatura Superior en Telecomunicaciones del ISPC.
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

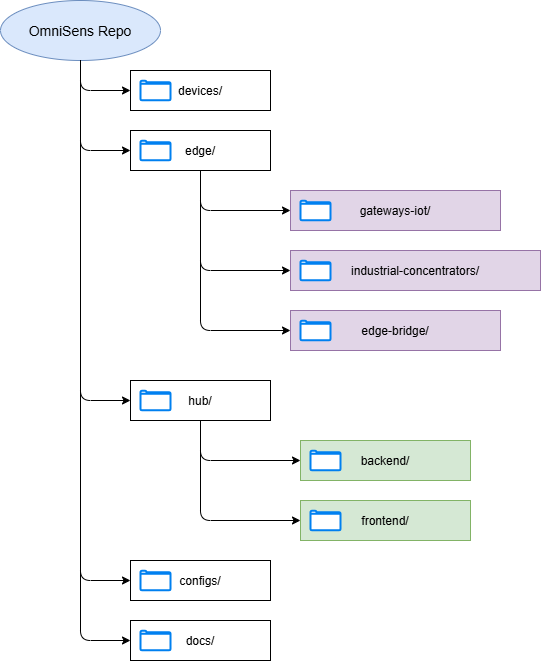
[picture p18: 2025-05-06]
C-Prototipos/OmniSens/docs/assets/Estructura_repo.drawio.png

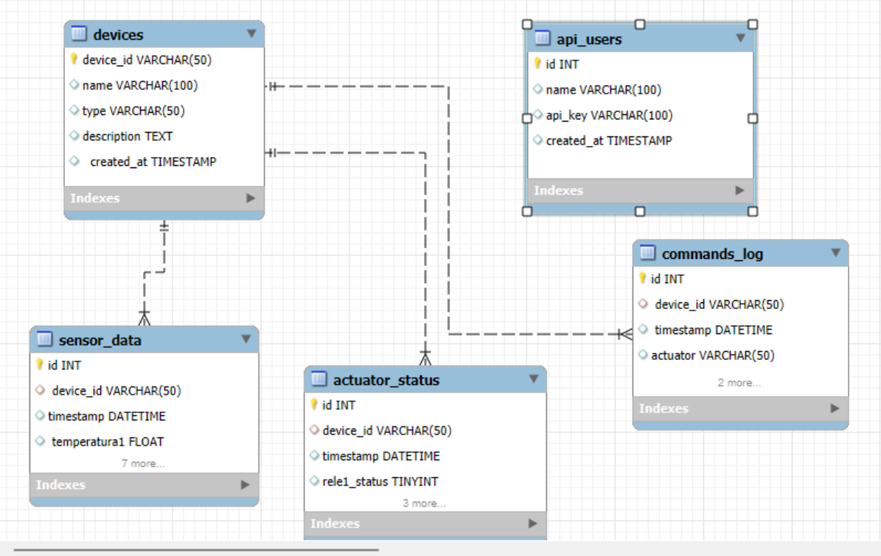
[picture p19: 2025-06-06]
C-Prototipos/OmniSens/Base de datos/images.png

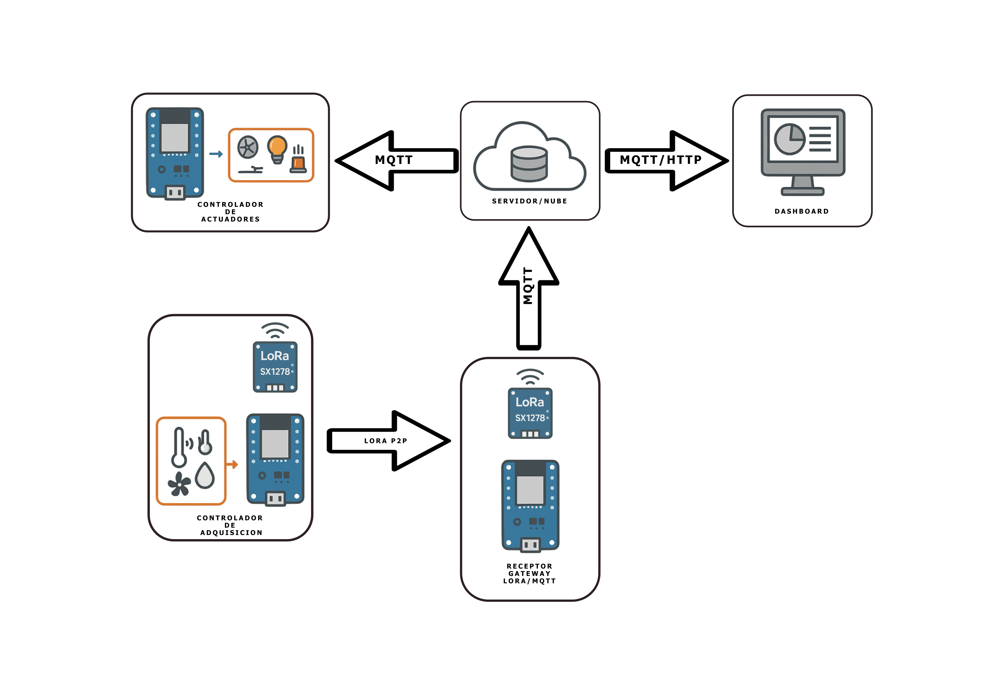
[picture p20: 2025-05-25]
E-Assets/arquitectura_proyecto.png

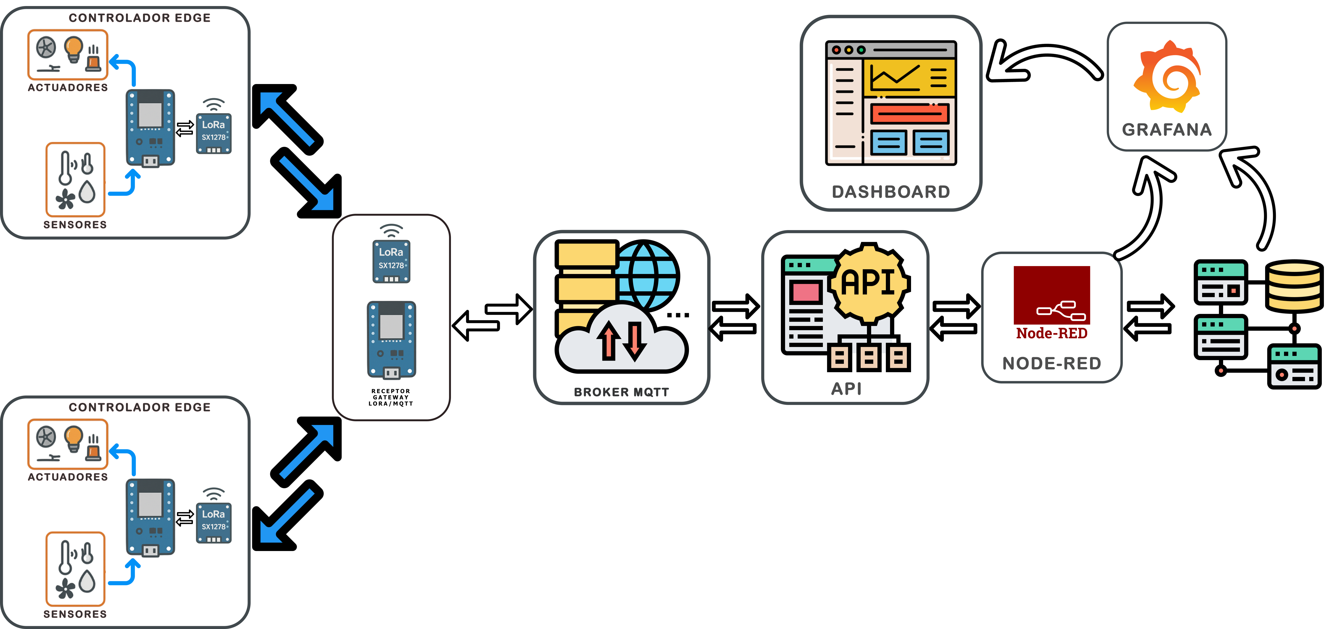
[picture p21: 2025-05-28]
E-Assets/arquitectura_proyecto_ACTUALIZADA.png

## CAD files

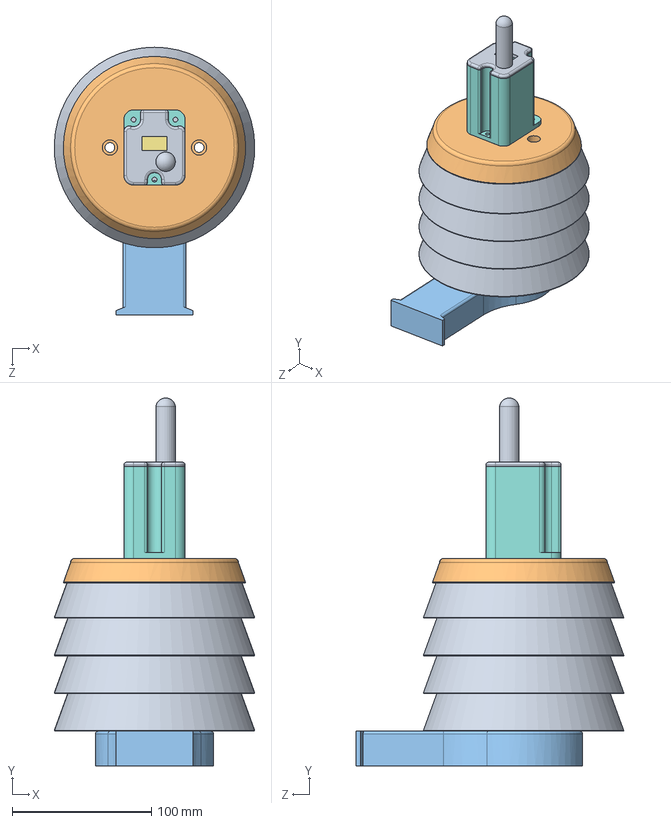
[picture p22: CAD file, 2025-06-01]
C-Prototipos/OmniSens/docs/Dispositivos/Modelos 3D/modelo_prototipo.SLDASM
143.8 x 264.0 x 191.9 mm
modulo_porta_componente x 4
Tapa_superior_con_ventana
carcasa_sup_base
base_baliza_LDR_LoRa
modulo_LoRa
tiraLedWS2812
sensor LDR
carcasa_modulo_baliza
tapa_sup_antena

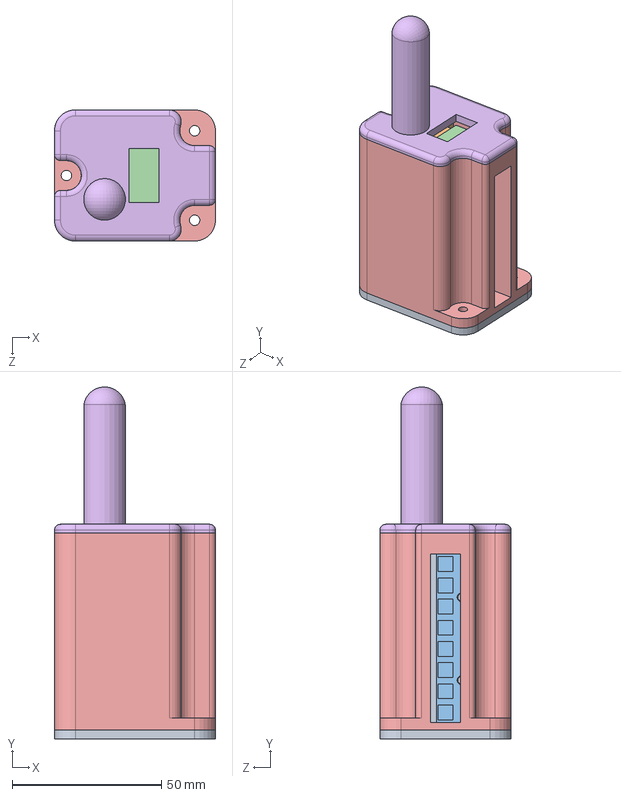
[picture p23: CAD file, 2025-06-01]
C-Prototipos/OmniSens/docs/Dispositivos/Modelos 3D/modulo_baliza_Lora.SLDASM
54.0 x 118.0 x 44.0 mm
base_baliza_LDR_LoRa
modulo_LoRa
tiraLedWS2812
sensor LDR
carcasa_modulo_baliza
tapa_sup_antena

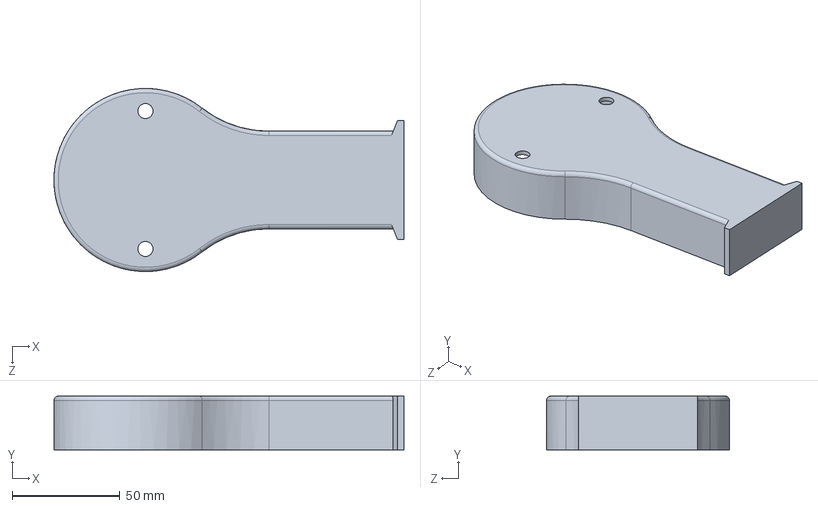
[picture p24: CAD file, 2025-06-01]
C-Prototipos/OmniSens/docs/Dispositivos/Modelos 3D/carcasa_sup_base.SLDPRT
162.4 x 25.0 x 84.9 mm

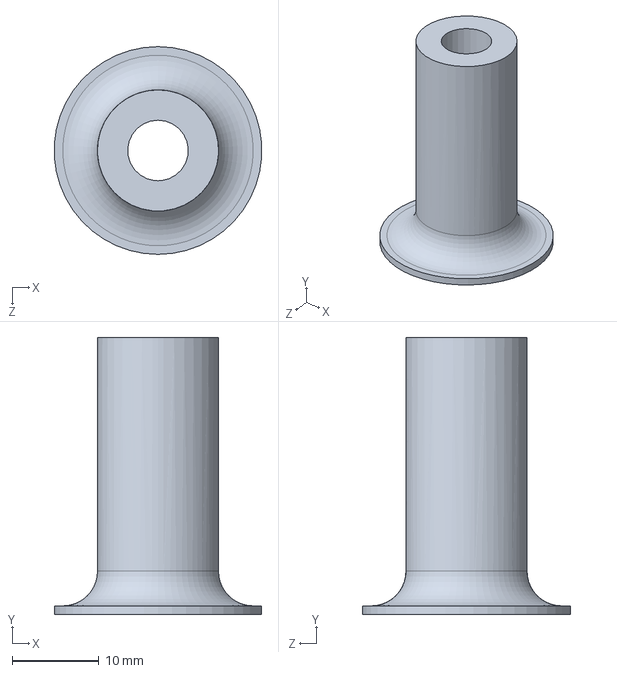
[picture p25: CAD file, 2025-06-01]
C-Prototipos/OmniSens/docs/Dispositivos/Modelos 3D/separador_base.SLDPRT
23.9 x 32.0 x 24.0 mm

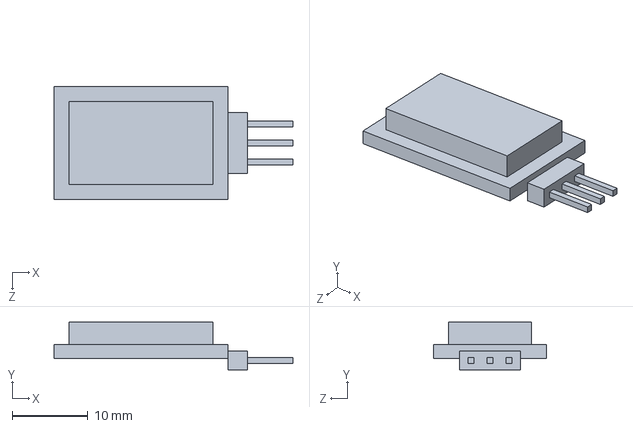
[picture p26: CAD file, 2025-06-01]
C-Prototipos/OmniSens/docs/Dispositivos/Modelos 3D/sensor LDR.SLDPRT
31.6 x 6.34 x 15.0 mm

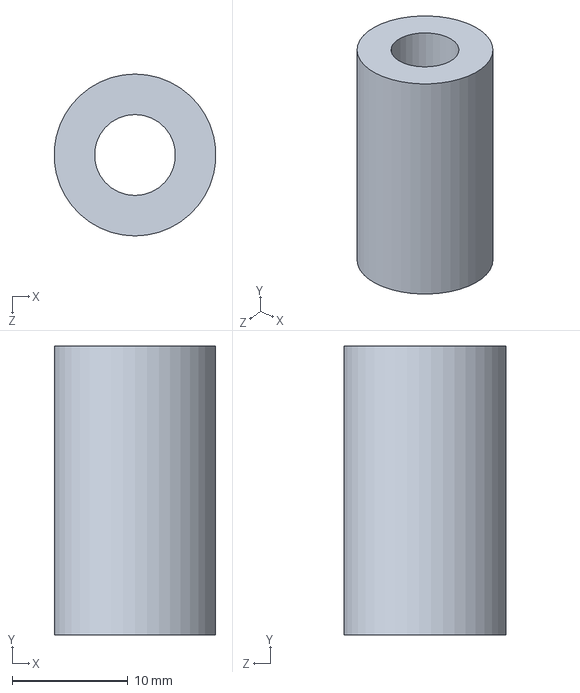
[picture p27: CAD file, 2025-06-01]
C-Prototipos/OmniSens/docs/Dispositivos/Modelos 3D/separador_cuerpos.SLDPRT
14.0 x 25.0 x 14.0 mm

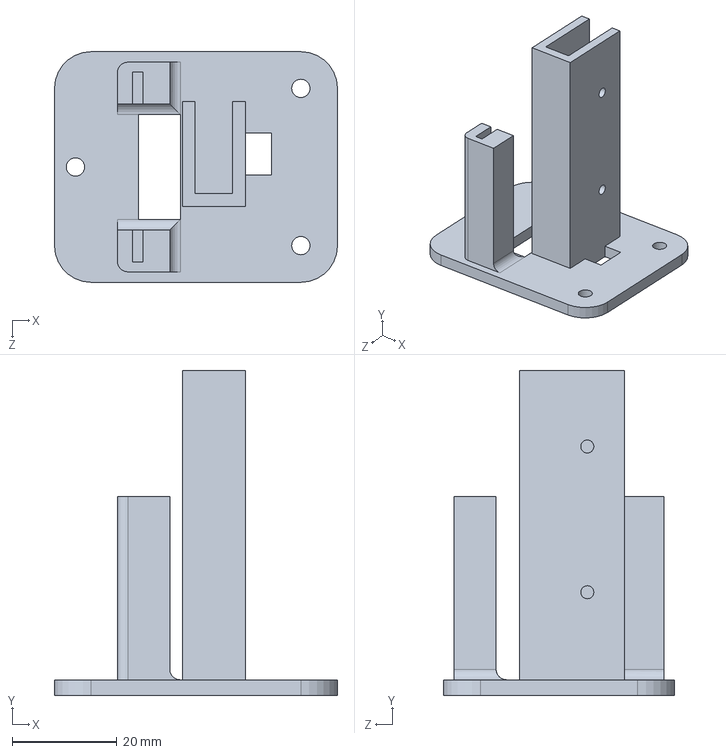
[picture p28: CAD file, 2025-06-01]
C-Prototipos/OmniSens/docs/Dispositivos/Modelos 3D/base_baliza_LDR_LoRa.SLDPRT
54.0 x 62.0 x 44.0 mm

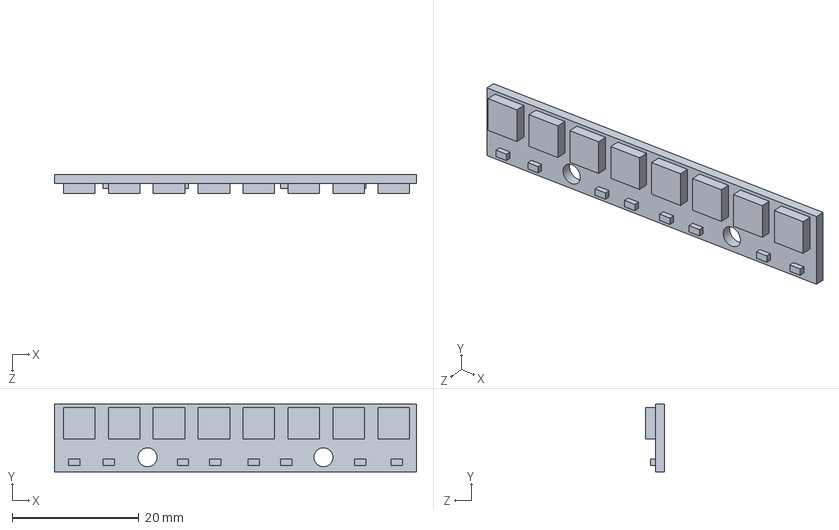
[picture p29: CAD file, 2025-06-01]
C-Prototipos/OmniSens/docs/Dispositivos/Modelos 3D/tiraLedWS2812.SLDPRT
57.2 x 10.7 x 3.00 mm

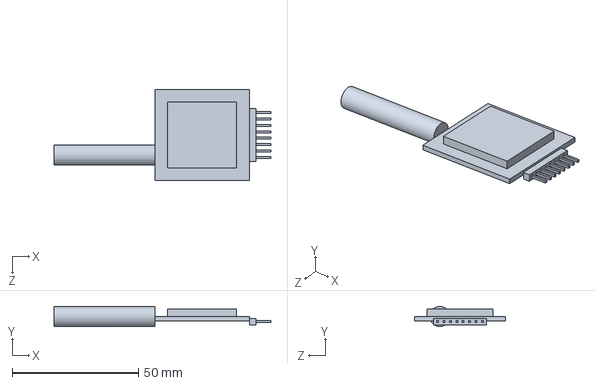
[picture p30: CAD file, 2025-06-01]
C-Prototipos/OmniSens/docs/Dispositivos/Modelos 3D/modulo_LoRa.SLDPRT
86.1 x 8.00 x 36.0 mm

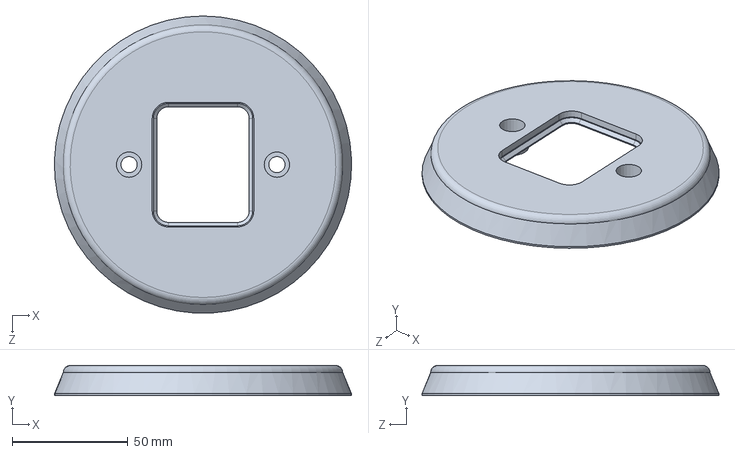
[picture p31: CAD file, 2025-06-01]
C-Prototipos/OmniSens/docs/Dispositivos/Modelos 3D/Tapa_superior_con_ventana.sldprt
128.6 x 13.0 x 128.6 mm

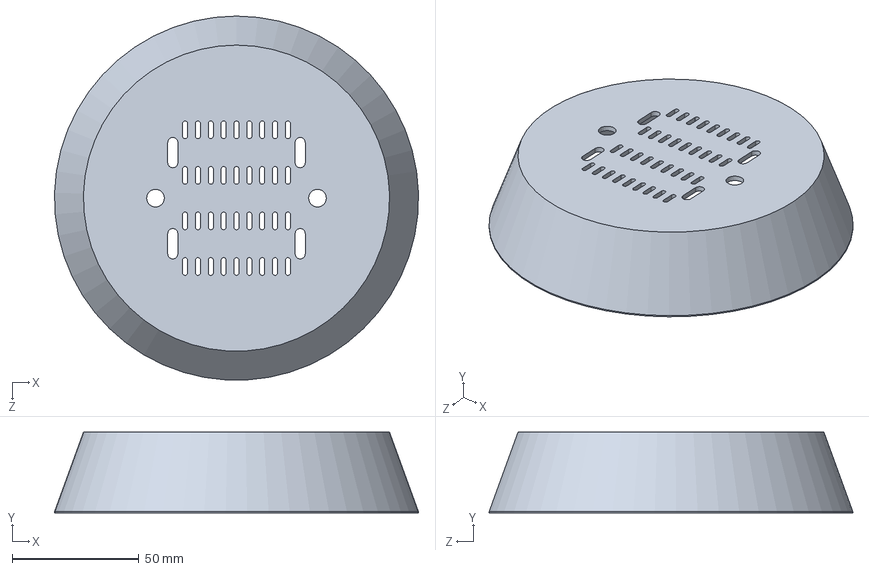
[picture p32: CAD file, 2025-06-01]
C-Prototipos/OmniSens/docs/Dispositivos/Modelos 3D/modulo_porta_componente.SLDPRT
143.8 x 32.0 x 143.8 mm

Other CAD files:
C-Prototipos/OmniSens/docs/Dispositivos/Modelos 3D/carcasa_modulo_baliza.SLDPRT
C-Prototipos/OmniSens/docs/Dispositivos/Modelos 3D/tapa_sup_antena.SLDPRT
C-Prototipos/OmniSens/docs/Dispositivos/Modelos 3D/Tapa_superior_con_ventana.3mf
C-Prototipos/OmniSens/docs/Dispositivos/Modelos 3D/Tapa_superior_con_ventana.STL
C-Prototipos/OmniSens/docs/Dispositivos/Modelos 3D/carcasa_sup_base.3mf
C-Prototipos/OmniSens/docs/Dispositivos/Modelos 3D/carcasa_sup_base.STL
C-Prototipos/OmniSens/docs/Dispositivos/Modelos 3D/modulo_porta_componente.3mf
C-Prototipos/OmniSens/docs/Dispositivos/Modelos 3D/modulo_porta_componente.STL
C-Prototipos/OmniSens/docs/Dispositivos/Modelos 3D/separador_base.STL
C-Prototipos/OmniSens/docs/Dispositivos/Modelos 3D/separador_cuerpos.STL

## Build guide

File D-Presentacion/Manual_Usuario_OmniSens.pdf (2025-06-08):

## Manual de Usuario Proyecto OmniSens

Manual de Usuario OmniSens

### 1. Introduccion

OmniSens es un sistema de monitoreo y control ambiental que permite supervisar variables como

temperatura, humedad, presion, gases y luminosidad en tiempo real. Este manual guia al usuario

en la instalacion, configuracion y uso del sistema.

### 2. Requisitos del Sistema

Sensores compatibles (DHT22, MQ-135, BMP280, etc.)

Modulos LoRa para nodos y gateway

Microcontroladores (ESP32, Arduino)

Conexion a internet para el servidor

Acceso a navegador web para visualizar la interfaz

### 3. Instalacion del Hardware

1. Conecte los sensores al microcontrolador siguiendo las instrucciones del repositorio.
2. Asegure el modulo LoRa al microcontrolador (SPI).
3. Coloque el nodo concentrador con un gateway LoRa conectado a internet.

### 4. Configuracion del Software

1. Clone el repositorio desde GitHub.
2. Cargue el firmware en los nodos con el codigo del directorio 'edge/'.
3. Instale Node-RED, Mosquitto MQTT y Grafana en el servidor o Raspberry Pi.
4. Configure los flujos de Node-RED siguiendo los ejemplos del repositorio.

### 5. Interfaz de Usuario

Acceda a la interfaz web mediante un navegador ingresando la IP del servidor.

Visualice graficos en tiempo real de las variables ambientales.

Reciba alertas si los valores superan umbrales definidos.

Active o desactive actuadores desde la interfaz.

### 6. Uso del Sistema

Inicie los nodos sensores para comenzar el monitoreo.

Supervise los datos a traves de Grafana.

Configure reglas automaticas en Node-RED para controlar los actuadores.

Consulte los historicos almacenados en la base de datos.

### 7. Solucion de Problemas

No recibe datos: Verifique conexion LoRa y MQTT.

Interfaz no carga: Compruebe que el servidor este encendido.

No funcionan los actuadores: Revise la configuracion de Node-RED y conexiones fisicas.

### 8. Contacto y Soporte

Para soporte, consultar el repositorio oficial:

https://github.com/Programador-FullStack-IoT/Modulo-Programador-FullStack-IoT-TST-2024

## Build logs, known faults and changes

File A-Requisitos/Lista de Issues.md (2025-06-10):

# 📂 Requisitos y Fases del Proyecto

> **Carpeta:** `A-Requisitos`  
> **Descripción:** Esta sección detalla los requisitos y el plan de desarrollo de la plataforma **OmniSens**, organizado en fases incrementales.

---

## 🚦 Fases del Proyecto

### 🔵 Fase 1: Prototipo Funcional de Sensado y Control

> **Objetivo:** Construir y validar el hardware principal, asegurando la recolección de datos y el control de actuadores.

- [ ] **Lectura de sensores:** temperatura, humedad, presión, luminosidad, gases.
- [ ] **Comunicación LoRa:** entre microcontroladores Edge y el concentrador.
- [ ] **Control de actuadores:** extractores, luces, alarmas.
- [ ] **Documentación:** arquitectura del sistema en [`docs/architecture.md`](../docs/architecture.md).

---

### 🟢 Fase 2: Backend y Base de Datos

> **Objetivo:** Desarrollar la infraestructura de servidor para recibir, almacenar, procesar y visualizar datos.

- [ ] **Definir base de datos:** esquemas para sensores y eventos.
- [ ] **API del servidor:** recepción de MQTT, autenticación, gestión de dispositivos/usuarios.
- [ ] **Node-RED:** procesamiento, análisis y respuestas automáticas.
- [ ] **Integración API + Node-RED:** transmisión de datos efectiva.
- [ ] **Grafana:** visualización de datos en tiempo real e históricos.
- [ ] **Validación e integración:** documentar en [`docs/integration.md`](../docs/integration.md).

---

### 🟡 Fase 3: Dashboard e Interfaz Web

> **Objetivo:** Crear una interfaz amigable para la interacción y control remoto.

- [ ] **Frontend:** desarrollo en `hub/frontend/` para visualizar y gestionar datos.
- [ ] **Integración con Grafana:** métricas en tiempo real.
- [ ] **Acciones remotas:** control desde la web.
- [ ] **Optimización UX:** experiencia intuitiva.

---

### 🟠 Fase 4: Integración y Pruebas

> **Objetivo:** Unificar componentes y realizar pruebas exhaustivas.

- [ ] **Conexión de módulos:** validar flujo de datos entre sensores, LoRa, MQTT, API y Dashboard.
- [ ] **Pruebas simuladas:** ajustar parámetros de rendimiento y respuesta.
- [ ] **Mejoras en Edge:** latencia y eficiencia.

---

### 🟣 Fase 5: Documentación y Escalado

> **Objetivo:** Finalizar documentación, facilitar colaboración y planificar el crecimiento futuro.

- [ ] **Documentación técnica:** guías de instalación en `docs/`.
- [ ] **Tutoriales y contribución:** facilitar integración de nuevos colaboradores.
- [ ] **Planificación de mejoras:** nuevos sensores y protocolos.

---

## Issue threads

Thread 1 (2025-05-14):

TK#1 Configuración inicial del repositorio

JDGA1997, 2025-05-14:
- [ ] Crear un archivo README.md detallado con la descripción del proyecto, objetivos y estructura.
- [ ] Configurar el archivo .gitignore para excluir archivos innecesarios del control de versiones
- [ ] Añadir un archivo LICENSE para definir el uso permitido del código
- [ ] Crear el archivo architecture.md con una descripción detallada de la arquitectura general del sistema

Closed 2025-06-19.

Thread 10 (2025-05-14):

Integrar y probar controlador de actuadores

JDGA1997, 2025-05-14:
Desarrollar el código para el microcontrolador que acciona extractores, luces, alarmas y balizas según los datos recibidos. Realizar pruebas básicas de funcionamiento y documentar en `edge/microcontrolador-actuador/`.

Closed 2025-06-19.

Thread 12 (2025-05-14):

Documentar conexiones y arquitectura inicial

JDGA1997, 2025-05-14:
Registrar en `docs/architecture.md` los diagramas, conexiones físicas y lógicas, y cualquier configuración relevante para la fase de prototipo funcional.

Closed 2025-06-19.

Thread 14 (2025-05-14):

Implementar endpoints para recepción de datos

JDGA1997, 2025-05-14:
Desarrollar y documentar los endpoints necesarios para que los microcontroladores envíen datos al backend. Asegurar el registro correcto en la base de datos.

Closed 2025-06-19.

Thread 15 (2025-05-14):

Configurar y probar la base de datos

JDGA1997, 2025-05-14:
Instalar, configurar y probar la base de datos para almacenamiento de datos históricos y en tiempo real. Documentar la estructura y los scripts de inicialización en `docs/integration.md`.Instalar, configurar y probar la base de datos para almacenamiento de datos históricos y en tiempo real. Documentar la estructura y los scripts de inicialización en `docs/integration.md`.

Closed 2025-06-19.

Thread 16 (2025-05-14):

TK#4 Dashboard e Interfaz Web

JDGA1997, 2025-05-14:
- [ ] Desarrollo del frontend (`hub/frontend/`) para visualización y control.
- [ ] Implementación de monitoreo en tiempo real y registro histórico.
- [ ] Integración de acciones de control remoto desde el dashboard.

Closed 2025-06-19.

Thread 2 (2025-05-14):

Crear un archivo README.md detallado con la descripción del proyecto, objetivos y estructura.

JDGA1997, 2025-05-14:
Redactar un archivo README.md en la raíz del repositorio que incluya:

-     Descripción general del sistema OmniSens y su propósito.
-     Objetivos principales del proyecto.
-     Lista de componentes clave y tecnologías utilizadas.
-     Estructura de carpetas y archivos del repositorio.
-     Instrucciones básicas de participación y contribución.

El README servirá como primer punto de referencia para colaboradores y usuarios interesados en el proyecto.

Closed 2025-05-28.

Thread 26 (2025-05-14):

Completar documentación técnica de todos los módulos

JDGA1997, 2025-05-14:
Asegurar que toda la documentación técnica esté actualizada y disponible en la carpeta `docs/`. Incluir diagramas, especificaciones, manuales de usuario y desarrollador.

Closed 2025-06-19.

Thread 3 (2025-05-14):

Configurar el archivo .gitignore para excluir archivos innecesarios del control de versiones

JDGA1997, 2025-05-14:
Crear y configurar el archivo .gitignore para evitar que archivos temporales, dependencias, configuraciones locales y otros archivos no relevantes sean incluidos en el control de versiones.

Asegurarse de cubrir:

-     Archivos de compilación y temporales.
-     Configuraciones de IDEs (ej: .vscode, .idea).
-     Dependencias externas y archivos sensibles. Esto ayuda a mantener el repositorio limpio y profesional desde el inicio.

Closed 2025-06-19.

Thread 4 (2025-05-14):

Añadir un archivo LICENSE para definir el uso permitido del código

JDGA1997, 2025-05-14:
Agregar un archivo LICENSE en la raíz del repositorio, seleccionando la licencia más adecuada (por ejemplo, MIT o GPL).
Este archivo debe establecer claramente los derechos, restricciones y responsabilidades de los usuarios y colaboradores respecto al código fuente del proyecto.

pleroldan, 2025-06-19:
Se sugiere Creative Commons BY-NC-SA

La licencia Creative Commons BY-NC-SA es una opción que permite compartir y modificar un trabajo, pero con ciertas restricciones:

    BY (Atribución): Quien use tu obra debe dar crédito al autor original.

    NC (No Comercial): No se permite el uso comercial de la obra ni de sus derivados.

    SA (Compartir Igual): Si alguien modifica tu obra, debe distribuirla bajo la misma licencia.

Esto significa que otros pueden copiar, adaptar y compartir tu proyecto, pero no pueden venderlo ni usarlo con fines comerciales. Además, cualquier modificación debe mantenerse bajo la misma licencia, asegurando que las versiones derivadas sigan siendo de acceso libre y no comercial

Closed 2025-06-19.

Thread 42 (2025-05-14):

TK#12 Agregar ejemplos de configuración

JDGA1997, 2025-05-14:
**Contexto:**
La integración con distintos entornos industriales requiere ejemplos claros de configuración.

**Objetivo:**
Ampliar los ejemplos de configuración de red y protocolos en la carpeta `/configs/`.

**Tareas:**
- Añadir más ejemplos basados en distintos escenarios.
- Explicar cada parámetro relevante en la documentación.

Closed 2025-05-25.

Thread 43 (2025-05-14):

Crear ejemplos de configuración de red y protocolos en la carpeta configs/.

JDGA1997, 2025-05-14:
**Contexto:**
Cada despliegue puede requerir configuraciones de red y protocolos específicas.

**Objetivo:**
Proveer ejemplos prácticos de archivos de configuración de red y protocolos industriales.

**Tareas:**
- Crear ejemplos funcionales en `/configs/`.
- Documentar su uso en `docs/integration.md`.

Closed 2025-05-25.

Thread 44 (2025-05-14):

Documentar las configuraciones en docs/configuration.md.

JDGA1997, 2025-05-14:
**Contexto:**
La documentación de configuración es clave para replicar y mantener el sistema.

**Objetivo:**
Redactar documentación detallada de todas las configuraciones necesarias.

**Tareas:**
- Documentar parámetros y archivos de configuración.
- Incluir ejemplos y explicaciones.
- Mantener actualizada la documentación ante cambios.

Closed 2025-05-25.

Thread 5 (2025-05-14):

Crear el archivo architecture.md con una descripción detallada de la arquitectura general del sistema

JDGA1997, 2025-05-14:
Elaborar el archivo docs/architecture.md describiendo:

-     La arquitectura general del sistema OmniSens (componentes principales y su interacción).
-     El flujo de datos entre sensores, microcontroladores, backend y dashboard.
-     Esquemas, diagramas y justificación de decisiones técnicas.

Este documento será clave para el desarrollo y futuras integraciones.

Closed 2025-06-19.

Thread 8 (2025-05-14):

Implementar microcontrolador para sensado y transmisión LoRa

JDGA1997, 2025-05-14:
Desarrollar el código para el microcontrolador encargado del sensado ambiental y la transmisión de datos vía LoRa. Documentar el flujo de datos y subir el código a `edge/microcontrolador-sensado/`.

Closed 2025-06-19.

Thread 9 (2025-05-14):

Desarrollar código para microcontrolador receptor

JDGA1997, 2025-05-14:
Implementar el firmware para el microcontrolador encargado de recibir datos LoRa. Asegurar la correcta recepción y validación de los datos transmitidos por el nodo de sensado. Documentar y subir el código a `edge/microcontrolador-receptor/`.

Closed 2025-06-19.

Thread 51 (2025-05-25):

Implementar pruebas para el firmware de los dispositivos IoT en devices/

JDGA1997, 2025-05-25:
**Contexto:**
Los dispositivos IoT requieren validación exhaustiva para asegurar la fiabilidad de los datos capturados.

**Objetivo:**
Desarrollar y ejecutar pruebas unitarias y de integración para el firmware de los dispositivos ubicados en la carpeta `/devices/`.

**Tareas:**
- Diseñar casos de prueba para cada tipo de sensor y actuador.
- Automatizar las pruebas si es posible.
- Documentar los resultados en `docs/tests.md`.

Closed 2025-05-25.

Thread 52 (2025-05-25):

Generar reportes de prueba y documentar los resultados en docs/tests.md.

JDGA1997, 2025-05-25:
**Contexto:**
Es fundamental contar con trazabilidad de las pruebas realizadas para futuras auditorías y mejoras.

**Objetivo:**
Consolidar y reportar los resultados de pruebas en un documento centralizado.

**Tareas:**
- Recopilar los resultados de todas las pruebas ejecutadas.
- Redactar un informe detallado.
- Guardar el informe en `docs/tests.md`.

Closed 2025-05-25.

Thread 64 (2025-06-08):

Implementar visualizaciones en Grafana conectado a base de datos MariaDB remota

diegote7, 2025-06-08:
Descripción
Necesitamos configurar Grafana para conectarse a nuestra base de datos MariaDB remota (actualmente accesible via HeidiSQL) y crear dashboards con visualizaciones útiles para monitorear los datos.
---

Requisitos/Tareas

- [ ] Configurar conexión a MariaDB en Grafana:
- [ ] Establecer conexión segura con la base de datos remota
- [ ] Verificar permisos de lectura necesarios
- [ ] Configurar el datasource en Grafana con los parámetros adecuados

---

Crear visualizaciones básicas:

- [ ] Gráficos de series temporales para datos con timestamp
- [ ] Tablas para datos tabulares
- [ ] Paneles de estado para métricas clave
- [ ] Gráficos de barras/tarta para datos categóricos

---

Optimización:

Asegurar que las consultas sean eficientes

Configurar intervalos de refresco adecuados

Implementar caching donde sea necesario

---

Documentación:

Documentar la configuración del datasource

Explicar el propósito de cada dashboard/visualización

Proporcionar ejemplos de consultas SQL usadas
---

Entregables
Datasource configurado y probado en Grafana

Dashboards con al menos [X] visualizaciones diferentes

Documentación técnica en el repositorio

Closed 2025-06-08.

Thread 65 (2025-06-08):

Configurar base de datos MariaDB remota accesible desde HeidiSQL y Grafana

diegote7, 2025-06-08:
Descripción
Necesitamos implementar una base de datos MariaDB remota que cumpla con los requisitos para:

Ser administrada mediante HeidiSQL

Servir como fuente de datos para Grafana

Garantizar acceso seguro y estable

Tareas Principales
1. Configuración del Servidor MariaDB Remoto
Instalar MariaDB en el servidor remoto

Configurar parámetros de red para acceso remoto seguro

Establecer reglas de firewall necesarias

Optimizar configuración my.cnf para el caso de uso

2. Seguridad y Accesos
Crear usuarios con privilegios específicos:

Usuario para administración (HeidiSQL)

Usuario de solo lectura para Grafana

Configurar conexión SSL si es requerida

Implementar backup automático inicial

3. Preparación para HeidiSQL
Documentar parámetros de conexión:

Host, puerto, credenciales

Configuración SSH si aplica

Verificar compatibilidad con versión HeidiSQL

Crear script de conexión básico

4. Preparación para Grafana
Crear usuario con permisos SELECT necesarios

Probar consultas básicas que usará Grafana

Documentar estructura de tablas relevantes

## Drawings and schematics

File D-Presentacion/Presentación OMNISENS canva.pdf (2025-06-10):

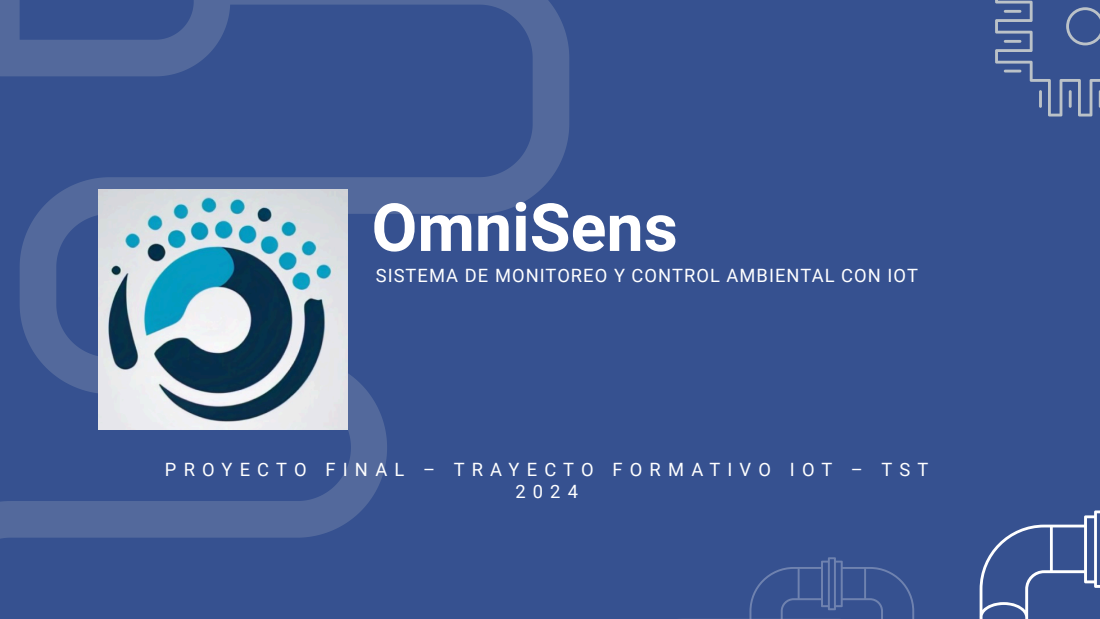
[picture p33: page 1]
OmniSens

SISTEMA DE MONITOREO Y CONTROL AMBIENTAL CON IOT

## Equipo de trabajo

## Fernando Gimenez Coria (@FerCbr)

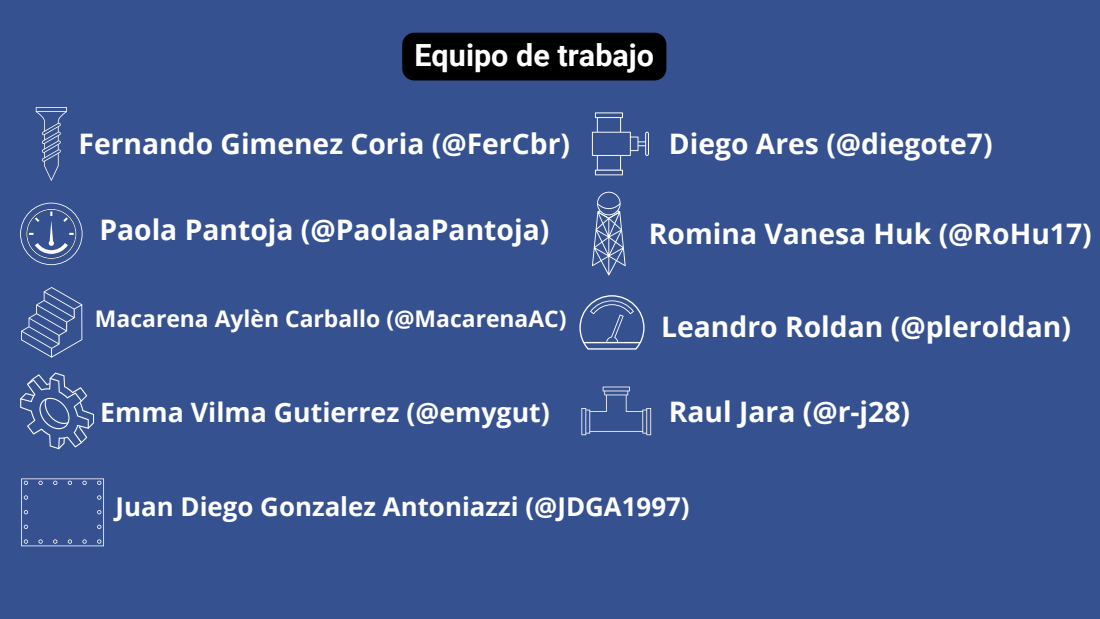
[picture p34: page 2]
Diego Ares (@diegote7); Macarena Aylèn Carballo (@MacarenaAC); Leandro Roldan (@pleroldan); Raul Jara (@r-j28)

Paola Pantoja (@PaolaaPantoja)

Romina Vanesa Huk (@RoHu17)

Emma Vilma Gutierrez (@emygut)

Juan Diego Gonzalez Antoniazzi (@JDGA1997)

## INTRODUCCION

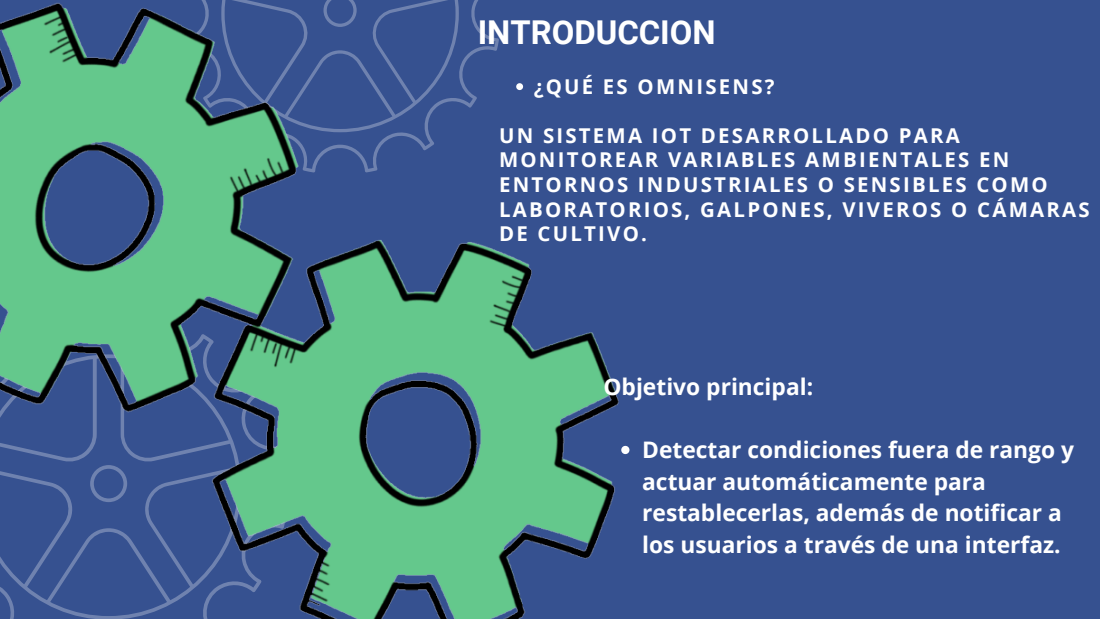
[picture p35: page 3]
Objetivo principal:

¿QUÉ ES OMNISENS?
UN SISTEMA IOT DESARROLLADO PARA
MONITOREAR VARIABLES AMBIENTALES EN
ENTORNOS INDUSTRIALES O SENSIBLES COMO
LABORATORIOS, GALPONES, VIVEROS O CÁMARAS
DE CULTIVO.

Detectar condiciones fuera de rango y
actuar automáticamente para
restablecerlas, además de notificar a
los usuarios a través de una interfaz.

## Motivación y Alcance

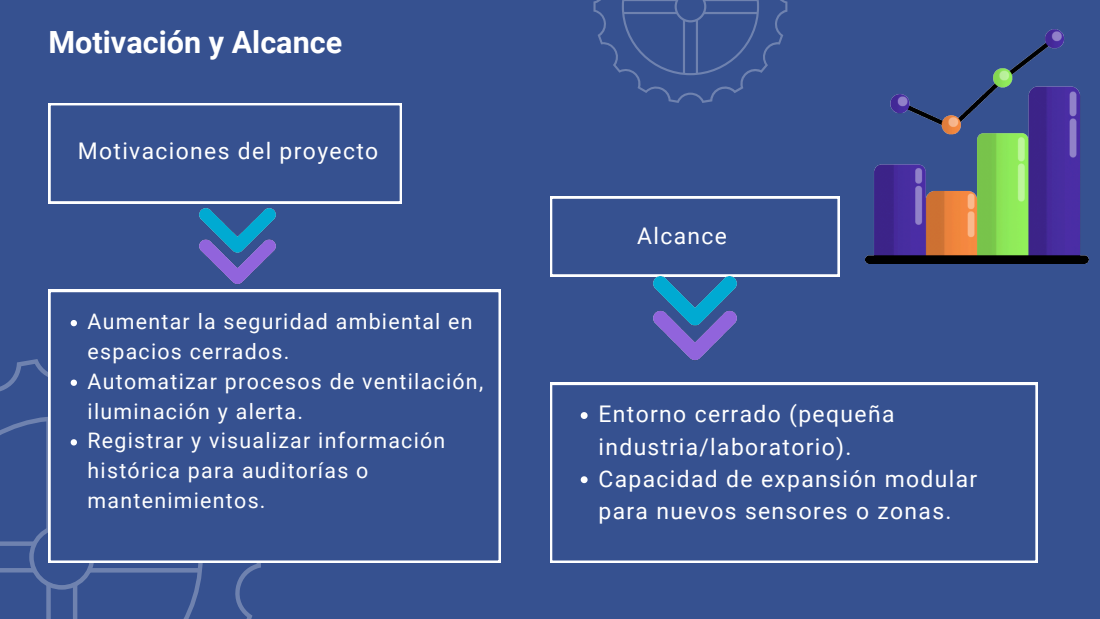
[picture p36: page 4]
Alcance

Motivaciones del proyecto

Aumentar la seguridad ambiental en
espacios cerrados.
Automatizar procesos de ventilación,
iluminación y alerta.
Registrar y visualizar información
histórica para auditorías o
mantenimientos.

Entorno cerrado (pequeña
industria/laboratorio).
Capacidad de expansión modular
para nuevos sensores o zonas.

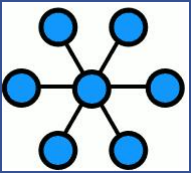
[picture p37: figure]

## Arquitectura General del Sistema

SENSORES DISTRIBUIDOS (NODOS) → NODO CONCENTRADOR → SERVIDOR REMOTO.

Sensores y Controladores Edge
Los sensores miden variables críticas y envían los datos a controladores edge, que pueden accionar dispositivos como extractores de aire, luces, alarmas sonoras y balizas luminosas.

Comunicación LoRa y Nodo Concentrador
Los controladores edge se comunican mediante un enlace LoRa hacia un nodo concentrador, formando una red de tipo estrella. Este nodo envía los datos recolectados a un broker MQTT remoto para su posterior análisis y almacenamiento.

Servidor en la Nube y Dashboard
Toda la información recolectada se analiza en un servidor remoto y se almacena en una base de datos. Luego, se muestra en un dashboard que permite visualizar la información procesada y enviar órdenes automáticas o comandos indicados por el usuario.

## Componentes principales

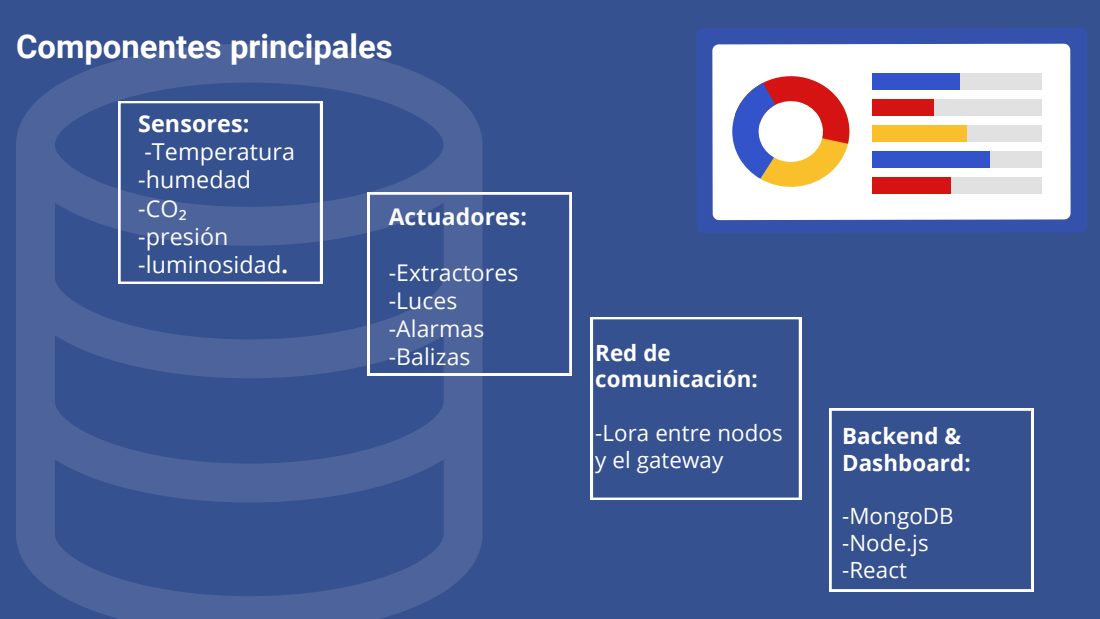
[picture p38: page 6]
Sensores: -Temperatura -humedad -CO₂ -presión -luminosidad.; Actuadores:; -Extractores -Luces -Alarmas; -Balizas; Red de; Backend & Dashboard:; -MongoDB -Node.js -React

comunicación:
-Lora entre nodos
y el gateway

## Hardware Utilizado

Componente | Función

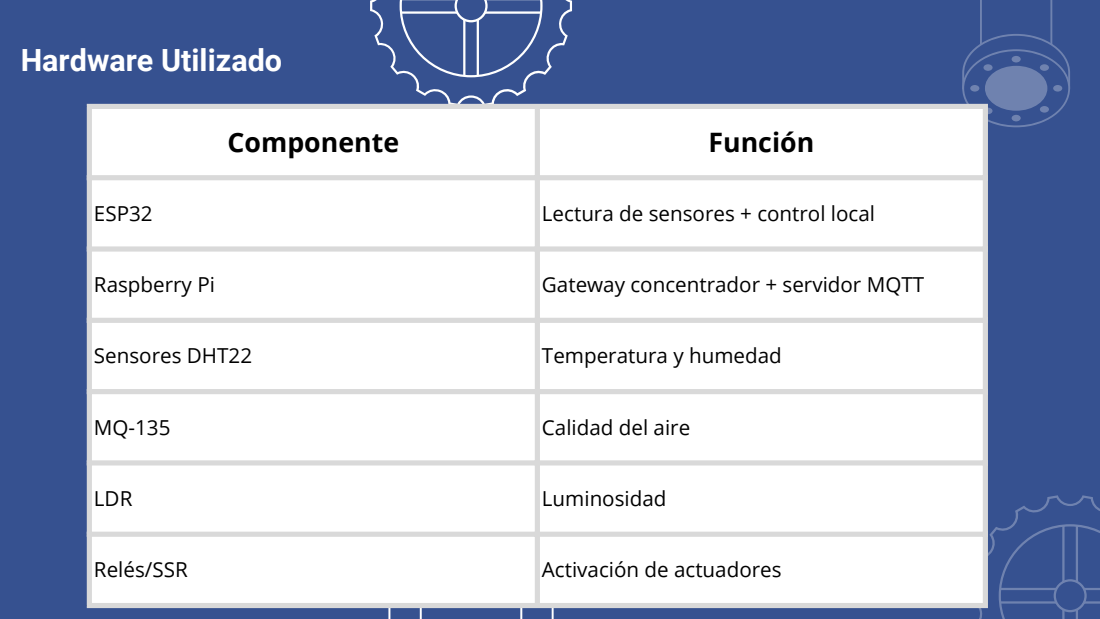
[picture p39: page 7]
ESP32; Lectura de sensores + control local; Raspberry Pi; Gateway concentrador + servidor MQTT; Sensores DHT22; Temperatura y humedad; Calidad del aire; LDR; Luminosidad; Relés/SSR; Activación de actuadores

### Red LoRa:

## Comunicaciones

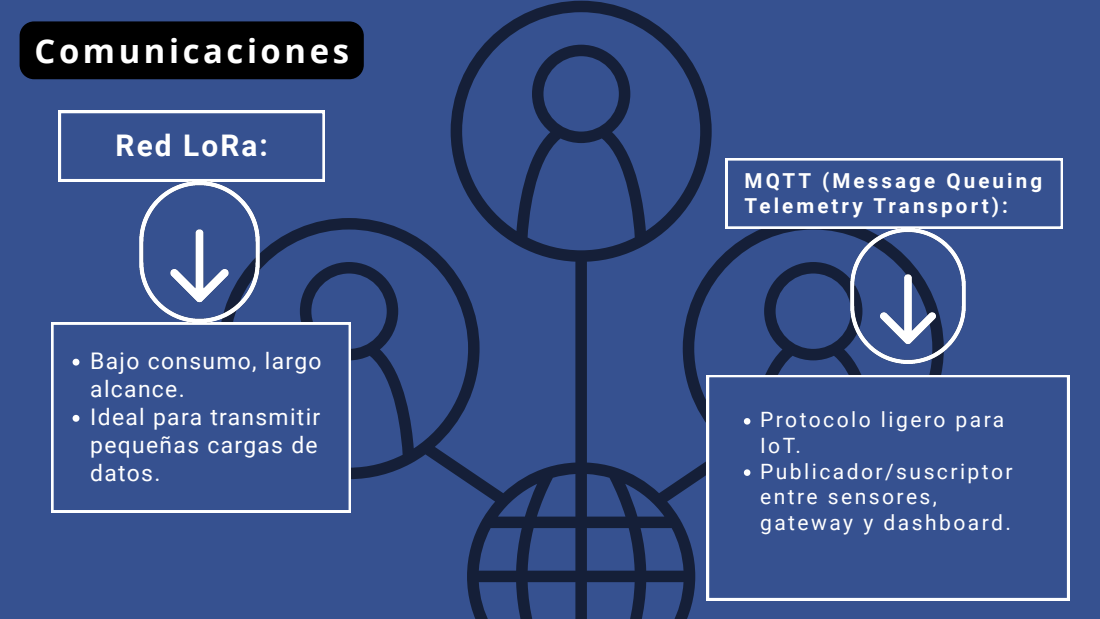
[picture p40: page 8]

Bajo consumo, largo
alcance.
Ideal para transmitir
pequeñas cargas de
datos.

Protocolo ligero para
IoT.
Publicador /suscriptor
entre sensores,
gateway y dashboard.

## Backend y Base de Datos

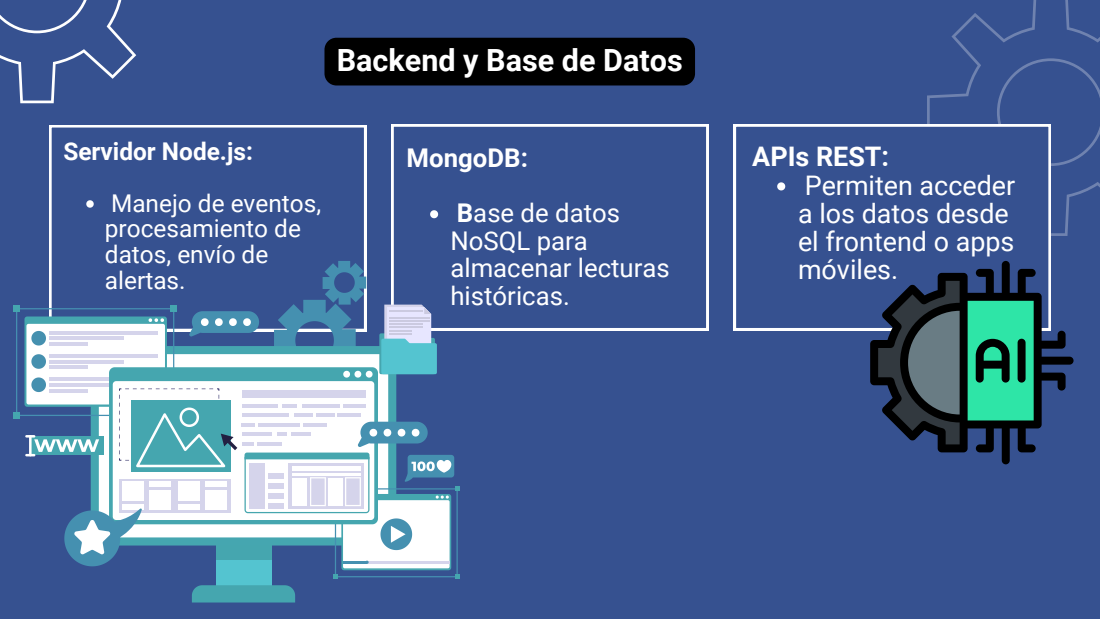
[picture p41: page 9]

Servidor Node.js:
Manejo de eventos,
procesamiento de
datos, envío de
alertas.

MongoDB:
Base de datos
NoSQL para
almacenar lecturas
históricas.

APIs REST:
Permiten acceder
a los datos desde
el frontend o apps
móviles.

## Interfaz de Usuario

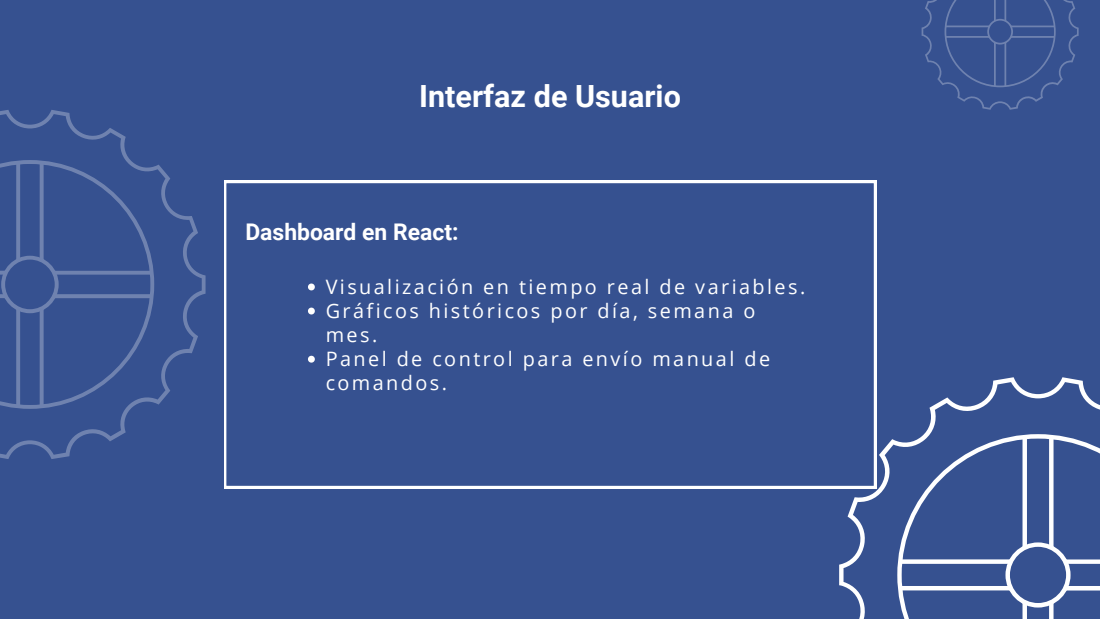
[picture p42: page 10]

Dashboard en React:

Vi suali zac ión en tiempo real de var iables .
Gráfi cos hi s tór i cos por día, semana o
mes .
Panel de cont rol para envío manual de
comandos .

## Automatización y Alertas

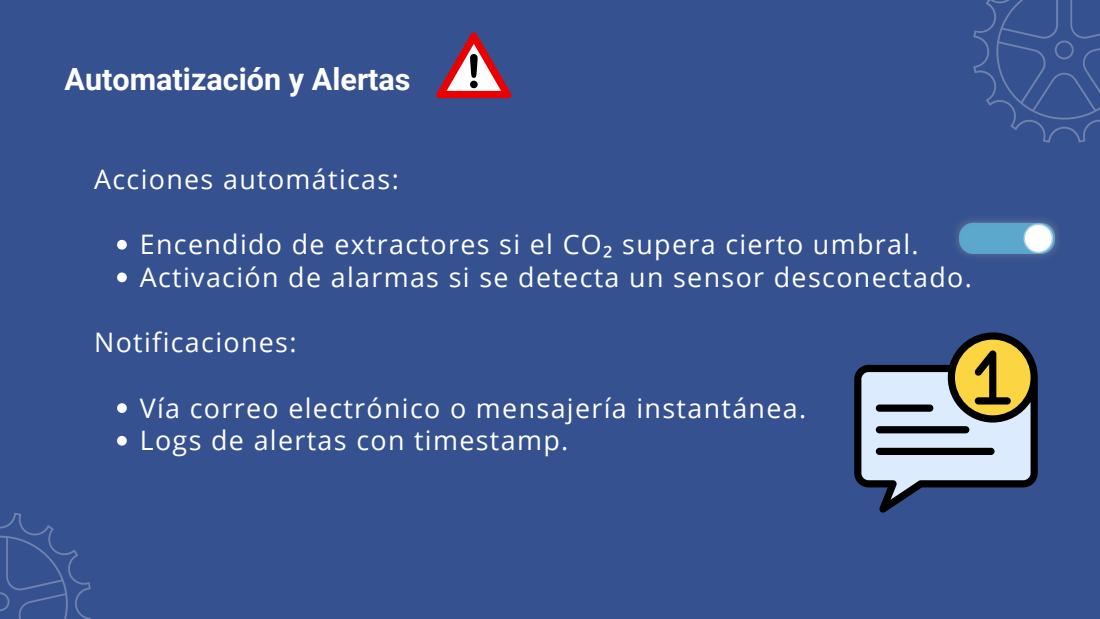
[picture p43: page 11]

Acciones automáticas:
Encendido de extractores si el CO₂ supera cierto umbral.
Activación de alarmas si se detecta un sensor desconectado.
Notificaciones:
Vía correo electrónico o mensajería instantánea.
Logs de alertas con timestamp.

### Pruebas de campo:

## Pruebas y Validación

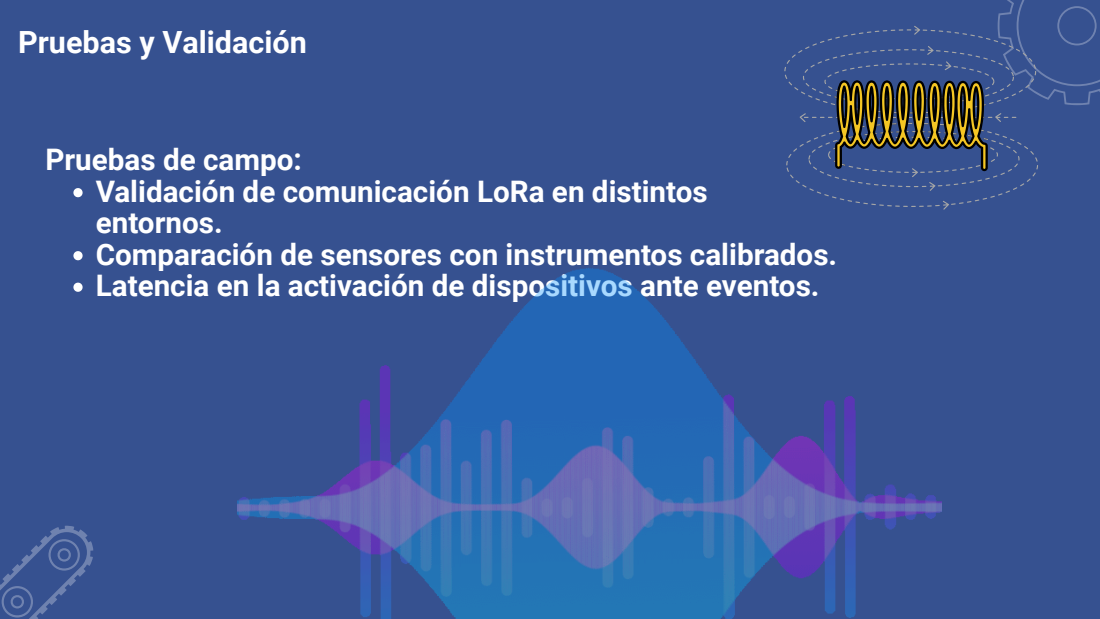
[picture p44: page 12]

Validación de comunicación LoRa en distintos
entornos.
Comparación de sensores con instrumentos calibrados.
Latencia en la activación de dispositivos ante eventos.

## Fases del Proyecto


Fase 1 - Iniciación del Proyecto: Establecimiento de la documentación inicial y
definición de la arquitectura general.
Fase 2 - Prototipo Sensado y Control:
Fase 3 - Integración y Pruebas: Verificación de la interoperabilidad entre los
diferentes módulos del sistema.
Fase 4 - Documentación y Escalado: Completar la documentación técnica y planificar
siguientes iteraciones.
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

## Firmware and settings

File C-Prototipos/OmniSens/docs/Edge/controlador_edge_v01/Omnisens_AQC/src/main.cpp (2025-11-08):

//nodo "control_edge"

#include <Arduino.h>
#include <LoRa.h>
#include <SPI.h>
#include <Wire.h>
#include <Ticker.h>
#include "MQ135Sensor.h"
#include "AHT25Sensor.h"
#include "BMP280Sensor.h"
//#include "Baliza_con.h"
#include "LDRSensor.h"
#include "SalidaPWM.h"
#include "SalidasRele.h"
//#include "LoRaComm.h"
#include "SensorData.h"
#include "DatoJson.h"

// Pines LoRa (ajusta según tu hardware)
#define LORA_CS   5
#define LORA_RST  14
#define LORA_INT  26

// Configuración de Pines sensores/actuadores
#define MQ135_PIN 39
#define PWM_PIN 32
#define RELE_1 33
#define RELE_2 25
#define WS2812_PIN 27
#define LDR_PIN 36


// Instancias globales
MQ135Sensor mq135(MQ135_PIN);
AHT25Sensor aht25;
BMP280Sensor bmp280;
//Baliza_con baliza(WS2812_PIN);
LDRSensor ldr(LDR_PIN);
SalidaPWM vel_motor(PWM_PIN);
SalidasRele salidas(RELE_1, RELE_2);



// LoRa
const String NODE_ID = "AQC_001";
//const char* AUTH_TOKEN = "clave123";
//LoRaComm lora(433E6); 

//SensorData 
SensorData sensorData(NODE_ID, &mq135, &bmp280, &aht25, &ldr, &salidas, &vel_motor);
DatoJson datoJson;

Ticker envioTicker; // Ticker para enviar datos

volatile bool enviarFlag = false;

// Callback para recibir mensajes LoRa
volatile bool msgFlag = false;
String msgLoRa = "";

void onReceive(int packetSize) {
    if (packetSize == 0) return; // No hay datos

    String incoming;
    while (LoRa.available()) {
        incoming += (char)LoRa.read();
    }
    msgLoRa = incoming;
    msgFlag = true;
}

// --- SETUP ---
void setup() {
    Serial.begin(115200);
    delay(1000);

    Serial.println("[Sistema] Inicializando...");
    Serial.println("[Sistema] Configurando pines LoRa ...");

    // Inicialización manual de SPI (por seguridad)
    SPI.begin(18, 19, 23, LORA_CS);

    // Seteo explícito de pines (aunque LoRaComm ya los usa por defecto)
    LoRa.setPins(LORA_CS, LORA_RST, LORA_INT);
    Serial.println("[Sistema] Pines LoRa configurados");
    Serial.println("[Sistema] Inicializando modulo comunicacion LoRa ...");

    if (LoRa.begin(433E6)) {
        Serial.println("[Sistema]LoRa inicializado correctamente");
    } else {
        Serial.println("[Sistema] Fallo al iniciar LoRa");
    }
    
    LoRa.setSpreadingFactor(12);
    LoRa.setSignalBandwidth(125E3);
    LoRa.setCodingRate4(5);
    LoRa.setTxPower(20); // Ajusta la potencia de transmisión según sea necesario
    LoRa.enableCrc(); // Habilita CRC para mayor fiabilidad
    //LoRa.onReceive(onReceive);
    LoRa.receive();  // listo para recibir


    Serial.println("[Sistema] Inicializando comunicacion I2C ...");
    
    // Inicialización de Wire (I2C) si es necesario
    Wire.setPins(21, 22);  // Ajusta los pines SDA y SCL según tu hardware
    Wire.begin();
    Serial.println("[Sistema] I2C inicializado");

    Serial.println("[Sistema] Iniciando sensores AHT25 y BMP280");
    if (!aht25.begin()) {
        Serial.println("[Sistema] Error al iniciar el sensor AHT25");
    } else {
        Serial.println("[Sistema] Sensor AHT25 inicializado correctamente");
    }
    if (!bmp280.begin()) {
        Serial.println("[Sistema] Error al iniciar el sensor BMP280");
    } else {
        Serial.println("[Sistema] Sensor BMP280 inicializado correctamente");
    }

    Serial.println("[Sistema] Iniciando sensor MQ135");

    if (!mq135.begin()) {
        Serial.println("[Sistema] Error al iniciar el sensor MQ135");
    } else {
        Serial.println("[Sistema] Sensor MQ135 inicializado correctamente");
    }


    Serial.println("[Sistema] Iniciando sensor LDR");
    ldr.begin();

    Serial.println("[Sistema] Inicializando salida PWM");
    vel_motor.begin();
    vel_motor.comandoPWM(0); // Inicializa el PWM en 0% de forma explicita
    
    Serial.println("[Sistema] Inicializando salidas de relé");
    salidas.begin();
    //baliza.begin();
    delay(1000); // Espera para asegurar que todo esté listo
    // Timer cada 5s
    envioTicker.attach(5, []() {enviarFlag = true;});

    Serial.println("[Sistema] Inicialización completa");
}

// --- LOOP ---
void loop() {
  
  //-----------------prueba sin callbacks--------------------
  
  // 1) primero, chequeo de paquetes entrantes
  //LoRa.idle(); // Asegurar que LoRa está en modo escucha
  int packetSize = LoRa.parsePacket();
  if (packetSize > 0) {
    String incoming;
    while (LoRa.available()) {
      incoming += (char)LoRa.read();
    }
    Serial.println("[LoRa] Comando recibido: " + incoming);

    uint8_t pwm; bool r1, r2; uint8_t cod;
    if (datoJson.procesarOrdenes(incoming, NODE_ID, pwm, r1, r2, cod)) {
      vel_motor.comandoPWM(pwm);
      salidas.setRele1(r1);
      salidas.setRele2(r2);
      Serial.printf("[Acción] PWM=%d R1=%d R2=%d Al=%d\n", pwm, r1, r2, cod);
    } else {
      Serial.println("[LoRa] Comando ignorado");
    }
  }

  // 2) envío periódico (igual que antes)
  if (enviarFlag) {
    enviarFlag = false;
    delay(50);
    String json = sensorData.toJSON();
    LoRa.beginPacket();
      LoRa.print(json);
    LoRa.endPacket(false);
    delay(150);          // pequeño espacio antes de volver a recibir
    Serial.println("[LoRa] Datos enviados");
    LoRa.receive();     // Volver a modo recepción
  }

  //-----------------------------------------------------------------------------

  /*   // 1) Atender comandos entrantes
  if (msgFlag) {
    msgFlag = false;
    Serial.println("[LoRa] Comando recibido: " + msgLoRa);
    uint8_t pwm; bool r1,r2; uint8_t cod;
    if (datoJson.procesarOrdenes(msgLoRa, NODE_ID, pwm, r1, r2, cod)) {
      vel_motor.comandoPWM(pwm);
      salidas.setRele1(r1);
      salidas.setRele2(r2);
      Serial.printf("[Acción] PWM=%d R1=%d R2=%d Al=%d\n", pwm, r1, r2, cod);
    } else {
      Serial.println("[LoRa] Comando ignorado");
    }
  }

    // 2) Enviar datos periódicos
  if (enviarFlag) {
    enviarFlag = false;

    // Dar un breve margen para no solapar envío/recepción
    delay(50);

    String payload = sensorData.toJSON();
    Serial.println("[JSON] " + payload);

    LoRa.beginPacket();
      LoRa.print(payload);
    LoRa.endPacket();       // Tx
    Serial.println("[LoRa] Datos enviados");
    LoRa.receive();         // Volver a modo Rx
  } */


}

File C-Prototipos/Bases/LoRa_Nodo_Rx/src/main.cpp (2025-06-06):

#include <WiFi.h>
#include <PubSubClient.h>
#include <SPI.h>
#include <LoRa.h>


// Pines LoRa
#define LORA_SCK 18
#define LORA_MISO 19
#define LORA_MOSI 23
#define LORA_SS 5
#define LORA_RST 14
#define LORA_DIO0 26

#define RELAY_PIN 27  // Simula el relay con un LED

// WiFi y MQTT
const char* ssid = "Fibertel-WiFi032";
const char* password = "vuelalto@67";
const char* mqtt_server = "telecomunicaciones.ddns.net";  // o tu IP/localhost
const int mqtt_port = 2480;
const char* mqtt_topic = "omnisens/datos/AQC_001";

WiFiClient espClient;
PubSubClient client(espClient);

//IPAddress local_IP(192, 168, 0, 75);
//IPAddress gateway(192, 168, 0, 1);
//IPAddress subnet(255, 255, 255, 0);

void connectWiFi() {
  
  WiFi.begin(ssid, password);
  Serial.print("Conectando a WiFi...");
  while (WiFi.status() != WL_CONNECTED) {
    delay(500);
    Serial.print(".");
  }
  Serial.println("\nWiFi conectado");
}

void reconnectMQTT() {
  while (!client.connected()) {
    Serial.print("Conectando a MQTT...");
    if (client.connect("ESP32Client")) {
      Serial.println("conectado!");
    } else {
      Serial.print("falló, rc=");
      Serial.print(client.state());
      Serial.println(" intentando de nuevo en 5s");
      delay(5000);
    }
  }
}

void setup() {
  Serial.begin(115200);
  while (!Serial);

  pinMode(RELAY_PIN, OUTPUT);
  digitalWrite(RELAY_PIN, LOW); // Apagado al inicio

  // Configurar LoRa
  LoRa.setPins(LORA_SS, LORA_RST, LORA_DIO0);

  if (!LoRa.begin(433E6)) {
    Serial.println("Fallo al iniciar LoRa");
    while (1);
  }

  Serial.println("Nodo Receptor iniciado...");

   // WiFi + MQTT
  //WiFi.config(local_IP, gateway, subnet);
  connectWiFi();
  client.setServer(mqtt_server, mqtt_port);
  client.connect("ESP32Client");
}

void loop() {


  client.loop();

  int packetSize = LoRa.parsePacket();
  if (packetSize) {
    String incoming = "#";
    while (LoRa.available()) {
      incoming += (char)LoRa.read();
    }

    Serial.print("Mensaje recibido: ");
    Serial.println(incoming);

    // PUBLICAR MENSAJE A MQTT
    client.publish(mqtt_topic, incoming.c_str());

    // Analizar datos. Supongamos que recibimos: "Temp:31 Hum:60"
    if (incoming.indexOf("Temp:") != -1) {
      int tempIndex = incoming.indexOf("Temp:") + 5;
      int spaceIndex = incoming.indexOf(' ', tempIndex);
      String tempStr = incoming.substring(tempIndex, spaceIndex);
      float temp = tempStr.toFloat();

      if (temp > 30) {
        digitalWrite(RELAY_PIN, HIGH); // Activa relay
        Serial.println(">>> Relay ON (Temp alta)");
      } else {
        digitalWrite(RELAY_PIN, LOW);
        Serial.println(">>> Relay OFF (Temp normal)");
      }
    }
  }
}

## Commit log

2025-04-14 Se inicia el repositorio para proyecto Modulo Programador IoT Fullstack
2025-05-25 Actualizo Readme.md con descripción detallada del sistema OmniSens
    Se actualizó el archivo Readme.md para reflejar la descripción, objetivos, arquitectura y componentes del sistema OmniSens, orientado al monitoreo y control ambiental en entornos industriales.
    Los cambios principales incluyen:
    - Nueva introducción sobre el propósito y alcance de OmniSens.
    - Detalle de la arquitectura basada en sensores, microcontroladores LoRa, controlador de actuadores y servidor en la nube.
    - Explicación del flujo de datos y los componentes principales del sistema.
    - Nueva estructura de carpetas sugerida y aclaración sobre integración y escalabilidad.
    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
2025-05-25 Actualizacion Roadmap
    Actualizo la Hoja de Ruta (Roadmap) en base al desarrollo del proyecto
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2025-05-28 Actualizo readme con cambios en la descripcion del proyecto
2025-05-28 agrego propuesta de issues
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2025-06-01 Se Agregan los archivos de modelos 3D del prototipo de la baliza con LDR y LoRa.
    [Tapa_superior_con_ventana.3mf, Tapa_superior_con_ventana.STL, Tapa_superior_con_ventana.sldprt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]
2025-06-03 feat(API)
    - Estructura inicial de la API OmniSens para plataforma IoT.
    - Soporte para ingesta de datos desde MQTT (sensores y actuadores), almacenamiento en MariaDB y consulta vía endpoints REST.
    - Implementación de autenticación por clave API y validación contra base de datos.
    - Endpoints para consulta de dispositivos, datos históricos y últimos datos, así como envío de comandos a dispositivos vía MQTT.
    - Esquema SQL para todas las tablas principales (devices, sensor_data, actuator_status, commands_log, api_users).
    - Configuración flexible por variables de entorno (.env).
    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
2025-06-05 Actualizada documentación técnica de dispositivos Edge en OmniSens
    Actualizada documentación técnica de dispositivos Edge en OmniSens
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2025-06-08 Actualización de la API OmniSens: endpoints REST, autenticación, integración MQTT y documentación
    Se actualiza estructura de la API RESTful para OmniSens usando Express.
    Se agregan endpoints para listar dispositivos, obtener datos de dispositivos y enviar comandos a través de MQTT.
    Se integra autenticación por API Key en todas las rutas.
    Se crea la lógica de conexión y publicación MQTT, así como la suscripción a tópicos de datos.
    Se implementan servicios y controladores para interacción con la base de datos y el broker MQTT.
    Se añade archivo .env de ejemplo y configuración de variables sensibles.
    Se documenta la API en README.md, incluyendo ejemplos de uso y estructura de resp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
2025-06-08 Documentación y comentarios exhaustivos en código backend de la API de OmniSens
    - Se agregaron comentarios detallados en todos los archivos del backend d la API (configuración, controladores, middleware, rutas, servicios y servidor).
    - Los comentarios explican la función de cada sección, bloque, variable y función relevante, facilitando la comprensión y el mantenimiento del código.
    - No se realizaron cambios funcionales en la lógica del backend, solo mejoras de documentación y claridad.
2025-06-08 Estructura de la nueva API OmniSens y servicios principales
    - Se crea la carpeta "API (nueva)" con la estructura para la API RESTful de OmniSens.
    - Se agregan subcarpetas: src/config, src/controllers, src/routes, src/service, src/middleware.
    - Se implementan los servicios principales: conexión a base de datos MariaDB, integración con broker MQTT (con soporte MQTTS), y endpoints REST para consulta y comandos a dispositivos.
    - Se incluye manejo centralizado de errores, configuración por variables de entorno (.env), y documentación básica en README.md.
    - Se añade soporte para HTTPS y seguridad con Helmet.
    - Se ignora el archivo .env y node_modules en .gitignore.
    - Estructura lista para de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
2025-06-08 Comentarios explicativos y documentación mejorada en la API (nueva)
    - Se agregaron comentarios detallados en castellano en todos los archivos fuente principales de la API (nueva), incluyendo controladores, servicios, rutas, configuración y servidor principal, para fa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
    - Se mejoró la estructura y claridad de cada sección, explicando el propósito y funcionamiento de funciones, middlewares, eventos y parámetros de configuración.
    - Estos cambios mejoran la mantenibilidad y la curva de aprendizaje para nuevos desarrolladores del proyecto OmniSens.
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2025-06-08 Implementación de autenticación por API Key y documentación mejorada en la carpeta "API (nueva)"
    - Se agregó un middleware de autenticación por API Key para proteger todos los endpoints REST de dispositivos.
    - Se actualizó el archivo .env para incluir la variable API_KEY y se documentó su uso.
    - Se mejoró la documentación en README.md, agregando una sección de autenticación, ejemplos de uso con curl y Node.js (axios) mostrando cómo enviar la API Key.
    - Se garantiza que todas las rutas críticas requieren autenticación, alineando la seguridad con buenas prácticas.
    - Se mantiene la estructura modular y segura, lista para producción.
    Este commit refuerza la seguridad de la API y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
2025-06-09 fix API OmniSens
    Corrección de errores en la implementación de la API
2025-06-09 Corrección archivo "databaseService.js"
    Se corrigió el archivo "databaseService.js" ubicado en la carpeta "service"
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2025-06-09 API OmniSens: Seguridad, endpoints REST, métricas Grafana y documentación mejorada
    - Se agregaron endpoints REST para métricas de usuarios, pensados para integración directa con Grafana:
    - `/api/users/count`: Devuelve la cantidad total de usuarios registrados.
    - `/api/users`: Devuelve el listado de usuarios (id, username, fecha de creación).
    - `/api/users/new?from=YYYY-MM-DD&to=YYYY-MM-DD`: Devuelve la cantidad de nuevos usuarios en un rango de fechas.
    - `/api/grafana/users/count`, `/api/grafana/users`, `/api/grafana/users/new-by-day`: Endpoints alternativos para consultas directas desde dashboards.
    - Se crearon los controladores y servicios necesarios para la gestión y consult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
2025-06-09 Se elimina la API obsoleta
    Elimino la carpeta "api (adaptada)" la cual quedo obsoleta con los últimos cambios realizados en el proyecto
2025-06-10 Actualizo los archivos "Readme.md"
    Actualizo los archivos "Readme.md" principal y de cada carpeta del repositorio
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2025-06-10 Agrego a los profesores
    Agrego los nombres, apellidos y nombre de usuario y enlace al GitHub de los profesores
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2025-06-12 Mensaje de funcionamiento de la API
    Se crea un mensaje de bienvenida cuando esta en funcionamiento la API
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
